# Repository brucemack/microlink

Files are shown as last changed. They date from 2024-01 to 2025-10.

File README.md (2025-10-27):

# Overview

Is it possible to build a full EchoLink&reg; node using a $6 microcontroller?  I'm not completely sure, but
let's find out. The goal of this project is to create the smallest, 
cheapest way to put a radio onto the EchoLink network. If you are new 
to the world of EchoLink please 
[see the official website](https://www.echolink.org/) for complete information. EchoLink is a 
peer-to-peer VoIP (voice over IP) network used to link amateur radio stations across
the Internet.

There are much easier ways to get onto EchoLink. The MicroLink project will only
be interesting to someone who wants to get deep into the nuts-and-bolts of EchoLink/VoIP technology. In fact, you 
should start to question the sanity of anyone who spends this much time building their own EchoLink station. I am a homebrew enthusiast and I try to avoid off-the-shelf software/components where 
possible. This has been a huge learning opportunity.

The system currently runs on a Pi Pico W (RP204, ARM Cortex M0) board. I'm pretty sure it 
could also run on an ESP-32, or possibly an Arduino of sufficient caliber. More experimentation
is needed here.

The software is fully open source. Now that EchoLink is "open," others can experiment with this 
important amateur radio technology. I am currently working on adding support for [AllStarLink](https://www.allstarlink.org/). More 
to follow ...

Here's my production setup at the moment. This station provides EchoLink access to the Wellesley Amateur 
Radio Society repeater (W1TKZ-L) using a Yaesu FT-1900:

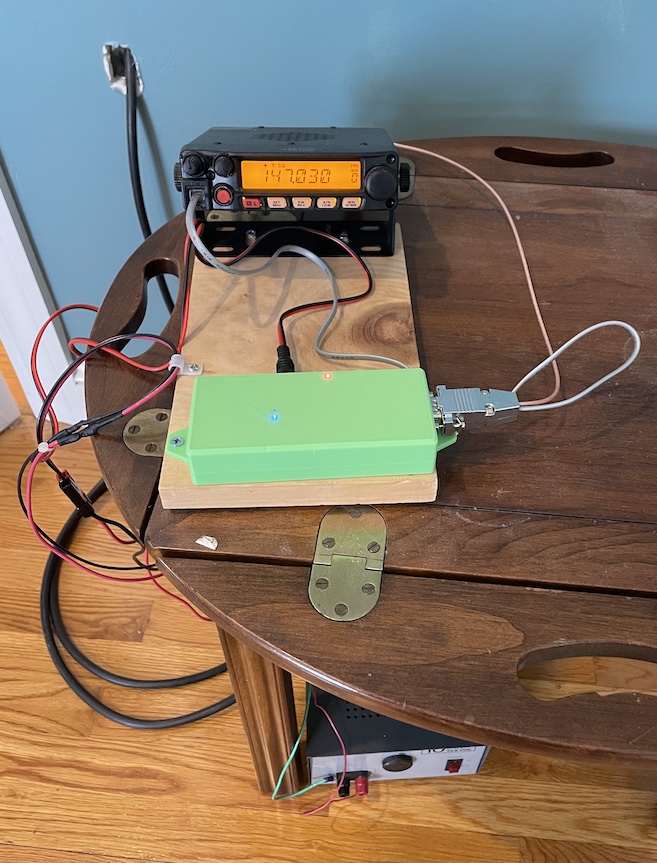
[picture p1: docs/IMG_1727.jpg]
MicroLink Station Picture


The green case contains the MicroLink system. The DB9 connector on the side of the 
case connects to microphone and audio plugs on the FT-1900. A 12V supply powers the radio and the MicroLink interface.
Note that there are no other computers required.  The only
things not shown in this picture are the antenna (on the roof), and the home WIFI network that the Pico W is connected to.  The red LED is the 12V 
power indicator and the blue LED is the 
internet connection status.

Here's a demo video I made of the first bench test:

MicroLink Transmit and Receive Demo (https://www.youtube.com/watch?v=wqWCYG_9o4k)

The microphone/analog section still needs some work. 

Here's what it sounds like over the air:

MicroLink OTA Demo (https://www.youtube.com/watch?v=BMkJOykSL_8)

The official 
PC-based EchoLink client written by Jonathan Taylor (K1RFD) is excellent and is the quickest/easiest way to get on 
EchoLink. [Download it here](https://www.echolink.org/download.htm). There are also versions that run on mobile phones. MicroLink is not a supported part of the EchoLink family 
of products.

I've learned many things about EchoLink during this project. One thing is for sure: Jonathan (K1RFD) 
who created the EchoLink system is an outstanding engineer and we should all be greatly 
appreciative of the work
that he and the rest of the EchoLink team do on behalf of the amateur radio community. Thanks to 
Jonathan for his suggestions/advice along the way.

Huge thanks go to Steve Kondo (K1STK) for providing the mechanical design work
for this project.

Thanks also to Julius Jones (W2IHY), creator of the world-famous EQPlus and other sophisticated audio gear, for his
advice on the audio circuit.

I have a few extra boards which I would be willing to sell
for a reasonable price if someone wanted to try to build 
a station of their own.

I am [good in QRZ at KC1FSZ](https://www.qrz.com/db/kc1fsz) if you have any questions or suggestions.  Or e-mail at bruce at mackinnon dot com.

# Architecture Overview/Parts

My goal was to build a complete station from scratch, with no strings attached to PCs/servers.  

I have made a PCB for 
ease of use with radios (link mode) and/or direct integration with repeaters. Further refinements
of the PCB are in process. The [latest Gerbers are here](hw/ML4/plot/ML4.zip) and 
the [latest BOM is here](hw/ML4/ML4-bom.csv). You can build one yourself.

This project required an in-depth examination of how the EchoLink protocol works. [The notes
I created during this analysis are located here](https://github.com/brucemack/microlink/blob/main/docs/el_supplement.md). The reverse-engineering of the EchoLink protocol was the 
most time-consuming part of the project.

## Current Parts List (HW)

* The main processor is a Pi Pico W (RP2040) development board. This includes WIFI 
connectivity.  $6.00 on DigiKey. 
* A 4G cellular data option is available using a SIM7600 module. *(Not fully working yet.)*
* Audio output generation uses the MicroChip MCP4725 I2C digital-to-analog converter.  $1.27 on DigiKey.
* Audio input sampling uses the integrated ADC in the RP2040.
* Isolation transformers and optocouplers are used to eliminate the need for a common ground 
between the radio and the MicroLink system. The 
radio and the MicroLink circuitry are completely isolated from each other. This helps to reduce digital noise. 
* The radio link is an ~~AZDEN PCS-6000H~~ Yaesu FT-1900 mobile rig.
* When not using the radio:
  - Audio amplification uses the LM4862M 825mW amplifier.  $2.23 on DigiKey.
  - The local T/R key is from Federal Telephone and Telegraph Company (Buffalo, NY), made in 1920.  Priceless.
  - The microphone is an electret condenser with a LVM321 pre-amp and low-pass anti-aliasing 
filter.  The microphone part needs work. The next revision will use a TLV9161 op amp for the 
microphone pre-amp to reduce noise.

Here's a picture of the the current version of the PCB.  

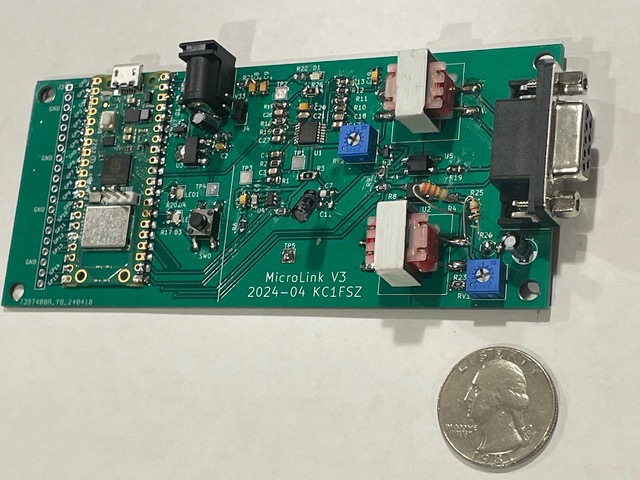
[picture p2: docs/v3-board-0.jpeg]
MicroLink Board V0


This is a picture of the cellular module.  This has passed some initial tests, but is not ready for production yet.

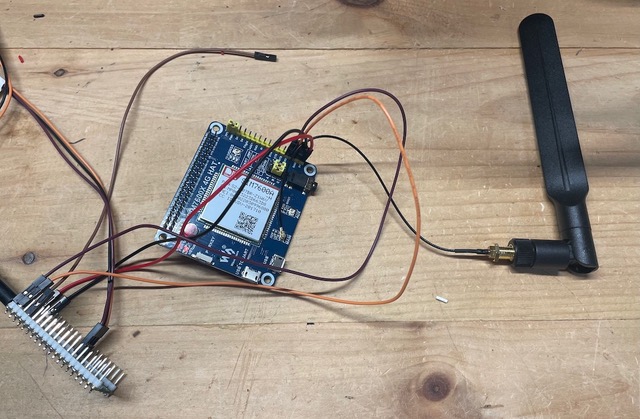
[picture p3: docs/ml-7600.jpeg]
MicroLink Cellular Connection


## Current Parts List (SW)

* The main station firmware is completely homebrew (C++, see GitHub repo).
* The LwIP embedded TCP/IP stack is used for IP connectivity on the Pi Pico W.
* Importantly, audio compression/decompression uses a GSM 06-10 Full Rate CODEC which is homebrew 
in C++. Getting that to work required studying
the European Telecommunications Standards Institute specification for GSM and a lot of testing,
but this was extremely interesting.
* I'm not using the Arduino development environment for this project. The toolchain is 
CMake/GCC/GDB using the Pico W 
SDK. I like this environment a lot. The firmware is flashed via SWD using [openocd](https://openocd.org/).

MicroLink identifies itself using a version string of **0.02MLZ**.

## Analog Schematics

**Microphone Pre-Amp**

Performance audio circuits are not my forte.  The quality is improving with each 
iteration.  This is what I built originally, but a new version using parts with better noise 
specs is in the works. 

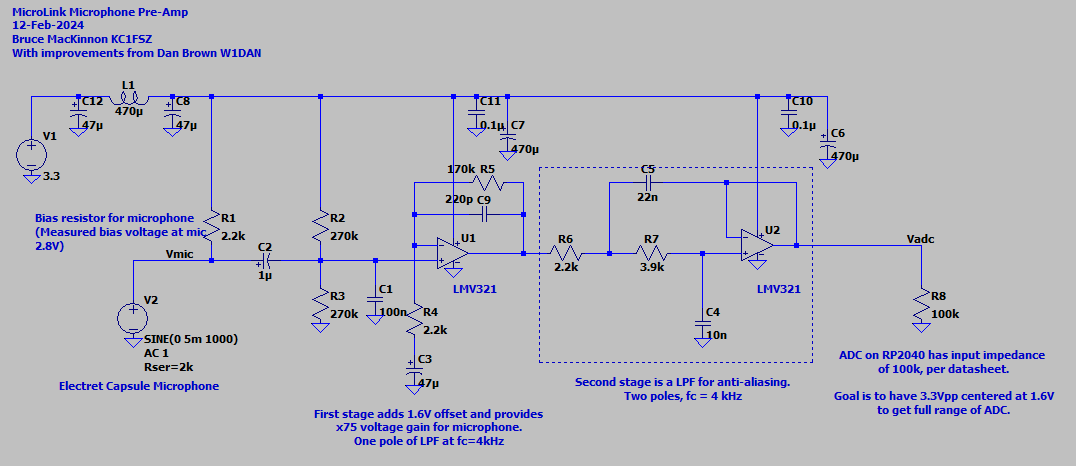
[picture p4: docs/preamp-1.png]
Audio Preamp Schematic


The microphone part will not be used when the radio is integrated. I will probably leave
the speaker/amplifier in for monitoring purposes.

**Audio Input**

This is the circuit used when connecting directly to a radio's AF output (i.e. no microphone). This repeats some of the circuit shown above (but minus the high gain). This also shows
the circuit used for carrier detect (COS). The idea is to boost up the rig's audio 
output (U6) and then compare it to an adjustable threshold (U8).  There is no debounce
in the analog part of the COS circuit - that is all done in software.

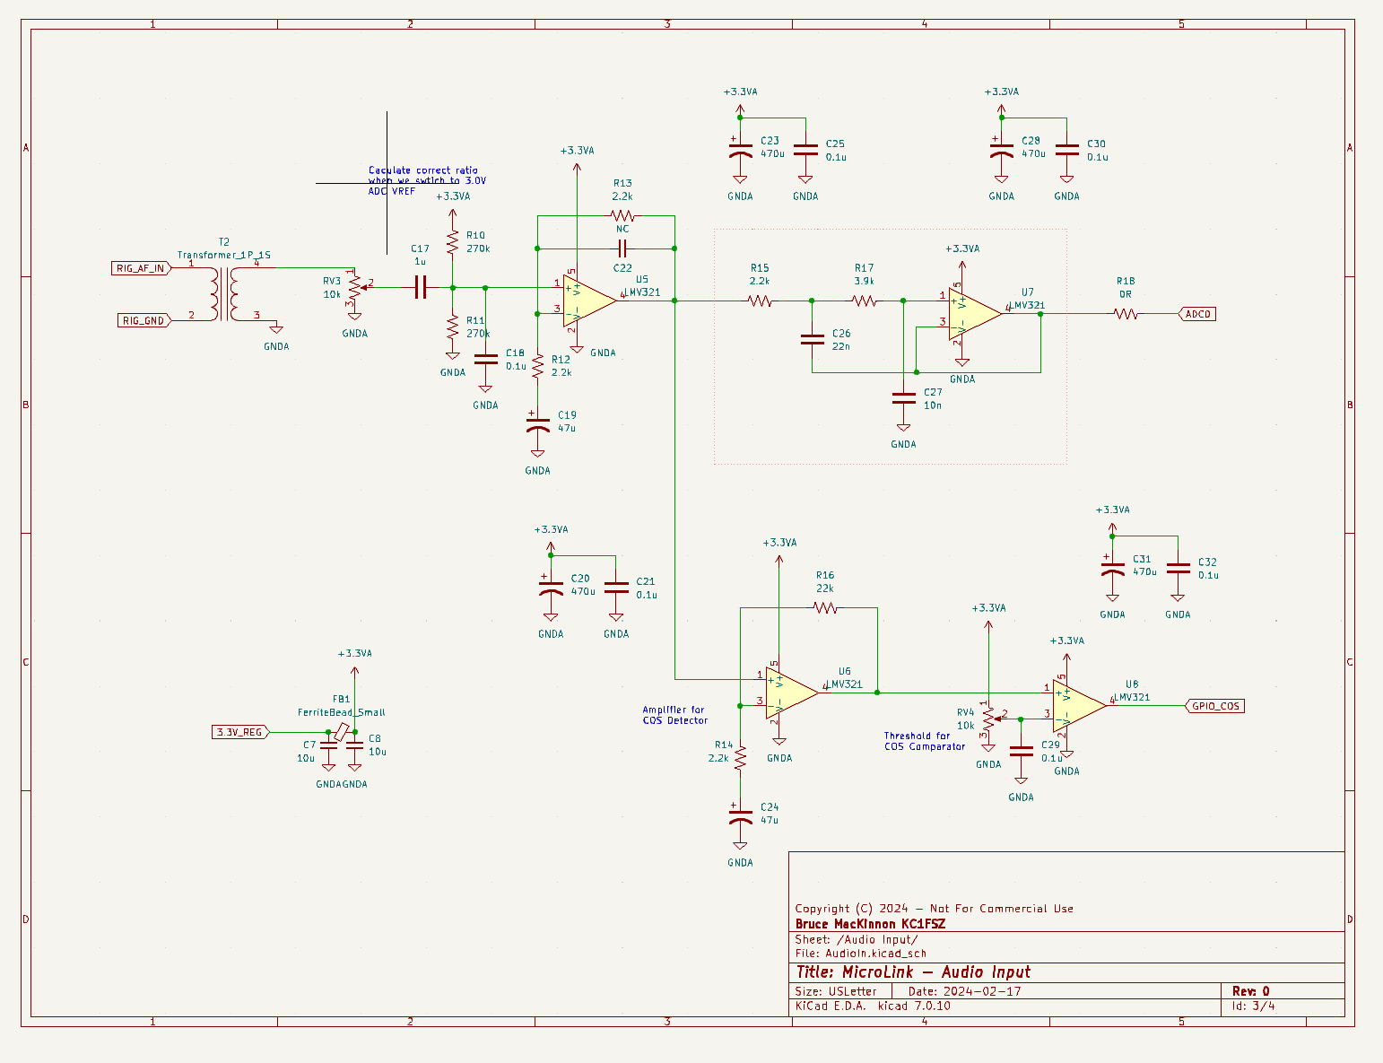
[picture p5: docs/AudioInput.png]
MicroLink Audio Input


**Audio Output**

This is a work in process. The performance on the low end of the audio spectrum is not good yet.

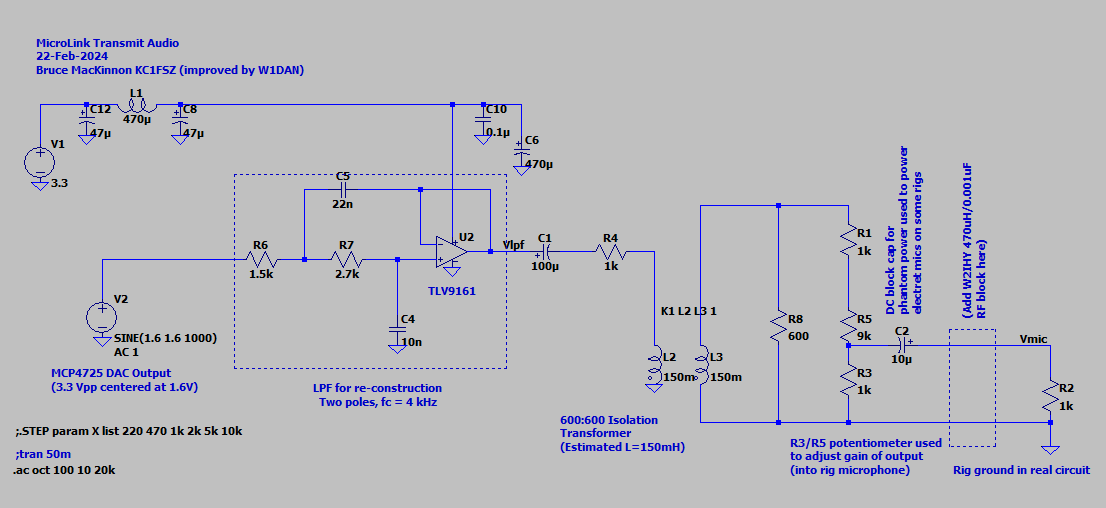
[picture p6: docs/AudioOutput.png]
MicroLink Audio Output


## Cellular Data Interface

I have a working version of the MicroLink system using 4G cellular internet 
connectivity using an SIM7600A cellular module.  The $70 USD breakout 
board for this module [comes from Waveshare and is linked here](https://www.waveshare.com/sim7600a-h-4g-hat.htm).  
The Waveshare module was originally designed to plug into a full Raspberry Pi (NOT A PICO!), hence the 
use of the term "hat," but it is possible to use the module directly via a serial 
interface and there is no technical requirement to connect it to a Raspberry Pi.

I am communicating with the module using their AT command set across a 115,200 baud serial link.  This 
requires a pretty elaborate
state machine to allow bi-directional UDP traffic across a protocol that was originally designed
so support auto-dialing modems.  The Hayes people would be shocked if they saw what people were
doing with AT commands.  I've had good luck getting the SIM7600 to maintain the UDP data rate needed to
support EchoLink.

I am using a pre-paid SIM card from [Mint Mobile](https://www.mintmobile.com/).  It turns out that 
not all cellular providers support the "raw" SIM7600 module.  In fact, it took a few conversations
with their help desk to get them to activate my SIM card.  The Mint Mobile activation website wants you to select
what kind of phone you have (i.e. iPhone, Android, etc.) and apparently "homebrew EchoLink station"
isn't a valid choice in their system yet.  Someday ... But after some back-and-forth, they activated my 
SIM and within 30 seconds the "link" LED started flashing and I was on the Internet!

The only bad thing about Mint Mobile is that they don't appear to allow inbound UDP traffic 
into this module. Or at least I've not figured that out yet.  ARRGG! This required the use of a 
TCP proxy to handle the traffic in/out of the cellular module.  I've not documented this part
yet because I am still hoping to eliminate this component.

### Notes on MVNOs

Mint Mobile is an example of what is called a "Mobile Virtual Network Operator," or MVNO for short.
The real mobile cellular infrastructure is built/run by Verizon, T-Mobile (including the remnants of 
Sprint), AT&T, and US Cellular. 
All of the other low-cost "providers" are essentially renting bandwidth from the big firms. In the
case of Mint Mobile, they are using the T-Mobile network.

One interesting facet of the MVMO service is that the traffic is de-prioritized vs. the "real" 
carrier's traffic.  So during congested times you might find that T-Mobile service is 
better than Mint Mobile's.  You get what you pay for.

The mechanics of the prioritization is managed through the assignment of QCI levels.  According to one 
article I saw, T-Mobile uses QCI 6, 7, 8, and 9 for their normal consumer plans.   *The lower numbers 
have higher priority.* T-Mobile uses 6 (the best) for their "real" customers (i.e. pre-paid subscribers) and 7 for 
Mint Mobile.  Interestingly, T-Mobile branded hot-spots run on level 9 (the worst).

## Notes on SNTP

MicroLink will update its internal time using an NTP server.  The main value of this is to 
ensure that the timestamps on the internal log messages are correct.

The SNTP message protocol is quite simple.  The request is 68 bytes, mostly zeros.  The non-zero
bytes are as follows:

* Byte 0: (binary) 00 100 011.  This denotes an SNTPv4 client request.
* Byte 1: zero
* Byte 2: 6
* Byte 3: 0xec
* Bytes 12-15: (ascii) UKNO
* Bytes 40-43: The client's current time in seconds since the Epoch, big endian format.

The response that comes back has been observed to be around 52 bytes, although this may
vary in some situations.  The important information in the response is:

* Byte 0: (binary) 00 100 100.  This denotes an SNTPv4 server response.
* Bytes 40-43: The server's current time in seconds since the Epoch, big endian format.

## Enclosure

Steve K1STK designed and fabricated a great enclosure on his 3D printer.  Here's what the PCB
looks like with the case:

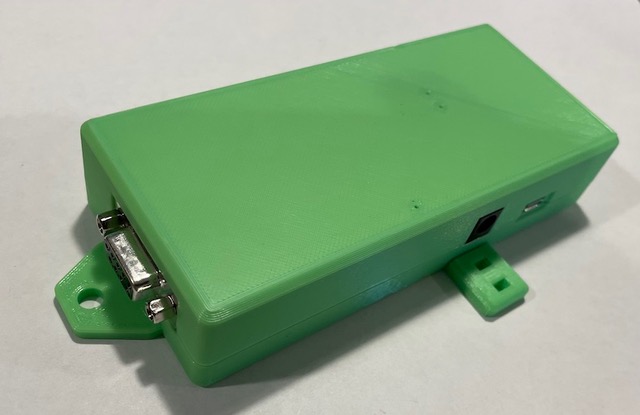
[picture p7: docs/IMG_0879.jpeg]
Enclosure


## Speeds and Feeds

* The standard audio sample rate for GSM-FR/EchoLink is 8 kHz at 12-bits of resolution.
* The audio CODEC creates/consumes one 640 byte packet every 80ms.  One of these packets is moved 12.5 times per second.
* It takes the RP2040 about 3ms to decode a 33 byte GSM frame into PCM.
* It takes the RP2040 about 7ms to encode a 160 sample PCM frame into GSM.
* The UDP data rate needed to sustain audio quality is 
approximately 14,000 baud.
* The RP2040 runs at 125 MHz. Only one of the two processors is used at this time.
* The DAC runs on an I2C bus running at 400 kHz.
* The voice prompts (all letters, numbers, and a few words) take up about 40K of 
flash. The audio is stored in GSM full-rate format for efficiency.
* Current flash size (used) is ~650,000 bytes.
* The RP2040 communicates with the SIM7600 4G cellular module at 115,200 baud.  This is 
about 10x the theoretically-required bandwidth to maintain a single channel.

# User Guide

## Serial Command Interface

(More detail to follow)

    reboot
    status 
    log
    tone
    dropall
    add [callsign]
    drop [callsign]

Configuration commands - using during initial setup:

    set addressingserver [EchoLink addressing server hostname: ex: naeast.echolink.org]
    set callsign [your call]
    set password [your password]
    set fullname "[your full name]"
    set location "[your location]"
    set wifissid "[yourssid]"
    set wifipassword [your password]
    set hardcos [0 or 1.  Enables or disables hardware carrier detect. Defaults to 0.]
    set coson [COS debounce ms during off->on transition. Defaults to 10.]
    set cosoff [COS debounce ms during on->off transition.  Defaults to 400.]
    set costhreshold [noise power floor used to decide when COS is detected]
    set adcoffset [value that is added to the raw ADC value.  Used to center the DC bais at 2048.]

## DB9 Connector Pinout

The MicroLink device provides a DB9 (female) connector with the following pinout:

Top row, left to right (looking into device connector)
* Pin 5: Audio out (rig microphone in)
* Pin 4: PTT out (rig PTT in).  This pin will be pulled to rig ground to key the rig.
* Pin 3: COS in (rig COS out). Pull to rig ground to indicate RX carrier. This is an optional connection and is only used when hardware carrier detect is available.
* Pin 2: NC
* Pin 1: Audio in (+) (rig speaker out)

Bottom row, left to right (looking into device connector)
* Pin 9: Rig Ground
* Pin 8: Rig Ground
* Pin 7: Rig Ground
* Pin 6: Audio in (-) (rig speaker out)

NOTES:
* Audio in (+) and audio in (-) are connected to the primary side of an audio isolation transformer.

# Technical/Development Notes

## GSM CODEC

I implemented my own fixed-point audio compression/decompression CODEC for the GSM 0610 Full Rate 
protocol [by following the specification here](https://www.etsi.org/deliver/etsi_en/300900_300999/300961/08.01.01_60/en_300961v080101p.pdf).  The coding scheme is the so-called **Regular Pulse Excitation - Long Term 
prediction - Linear Predictive Coder**, generally referred to as "RPE-LTP."  This standard was developed
as part of the modernization of the European mobile phone system in the late 1990s and is a good
balance between efficiency, quality, and compactness. 

The European Telecommunications Standards
Institute (ETSI) publishes a comprehensive set of test vectors containing known audio streams (PCM) and the 
corresponding GSM encoding. I have used that test data to validate that my CODEC is 100% complaint.

The smallest/cheapest microcontrollers lack hardware support for floating-point, so I built my CODEC using
fixed point (Q15) math. 

## Regarding Audio Smoothness

One of the most difficult challenges I had with this project was getting audio
that was "smooth" in both directions. This stuff is probably obvious to people
who are well versed in the state-of-the-art of VoIP.  Here
are a few points that will help anyone getting into this.

1. Accurate/consistent clocking of the audio chain is essential.  GSM uses
an 8 kHz clock, which means we need an audio sample once every
125 microseconds. I know this seems hard to believe, but inconsistencies
in this clock can be "heard."  This is where hardware timers with efficient
interrupt service architectures are important. The highest priority activity
of the microcontroller should be the creation/consumption of an audio sample
every 125 uS **exactly** - everything else in the system has some leeway.
2. An EchoLink receiver gets an audio packet _approximately_ every 80 ms.  Each 
packet contains
4 frames that each represent exactly 20 ms of audio. Finally, each frame contains 160
samples which each represent exactly 125 uS of audio.  From point #1 above, we already 
know that the timing of the 160 samples within each frame is critical.  However, 
we also need ensure that the 20 ms frames are played continuously 
**without the slightest gap between them.** This gets into an interesting problem
because the frames are streaming across the busy internet (not to mention 
low-cost WIFI hardware) and may be subject to 
small timing inconsistencies. There is simply no way to ensure that an EchoLink packet
will arrive every 80 ms. Sometimes the gap might be 81 ms, sometimes 79 ms, etc. 
This variability is known as "jitter" and it is a common issue in VoIP systems.
The fix is simple: we need to delay/buffer the audio generation in the receiver 
slightly to give ourselves a margin of error to accumulate packets. The
MicroLink system keeps a buffer of 16 audio packets and holds back the start 
of audio generation (after squelch break) until the buffer is half full.  This 
means that the receive path is delayed by around 8 x 80 ms *above and beyond* any delay
in the Internet itself. Experimental work is ongoing to make this adaptive
so that the delay is minimized.  Of course if the buffer empties out (i.e. several
slow packets in a row), all bets are off.
3. A MicroLink node can have up to four "remote" (i.e. internet based) stations
connected at the same time. Think of this as a mini-conference. In the extreme 
case (four users connected), the 
inbound audio packets from the station who is speaking need to be routed 
back out to the other three listening stations AND be sent to the CODEC/DAC for 
local radio transmission. Since the CODEC is relatively time-consuming, it is 
important to *reflect the audio packets back out onto the internet to the 
listening stations before dealing with the GSM decode needed for the local radio
link.* This will ensure maximum parallelism and smooth audio for all 
stations involved.

## Regarding the Pi Pico ADC

Two important things that make a difference for audio noise performance. Note
that these comments are relevant when using the Pi Pico board as-is. The 
rules will be different if using the RP2040 chip directly.

Per Pico datasheet:

> For much improved ADC performance, an external 3.0V shunt reference, such as LM4040, 
can be connected from the ADC_VREF pin to ground. Note that if doing this the ADC range 
is limited to 0-3.0V signals (rather than 0-3.3V), and the shunt reference will draw 
continuous current through the 200Ω filter resistor (3.3V-3.0V)/200 = ~1.5mA.

Per Pico datasheet:

> AGND is the ground reference for GPIO26-29, there is a separate analog ground plane 
running under these signals and terminating at this pin. If the ADC is not used or 
ADC performance is not critical, this pin can be connected to digital ground.

## Regarding Transmitter Duty Cycle

When using MicroLink as a bridge to a repeater system via a radio link, be careful about the 
duty cycle limitations of the bridge radio you are using.  The W1TKZ-L system uses an AZDEN mobile
rig that certainly wasn't designed for 100% key down.  

During "normal" repeater use this isn't a problem because the link radio is only keyed 
when a remote EchoLink user is speaking - that's no different from using the link
radio directly.  However, if more a complicated configuration is used (examples: linking 
two repeater systems together, joining a repeater to a conference server, etc.) things can become
problematic if the link radio is required to be keyed constantly to transmit the activity 
happening on the "other" repeater or in the conference.

If you have a transmitter than can be 
keyed for long periods of time then this won't be an issue. But if not, the MicroLink system supports a 
configurable duty cycle limit (defaults to 50%).  Once
the link radio has been keyed for more than 50% of the time in any 5 minute interval
the radio is un-keyed and allowed to rest. 

## Notes Regarding Interface with MCP4725

The RP2040 has no DAC and the MCP4725 is cheap and plentiful. This could certainly be 
done with a fancier audio CODEC, but we'll think about that later.

As mentioned previously, it is important to deliver audio very smoothly, and with 
as little CPU overhead as possible.  To that end, we are leveraging the TX FIFO 
on the I2C channel to quickly write to the I2C bus without any blocking.  

This is a bit tricky because there are two completely independent data formats
that need to work together:
* The RP2040 I2C format (really the DW_apb_i2c format) that is manifest in the 
format of the IC_DATA_CMD register.  Aside from the "normal" byte of data in this 
register, we have extra bits that control the START/STOP/RESTART cycles of the 
I2C bus.  Each write to the I2C_DATA_CMD register contributes both 
data bits and control bits.
* THe MCP4725 I2C format.  This is a 12-bit DAC, but it's not as simple as
justing writing 12 bits to it.  There are other control bits in the message
being sent to the MCP4725 on the I2C bus and those need to be configured
properly.

The DAC I2C writes are done inside of the same interrupt service routine that performs 
the ADC read. This interrupt is set to run at exactly 8kHZ by setting the ADC 
FIFO depth to 1. The ADC and DAC are both running constantly, regardless of whether
the system is transmitting or receiving.

### Bus Protocol

There are some different ways of using the I2C bus but we're using the 
simple way since speed is not a big issue.  What we really care about 
is consistency. Each audio sample will be transmitted
on the I2C bus using a normal START-address-data-STOP sequence. There are fancier 
things you can do on the I2C bus involving restarts but we don't need that
for our audio bandwidth requirements.  

The MCP4725 also provides some choices to improve efficiency.  The "fast mode" 
described in section 6.1.1 of [the datasheet](https://ww1.microchip.com/downloads/en/devicedoc/22039d.pdf) 
allows you to perform continuous data writes without addressing cycles. We don't 
need that for the 8kHz application (at least I don't think we do).

In the "slow" mode, the MCP4725 needs the regular I2C address byte followed
by three data bytes.  Actually, the first of the three data bytes is more 
like a command byte from the perspective of the MCP4725. So the complete
sequence will need to look like this:

* -> I2C START
* -> Address Byte (MCP4725 "first byte")
* <- I2C ACK
* -> Data Byte 0 (MCP4725 "second byte")
* <- I2C ACK
* -> Data Byte 1 (MCP4725 "third byte")
* <- I2C ACK
* -> Data Byte 2 (MCP4725 "fourth byte")
* <- I2C ACK
* -> I2C STOP

The START and STOP steps are commanded by bits in the RP2040 I2C_DATA_CMD word
so they don't require distinct writes to the TX FIFO. Likewise, the address
byte is generated automatically on start.  In order to achieve 
the sequence above we'll need to make three distinct data writes into the I2C
TX FIFO for each audio sample.

Combining the RP2040 datasheet figure 72 and the MCP4725 figure 6-2, we
can determine that the three writes will look like this:

    0 0 0 | 0   1   0   x   x   0   0   x 
    0 0 0 | d11 d10 d09 d08 d07 d06 d05 d04
    0 1 0 | d03 d02 d01 d00 x   x   x   x

These writes are happening into the LSB end of the I2C_DATA_CMD
register (i.e. data bits [10-0]).  Bits [31-11] are not used and
will be set to zero.  The x's in the illustration above show 
where the MCP4725 has don't-cares.  These will be set to zero.

## Notes on DTMF Detection

The rules for DTMF are standardize by the International Telecommunications Union (ITU). The relevant 
standards documents are located here:
* [ITU Q.23](https://www.itu.int/rec/dologin_pub.asp?id=T-REC-Q.23-198811-I!!PDF-E&lang=e&type=items)
* [ITU Q.24](https://www.itu.int/rec/dologin_pub.asp?lang=e&id=T-REC-Q.24-198811-I!!PDF-E&type=items)

The most important details from the standards document:

* There are a total of 16 possible symbols.  Each symbol is made up of two tones: one from the "low group"
and one from the "high group."
* The "low group" frequencies are: 697, 770, 852, 941 Hz.  These are on the rows of the keypad.
* The "high group" frequencies are: 1209, 1336, 1477, 1633 Hz.  These are on the columns of the keypad.
* Even though the phone/radio keypad only has 3 columns, there is a an "extra" column in the spec
for A/B/C/D.
* Transmission must be within 1.8% of frequency standard to be recognized.  This means that the received 
frequency can be +/- 1.8% from expectation, or 3.6% wide.  
* If we apply the 3.6% rule to the highest frequency, we get a resolution bandwidth of 58.788 Hz (1633 * 0.036).
* Distortion products (e.g. harmonics) must be -20dB below the fundamental.
* There are rules around the relative powers of the two tones that make up the symbol. In the US, 
the high group frequency power level may be up to 4 dB more or 8 dB less than the low group frequency 
power level for the symbol to be considered valid.  In the TELCO lingo, this difference is known as
"twist" and it is expressed in dB.  Positive twist means that the higher frequency is louder.
* Timing requirements are as follows.
  - A symbol must be transmitted for at least 40ms.  Symbols shorter than 23ms must be rejected.
  - The gap between symbols must be at least 40ms.

### Implementation Notes

* 23ms is 184 samples at a sampling rate of 8 kHz.  We will round this to 20ms (160 samples) since it 
is conveniently the same size as a GSM frame.
* 40ms is 320 samples at a sampling rate of 8 kHz
* A block of 136 samples is required to achieve 58.788 Hz resolution at a sampling rate of 8 kHz.  If
we use more than 136 samples then the resolution will become finer than 58 Hz and we'll need to compute
the power in more than one bucket - so we don't want to do that.
* So for each 160 sample frame we will use the latest 136 samples and ignore the other 24.  Close
enough.
* We will look for symbols that last more than two 160 sample frames.
* We will look for noise periods that last more than two 160 sample frames to consider the symbol valid
(i.e. the pause).
* Algorithm notes:
  - For each 160 samples.
  - Evaluate power at all 8 frequencies.
  - Compare the power of all 16 pairs by summing powers at each intersection.
  - Look to see if any pairs stand out by at least +20dB.  If so, that is the candidate pair.
  - Check the twist on the candidate pair to make sure it falls within the +4dB -> -8dB standard.
  - Compute the harmonic power for both frequencies in the pair and make sure it falls below the -20dB standard.
  - If all tests pass, then do the 40ms duration checks.
* The +4dB level is equivalent to x ~1.58 linear.  Testing a/b > ~1.58 is the same as testing 4a/b > ~6.
* The +8dB level is equivalent to x ~2.5 linear.  Testing a/b > ~2.5 is the same as testing 4a/b > ~10.

## Building the Link Station

This is the official binary that runs in production. 

(These notes are not comprehensive yet.)

    git clone https://github.com/brucemack/microlink.git
    cd microlink
    git submodule update --init 
    mkdir build
    cd build
    export PICO_BUILD=1
    cmake -DPICO_BOARD=pico_w ..
    make link-main-2
    # At this point you'll have a link-main-2.uf2 that can 
    # be dragged onto a Pico W module. This is done by 
    # holding down the BOOTSEL button while powering on 
    # and then dragging/dropping the UF2 file onto the mass
    # storage device.
    #
    # Or the link-main-2.elf can be flashed onto the board
    # via the SWD port using a Raspberry Pi programming feature:
    openocd -f interface/raspberrypi-swd.cfg -f target/rp2040.cfg -c "program link-main-2.elf verify reset exit"
    #
    # Or, more directly, using the RPi Debug/Programming Probe:
    ~/git/openocd/src/openocd -s ~/git/openocd/tcl -f interface/cmsis-dap.cfg -f target/rp2040.cfg -c "adapter speed 5000" -c "rp2040.dap.core1 cortex_m reset_config sysresetreq" -c "program link-main-2.elf verify reset exit"

## Building Tests on Windows (CYGWIN)

(These notes are not comprehensive yet.)

    git clone https://github.com/brucemack/microlink.git
    cd microlink
    git submodule update --remote
    mkdir build
    cd build
    cmake ..
    make <target>

## ESP32 AT Firmware Notes

(No longer used)

    esptool.py --chip auto --port /dev/ttyUSB0 --baud 115200 --before default_reset --after hard_reset write_flash -z --flash_mode dio --flash_freq 40m --flash_size 4MB 0x0 /home/bruce/Downloads/ESP32-WROOM-32-V3.2.0.0/factory/factory_WROOM-32.bin

## Test Commands

    # Used to receive UDP packets
    netcat -u -l 5198
    # Used to send UDP packets.  The printf command supports non-printable.
    printf 'Hello\rWorld' | nc -u -w1 192.168.8.210 5198

    # Login test
    printf "lKC1FSZ\254\254xxx\rONLINE0.02MLZ(08:11)\rWellesley, MA USA\r" | nc -w 10 naeast.echolink.org 5200

    # SIM7600 open TCP socket in transparent mode:
    ATE0;+CIPMODE=1;+NETOPEN;+CIPOPEN=0,"TCP","54.89.121.215",8100

# Rig Integration Notes

## SA818 Transceiver Module

The SA818 is an inexpensive 1W transceiver module that is available for about
$10 USD. There are VHF and UHF versions. I have tested 
the MicroLink system using this module and it works fine. [Here is a short demo video](https://www.youtube.com/watch?v=QV-Jfr8qjco&feature=youtu.be).

I've created [notes for this module on my blog](https://mackinnon.info/2025/10/07/sa818-module.html).

* [SA818 Module Datasheet](https://d3s5r33r268y59.cloudfront.net/datasheets/2570/2014-06-03-08-38-29/SA818%20Datasheet.pdf)
* [SA8181 Module Programming Guide](https://www.qsl.net/ta2ei/devreler/sa818/SA818%20programming%20manual.pdf)
* [A good reference to another project](https://hamvoip.org/hamradio/818_transceiver_module/)

The connection is straight-forward. Here's a picture of the module with interface
wires attached:

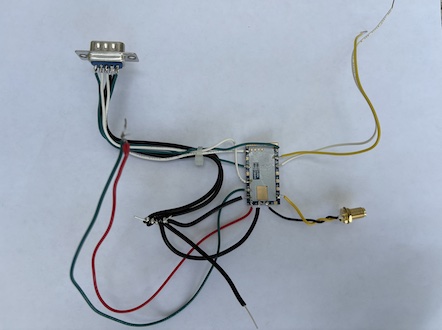
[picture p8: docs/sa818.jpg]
SA818


* On the top left there's a DB9 connector that interfaces audio in/out PTT/COS 
to MicroLink. 
* The yellow/white wires on the top right are the serial TX/RX needed to 
send commands to the SA818. 
* The SMA connector on the bottom right connects to an antenna.
* The wires on the bottom left are the +5V connectors needed to power the module.

I'm currently working on a more direct integration between MicroLink and this
radio module.

## Yaesu FT-1900

This rig was installed in October of 2024 to address an ongoing problem with occasional local QRN. The RF squelch on the original (AZDEN) rig was opening sporadically, particularly during the evening hours. The advantage of the more modern Yaesu rig is that it supports CTCSS tone squelch.

[Here is the manual for the rig](https://www.yaesu.com/downloadFile.cfm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).

### Connectors

The rig has a normal 3.5mm audio output jack on the back. This is used to drive the audio input on the MicroLink box.

The FT-1900 ships with a Yaesu MH-48 microphone.  The rig as a 6-pin RJ12 modular microphone connector on the front. **NOTE:** Although this looks similar to the RJ45 connector used on many (ICOM) rigs, it is actually the smaller connector size commonly used for telephones.  Unlike the telephone RJ11 connector that uses 4 pins, the RJ12 connector uses 6 pins.

The pinout is as follows, looking into the front of the rig and counting from left to right:

* Pin 6 - PTT
* Pin 5 - Microphone Input
* Pin 4 - Ground for microphone and PTT
* Pin 3 - +8V
* Pin 2 - Mic SW1
* Pin 1 - Mic SW2

Pins 6, 5, and 4 are used for the MicroLink interface.  Pins 3, 2, and 1 are not used.

### Carrier Detect

There is no carrier detect output on the rig.  MicroLink is run in soft-COS mode with this radio and we've not had any propblems.

### Other Configuration

We have saved the repeater frequency/split/tone/power level in one of the rig's memory slots so that the correct configuration is used automatically following a power cycle. It appears that the rig remembers the last memory slot that was selected after power off/on.

## Baofeng BF-F8HP HT

### Connectors

* 3.5mm Jack
  - Tip - NC
  - Ring - Rig mic in, MicroLink audio out
  - Sleeve - PTT when pulled to ground
* 2.5mm Jack
  - Tip - Rig speaker+ out, MicroLink audio in
  - Ring - Rig ground
  - Sleeve - Rig ground

### Carrier Detect

This has been discussed at length in other venues.  The method of detecting the 
receive carrier depends on the radio you are using.  Unless you are willing 
to crack it open, there is no explicit carrier detect "signal" on the Baofeng HT.  My 
integration with this rig just listens for noise on the audio output line
and triggers accordingly.  That seems to work just fine.  See the schematic for 
details.

# KiCad Project Notes

The latest (ML4) design was created using KiCad 9.

There are a few symbols/footprints in the hardware design that are not 
included in the standard KiCad libraries. These parts are included 
in my own library located in GitHib. Please clone my [GitHub project called kicad-library](https://github.com/brucemack/kicad-library) to get access to these 
additional parts.

There are a few steps that need to be taken to allow KiCad to find the
custom parts:

* From the schematic editor, use Preferences ... Manage Symbol Libraries. Add the 
location of the symbol-library-1 from the kicad-library repo.
* From the schematic editor, use Preferences ... Configure Paths. Add a new
name "USER_3DMODEL_DIR" and set the path to the location of the 3d directory 
from the kicad-library repo.
* From the PCB editor, use Preferences ... Manage Footprint Libraries. Add the 
location of the bruce-footprints from the kicad-library repo.

# Manufacturing/Assembly 

At the request of Abdullah S21AF I've updated the design files to make 
assembly using parts from [LCSC Electronics](https://www.lcsc.com/) easier. This involved
a few tweaks to the PCB to allow the use of more available parts. I've updated
the schematics to include the LCSC part numbers. Please 
see the ML4 version of the hardware design files.

There is now an official BOM file that includes LCSC part 
numbers: [see the CSV file here](hw/ML4/ML4-bom.csv).
Most of the parts listed in the BOM are available on LCSC. Here are some notes on some 
parts that didn't appear on LCSC when I checked:

* J1, the DB9 radio connector. This is an important part since there are mechanical
and enclosure dependencies. The official design uses a **A-DF 09 A/KG-T2S** from Assmann
Components. These are in stock at DigiKey using part number AE10921-ND.
* SW0, the SMT push-button switch. This part is less important since the firmware
doesn't make use of it at the moment. At some point in the future it may be used
for configuration or diagnostics.  The official design uses a **TS04-66-55-BK-160-SMT**
from Same Sky. These are in stock at DigiKey using part number 2223-TS04-66-55-BK-160-SMT-ND
.
* U7, the voltage reference. This is used to improve the performance of the ADC inside
of the Pico.  According to the [Pico Datasheet](https://datasheets.raspberrypi.com/pico/pico-datasheet.pdf) in section 4.3: "... for much improved ADC performance, an external 3.0V shunt reference, such as LM4040, can be connected from the
ADC_VREF pin to ground." So this influences audio quality, but I've not measured it
so I don't know if it's significant.

The Gerber files for the ML4 version of the PCB are [located here](hw/ML4/plot/ML4.zip).
**NOTE:** As of September 2025 I have not yet manufactured/tested this version
of the PCB. 

## Microphone Interface in ML4

It's been tricky to interface to the audio input of some radios. Sometimes this 
needs to be "line level," but most of the time the audio is being fed into 
the microphone input. Different radios expect very different audio levels,
but microphone levels are very small compared to what is coming out of 
the MicroLink circuit.

To improve flexibility, a resistive pi-attenuator is provided **using through-hole
resistors**. THT parts make it easier to adjust the attenuation in the field.
There is also a pot that can be used for fine adjustment. Here's the schematic:

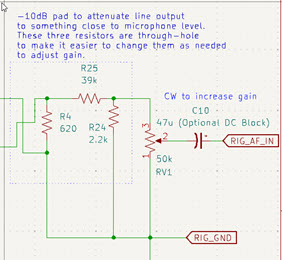
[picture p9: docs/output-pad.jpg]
Output Pad


From my experience a -10dB pad gets the audio level into the right range 
for a microphone level and the pot can be used to dial in the proper level.

The optional DC blocking capacitor (C10) can be installed if your radio provides
a DC bias voltage
on the microphone cable as is often the case when powering an electret/condenser
microphone. If you don't use the DC block then a short should be installed instead.

# AllStarLink Notes (Work In Process)

So far everything on this page has been related to 
EchoLink. I have made good progress on AllStarLink
support.  At the moment the ASL firmware is separate
from the EL firmware but I will merge them once
things are working well.  More to follow later.

* A possible audio interface: https://www.repeater-builder.com/products/usb-rim-lite.html
* Docs on Linux audio testing: https://iotbytes.wordpress.com/connect-configure-and-test-usb-microphone-and-speaker-with-raspberry-pi/

# References

* Official EchoLink Site: https://www.echolink.org/
* Pi PICO Stuff
  - [Pi Pico Board Datasheet](https://datasheets.raspberrypi.com/pico/pico-datasheet.pdf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..)
  - [RP2040 Datasheet](https://datasheets.raspberrypi.com/rp2040/rp2040-datasheet.pdf)
  - [Hardware Design with RP2040](https://datasheets.raspberrypi.com/rp2040/hardware-design-with-rp2040.pdf)
  - [Analysis of Pico ADC](https://pico-adc.markomo.me/)
  - Timers: https://vanhunteradams.com/Pico/TimerIRQ/SPI_DDS.html
  - Flash Write: https://github.com/raspberrypi/pico-examples/blob/master/flash/program/flash_program.c
* Pi PICO W Stuff
  - [Pi Pico W Datasheet](https://datasheets.raspberrypi.com/picow/pico-w-datasheet.pdf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.)
  - [Connecting to the Internet with the Pico W](https://datasheets.raspberrypi.com/picow/connecting-to-the-internet-with-pico-w.pdf)
  - [Pi Pico CYW43 Driver Docs](https://cec-code-lab.aps.edu/robotics/resources/pico-c-api/group__cyw43__driver.html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)
  - [Light Weight IP - LwIP API Documentation](https://www.nongnu.org/lwip/2_1_x/index.html)
* ESP-32 
  - [AT Command Reference](https://docs.espressif.com/projects/esp-at/en/latest/esp32/AT_Command_Set/index.html)
* SIM7600 Cellular Module
  - SIM7600 module AT Command Reference: https://www.waveshare.net/w/upload/6/68/SIM7500_SIM7600_Series_AT_Command_Manual_V2.00.pdf
  - SIM7600 module application notes: https://www.waveshare.com/w/upload/4/4b/A7600_Series_TCPIP_Applicati0n_Note_V1.00.pdf
  - [SIM7600 Hardware Design Guide](https://edworks.co.kr/wp-content/uploads/2022/04/SIM7600_Series_Hardware_Design_V1.08.pdf)
  - [The "hat" I am using](https://www.waveshare.com/sim7600a-h-4g-hat.htm)
* Windows Audio Related: 
  - http://www.techmind.org/wave/
  - http://midi.teragonaudio.com/tech/lowaud.htm
  - http://soundfile.sapp.org/doc/WaveFormat/
* SNTP 
  - [RFC 2030](https://www.rfc-editor.org/rfc/rfc2030.txt#:~:text=SNTP%20uses%20the%20standard%20NTP,or%20high%2Dorder%2C%20position.)
* Components
  - [Transformer that W2IHY is using](https://www.digikey.com/en/products/detail/triad-magnetics/TY-304P/242649)
  - [MCP4725 DAC](https://ww1.microchip.com/downloads/en/devicedoc/22039d.pdf)
  - [Audio Amp](https://www.ti.com/lit/ds/symlink/lm4862.pdf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)
  - [TLV9161 opamp suggested by Dan](https://www.ti.com/lit/ds/symlink/tlv9161.pdf?ts=1707743140015&ref_url=https%253A%252F%252Fwww.google.de%252F)
  - [NTE3086 Optoisolator, 8-DIP](https://www.nteinc.com/specs/3000to3099/pdf/nte3086.pdf)  
  - [EL357M Optoisolator, plentiful on JLCPCB](https://jlcpcb.com/partdetail/EverlightElec-EL357N_C_TA_G/C29981#:~:text=Datasheet-,Download,-Source)
  - [NCP1117 LDO Voltage Regulator used in circuit](https://www.onsemi.com/pdf/datasheet/ncp1117-d.pdf)
* Rig Integration
  - [Microphone Connector Reference](https://www.secradio.org.za/zs6src/secfiles/pdf/mic_soc_info.pdf)
  - [Baofeng Cable Reference](https://ics-ctrl.com/cable-pinout-baofeng-ht/)
* Analog/Audio
  - [Good article from Analog Devices about noise in mixed-signal systems](https://www.analog.com/media/en/analog-dialogue/volume-46/number-2/articles/staying_well_grounded.pdf)
  - [Good article about ferrite beads, and power supply noise more generally](https://northcoastsynthesis.com/news/the-truth-about-ferrite-beads-will-shock-you/)
  - [Detailed article about audio/rig integration](https://www.zs2ez.co.za/Soundcard/Soundcard.htm)
  - [Linear Predictive Coding of Speach](https://course.ece.cmu.edu/~ece792/handouts/RS_Chap_LPC.pdf)
* DSP Related
  - [A useful article on implementing the Goertzel Algorithm in fixed point](https://remcycles.net/blog/goertzel.html)
  - [Very good article on Fixed Point Math by Randy Yates](http://www.digitalsignallabs.com/downloads/fp.pdf)
  - [Another Randy Yates paper on fixed point FIR](http://www.digitalsignallabs.com/downloads/fir.pdf)
  - [DSP Text Book](https://brianmcfee.net/dstbook-site/content/intro.html)
* DTMF Related
  - [Official ITU Q.23 Standard](https://www.itu.int/rec/dologin_pub.asp?id=T-REC-Q.23-198811-I!!PDF-E&lang=e&type=items)
  - [Official ITU Q.24 Standard](https://www.itu.int/rec/dologin_pub.asp?lang=e&id=T-REC-Q.24-198811-I!!PDF-E&type=items)
  - [A TI application note on DTMF detection](https://www.ti.com/lit/an/spra096a/spra096a.pdf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)  
* Other
  - [Analog Devices Filter Wizard](https://tools.analog.com/en/filterwizard/)
  - https://www.purevpn.com/what-is-vpn/protocols/openvpn
  - https://en.wikipedia.org/wiki/OpenVPN
  - https://www.analog.com/media/en/technical-documentation/application-notes/an-1368.pdf
  - [Information about Ferite Beads from Altium](https://resources.altium.com/sites/default/files/2022-05/Guide%20to%20Using%20Ferrite%20Beads%20in%20a%20PCB.pdf). 
  - MD5 Implementation: https://www.cs.cmu.edu/~jcl/linux/seal/md5.c
  - Audio Transformer: https://electronics.stackexchange.com/questions/648953/what-does-the-impedance-value-of-audio-transformers-specifically-mean-in-terms
  - Very interesting audio processing stuff: https://www.repeater-builder.com/tech-info/audio-processing.html
  - [Ceramic vs Tantalum Capacitors in LDOs](https://www.ti.com/lit/an/slva214a/slva214a.pdf)
  - [DB9 Connector](https://www.digikey.com/en/products/detail/assmann-wsw-components/A-DF-09-A-KG-T2S/1241800)
  - [5.5mm power Connector](https://www.digikey.com/en/products/detail/cui-devices/PJ-102AH/408448)

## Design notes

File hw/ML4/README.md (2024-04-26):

This file contains the details for the version 3 (ML3) of the MicroLink hardware.
This is the first version that has a real enclosure so we are paying more attention
to mechanical detail.

# Enclosure Considerations
## Connectors That Penetrate the Enclosure
* DC power connector - 5.5mm jack, male center pin positive.
* Signal/audio connector - DB9, female.
## Indicators That Penetrate the Enclosure
* Three indicator LEDs - D1 Red, D3 blue, D4 green
## Thermal 
* The 3.3V LDO gets warm so there should be airflow in that vicinity

# Change Log (V3)

## R1 (17-Apr-2024)
* Moved Pi Pico W daughter card up by 1.00mm.
* Moved clear area under Pi Pico W daughter card up by 0.75mm.
* Moved J2 (5.5mm power jack) up by 2.5mm.
* Moved J1 (DB9) right by 2.5mm.

## During Build (25-Apr-2024)
* Changed R5 and R5 to 2.2K
* Changed R17, R20, R22 to 100 (LED)

DRC Notes:
* There are 12 warnings: "Silkscreen clipped by board edge."

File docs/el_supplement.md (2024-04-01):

# EchoLink Protocol Information 

[By Bruce MacKinnon, KC1FSZ](https://www.qrz.com/db/kc1fsz)

As far as I can tell the EchoLink&reg; protocol isn't officially documented. Maybe I'm missing something. This page attempts 
to fill in the details. My 
notes are based on examinations of EL packet captures and a review of the various open source EchoLink implementations in GitHub. I 
am not affiliated with the EchoLink team and I have no inside information.  Please take these notes for what they are 
worth - just one random ham's observations.  Do your own research.

_NOTE from 20-Feb-2024: I later received some very helpful comments/input from the EchoLink creator Jonathan Taylor (K1RFD), 
and he helped to fill in some places where I lacked visibility.  Please don't assume that 
this document has been fully reviewed and/or endorsed by Jonathan, but I will credit him in some of the 
new sections below._

_NOTE: Thanks also to Scott Miller (N1VG) who filled in a few details.  Scott's firm (Argent Data Systems, Inc.)
sells an interesting piece of EchoLink hardware called EchoBridge.  Check it out._

Notes like these may make it possible for others to start tinkering around in EchoLink space. If you do so, **please proceed
with caution.** We all love EchoLink but none of us pay when we use it, so I can only assume that there are many volunteer hours 
going on behind the scenes. The last thing anyone needs is an accidental denial-of-service incident on the EL network. I
would strongly encourage anyone attempting to implement their own EchoLink hardware/software to reach out to the 
EchoLink team first to discuss your idea.

The information on this page was used to homebrew a working EchoLink&reg; station called MicroLink.  [The code/information 
is here](https://github.com/brucemack/microlink).

If you have any questions/corrections/concerns on this 
document please contact me directly (good in QRZ). Don't bother the real 
EchoLink team since they have plenty to do running a massive 
telephony network and they don't need to be spending time correcting my errors.

Here are links to some GitHub projects that I've studied:

* Echolib: https://github.com/sm0svx/svxlink/tree/master/src/echolib
* TheBridge: https://github.com/wd5m/thebridge-1.09
* Asterisk Interface: https://github.com/hwstar/astsrc-1.4.23-pre/blob/master/asterisk/channels/chan_echolink.c

The EL protocols draw heavily on VoIP technology, specifically the RTP and RTCP standards. Documentation of these two standards helps a lot, but should not be taken too literally as the EL standards do things a bit differently in a few places. Some related standards docs 
that I would recommend looking at:

* RFC 3550 (RTP): https://datatracker.ietf.org/doc/html/rfc3550
* RTCP Background: https://en.wikipedia.org/wiki/RTP_Control_Protocol
* RFC 8852 (RTCP SDES): https://datatracker.ietf.org/doc/rfc8852/
* GSM 06.10 Full-Rate: https://www.etsi.org/deliver/etsi_EN/300900_300999/300961/08.00.01_40/en_300961v080001o.pdf

## High-Level Protocol Flow Notes

As has been documented in several places, there are two distinct protocol flows that make up the EL system:
* A client/server interaction with one of the EchoLink Addressing Servers (TCP port 5200).
* A peer-to-peer "QSO" interaction between EchoLink nodes:
  - UDP port 5198 is used to carry audio traffic (and a bit of out-of-band texting) using the RTP protocol.
  - UDP port 5199 is used to carry session control information using something very similar to the RTCP protocol.

The topic of EchoLink Proxies will be put aside for now - more on this later.

Before getting into the details I'll provide my understanding of the high-level message flow that is used
during an EL QSO.  EchoLink is a peer-to-peer technology so it's probably not correct to think about "clients" 
and "servers" for most in this flow.  Instead I will use the terms "Station A" and "Station B," assuming that 
Station A is the originator of the call. From tracing a QSO using the official EchoLink client I can see the 
following flow pattern:

1. Station A logs into the network by interacting with the EchoLink Addressing Server over TCP port 5200.  This 
step may not need to happen on every QSO since the logged-on status persists for some time.
2. Station A requests the directory information from the Addressing Server to determine the 
status of the target node and its current IP address.
3. Station A sends an RTCP SDES packet with the identification information to Station B on the RTCP port, **but using 
the socket that is bound to the RTP port on the local side!**.  I suspect we need to originate data using both local-side 
UDP ports in order for routers/firewalls to forward return traffic from Station B back to Station A on both ports.  This is related to dynamic firewall capability known as [Stateful Packet Inspection](https://en.wikipedia.org/wiki/Stateful_firewall) and/or [UDP Hole Punching](https://en.wikipedia.org/wiki/UDP_hole_punching).
4. Station A sends the same message again to the RTCP port of Station B using the socket that is bound to the RTCP port.
5. Station A sends an oNDATA packet to the RTP port of Station B.
6. Station A appears to wait at this point.  If nothing happens after 5 seconds then a retry happens by returning to step #3.
7. Station B uses the call-sign provided in the RTCP SDES message sent in step 4 to contact
the EchoLink Addressing Server and validate that the Station A user is authorized to use the network. (I'm told that Station B also 
maintains a cache of recently-validated stations to reduce the number of validation calls.  Presumably there is a reasonable
time-to-live on this caching mechanism so that invalid callsigns will not be allowed to stay on the network for long.)
8. Station B sends an RTCP SDES packet on the RTCP channel.
9. Station B sends an oNDATA packet on the RTP channel.
10. Station A sends the same RTCP SDES packet from step #3/#4.  (I suspect this is actually the first of a repeating cycle that will continue throughout the life of the connection.  This would be highly relevant for stateful routers/NATs/firewalls in order 
to keep two-way UDP traffic flowing.)
11. Station A sends an oNDATA packet on the RTP channel from step #5.  This text can be changed during the QSO.  (I suspect this is actually the first of a repeating cycle that will continue throughout the life of the connection.)
12. At this point RTP audio packets are moved in both directions.
13. Periodically (every ~10 seconds) both stations send RTCP SDES and RTP oNDATA packets to each other, presumably for keep-alive. The
text in the oNDATA packets can be changed during the course of QSO as needed.  The official EchoLink client displays
the latest oNDATA message on the bottom of the screen.
14. At the end of the QSO, Station A sends an RTCP BYE packet.

## EchoLink Addressing Server Protocol

> [!IMPORTANT] 
> The EchoLink Addressing Server is a shared resource maintained by 
> a team of volunteers. Use it carefully.

Things start off with an exchange with the EchoLink Addressing Server. The Addressing Server topology is described in detail in the 
official EL documentation so we won't repeat this information unnecessarily. The important detail is that 
there are ~4 active Servers that synchronize with each other. An EL node can interact with any one of the servers.  Known servers are naeast.echolink.org, nasouth.echolink.org, servers.echolink.org, backup.echolink.org.

Nodes initiate the interaction by opening a TCP connection to the EL Server on TCP port 5200.  Data will flow in both 
directions on this connection. The protocol used on this TCP connection appears to be ad-hoc and is entirely 
unrelated to VoIP. The protocol is request/response and appears to be "disconnect delimited" - meaning that 
the server sends a response to the client and then disconnects. This is similar to HTTP/1.0.

The server interaction accomplishes a few things:

* Allows a node to authenticate itself and to tell the rest of the network about its status. Your callsign must 
be pre-validated for this to work. You use your password to authenticate securely, or leverage the challenge-response login protocol for improved security.
* Provides the ability to download the entire directory of EchoLink nodes.
* Provides the ability to authenticate the status of a single callsign for the purposes of approving
inbound connection requests.

Nodes can advertise any one of three statuses on the network:
* ONLINE
* BUSY
* OFF

Connecting to the EchoLink Server, authenticating, and advertising 
an ONLINE or BUSY status puts the node in "logged in" state for 
approximately 7 minutes. This is significant since other nodes on the network will check this status before accepting a QSO from a 
requesting station. Essentially, the EchoLink server is providing a free authentication service for the rest 
of the peer-to-peer network. There must be a lot of volunteer hours behind the scenes for this to work 
reliably.

### Notes About Password Security

There appear to be at least three login message formats supported by the EL Addressing Server:
* Old/insecure, wherein the password is transmitted to the server in plain text.
* Newer/more secure, uses a challenge-response protocol.
* New/secure, where the server provides an RSA public key and the client encrypts its authentication request.  

### Login Message Format (Original, less secure)

The messages used to authenticate and establish the ONLINE or BUSY status are the same.  Packet format is as follows:

* One byte: 0x63 (lower-case l)
* N bytes: The callsign
* Two bytes: 0xAC 0xAC
* N bytes: The password
* One byte: 0x0D 
* N bytes: The word "ONLINE" or "BUSY" depending on the desired status
* N bytes: A string identifying the client/version
* One byte: Open parenthesis
* 5 bytes: The local time in HH:MM format, following a 24-hour clock.
* One byte: Close parenthesis
* One byte: 0x0D 
* N bytes: The location string
* One byte: 0x0D 

Later it was discovered that one more field is also needed for conference servers:
* N bytes: E-mail address
* One byte: 0x0D 

Here's an example of an ONLINE packet:



* Note that there are no headers, length fields, etc.
* Tokens are delimited by 0xac 0xac or 0x0d.

The server response is generally something like "OK 2.6" with no header/delimiters/etc. In fact,
I think you'll get an OK response even if the password was bad, which is good for security
reasons.

#### Notes on Status

> Per Scott (N1VG): BUSY status indicates that the node has reached connection limit and can't
accept more.  OFF-V is used to indicate that you're logging off.

### Challenge-Response Login Flow

_(NOTE: Thanks to Jonathan K1RFD for the information here. I have added some more detail around message formats
and have captured some example messages.)_

This login flow avoids the need to send your password in the clear.  The request is in the "Extended Format" that uses name-value pairs rather than positional parameters.  Optional parameters can 
be omitted completely. The tag and the value for each parameter are separated by a colon and a 
space (0x3a 0x20).  Parameters are separated using a \n (0x0a) character.  A double \n must be sent to end the 
message.  Please see the network capture to understand the exact format.

There are four steps required in the login sequence.

#### Step 1: Client Sends Initial -LOGIN

The client starts off by making a TCP connection on port 5200 just like all the other Addressing Server commands.  Once the connection opens,
a message with the following forward is sent by the client:

* -LOGIN
* callsign: _(callsign)_ (Upper case, between 3 and 10 characters in length, valid ITU format)
* status: _(status)_ (ONLINE or BUSY, see above for information on statuses)
* client-addr: _(address)_ (This is optional and is used if running through a Relay; IP address in dotted-decimal format)
* rtp-port: 5198
* rtcp-port: 5199
* client-version: _(version string)_
* location: _(location string)_ (Only ASCII-7 characters, max length 30)
* local-time: _(time)_ (HH:MM, exactly 5 characters)
* code-page: _(code-page)_ (Optional)
* os-version: _(os-version)_ (Optional)
* sw-tag: _(sw-tag)_ (An arbitrary, persistent string that identifies the client, max 22 characters, like a GUID)

Here's an example of a valid request:

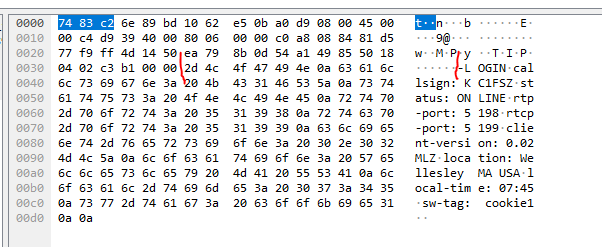
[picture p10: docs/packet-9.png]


There are some additional TCP header bytes that can be disregarded.  The actual message starts at the red mark.

#### Step 2: Server Sends LOGIN-RESULT

The server sends back a challenge in this format:

* LOGIN-RESULT
* result: challenge (There are also error results if the original request was bad)
* challenge: _(challenge string)_ (This is the crucial piece of information since it is needed to form the next request from the client)

As usual, the server disconnects after sending the response.

Here's an example of a valid response:

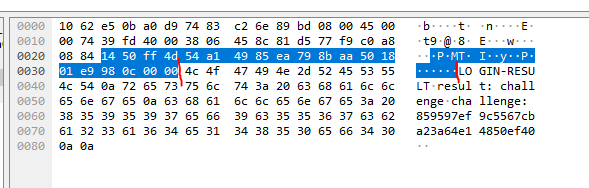
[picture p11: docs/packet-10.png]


There are some additional TCP header bytes that can be disregarded.  The actual message starts at the red mark.

#### Step 3: Client Sends Second -LOGIN

The client re-connects and sends back a second -LOGIN request that is exactly the same as the first 
(see above), but includes an additional parameter that contains a special hash.  Presumably this needs to happen 
reasonably quickly since the challenge string should have some time-dependent information in it to prevent replay attack.

The hashed password is computed by concatenating the upper-cased password with the _(challenge string)_ that was returned in step 2, computing the MD5 hash of this combined string, and then converting the result of the hash to a hex string.

So the response has this additional parameter:

* hashed-password: _(hashed-password)_ (Which is a 32-character representation of the 128 bit MD5 hash value)

Here's an example of a valid request:

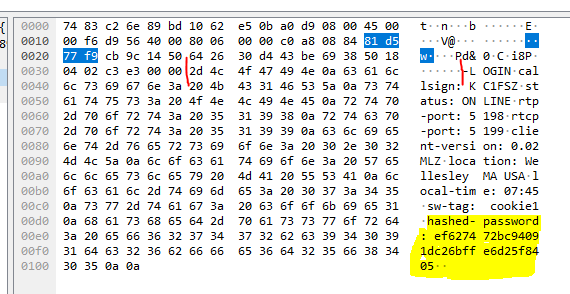
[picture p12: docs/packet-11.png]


There are some additional TCP header bytes that can be disregarded.  The actual message starts at the red mark.

The added parameter with the hashed challenge/password combination can be seen at the end of the message.

#### Step 4: Server Sends Second LOGIN-RESULT

Finally, the server responds with success or failure as one parameter:

* LOGIN-RESULT
* result: success (Or other failure reasons are bad-password, barred, not-validated, bad-data)

As usual, the server disconnects after sending the response.

Here's an example of a response after a successful login:

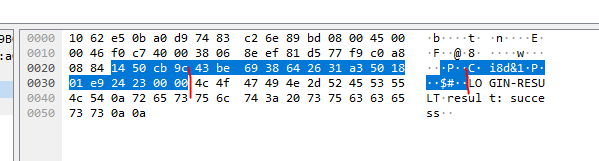
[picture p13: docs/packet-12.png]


There are some additional TCP header bytes that can be disregarded.  The actual message starts at the red mark.

### OFF Status Message Format

The message used to set the OFF status has a slightly different format, presumably because no authentication
is required to disconnect from the network. (NOT RIGHT, NEED RESEARCH HERE.)

(Format notes to follow)

### Full Directory Request Message Format

The full directory request is very simple: connect and send a single "s" to the server.  

### Full Directory Response Message Format

A large response will be returned from the server. The result is tokenized using 0x0a characters (\n).

* The first token consists of three @ symbols.
* The second token contains the total number of entries in the directory response.
* Thereafter, a repeating series of four tokens for each directory entry, discussed below.

Here is an example of the start of the response:



* The @@@ token is underlined in red.
* The entry count is underlined in green (6250 here).

Each entry is made up of these four tokens, in order:

* Callsign
* Location/Connection status as follows:
  - Location 
  - Open square bracket (0x5b)
  - Status (ON or BUSY)
  - One space (0x20)
  - The time the last status was reported in UTC HH:MM format
  - Close square bracket (0x5d)
* The EchoLink-assigned node number
* The IP address of the node in dotted format (xxx.xxx.xxx.xxx)

There is no special delimiter between entries.  The next entry starts
immediately after the final 0x0a of the previous entry.



* The red marker shows the start of an entry.
* The green marker shows the end of an entry (after the final 0x0a delimiter).
* In this example the callsign is KD0PGV-L.
* The station is ONLINE since 14:08.
* In this example the IP address is 72.206.115.254.

There is nothing unique about the end of the entire response.  

### Single Callsign Authentication (Verify) Request Message Format

This request provides an efficient way for a node to check the status of an individual 
callsign **without requesting the entire directory.**  This would be used for repeater/link/conference
nodes in order to validate a QSO request from a new peer.  Stations should use this to 
reduce the load on the EchoLink Server.

The format of the request is as follows:

* One byte: 0x76 (v)
* N bytes: The callsign
* One byte: 0x0d (\n) delimiter
* N bytes: The IP address of the inbound request being validated
* One byte: 0x0d (\n) delimiter

There are no other headers or delimiters.  The client sends this message and waits.

Here's an example of a request:



* There are some TCP header bytes at the start of this illustration that are not relevant.
* The red mark indicates the beginning of the request.

### Single Call Authentication (Verify) Response Message Format

The server response is very simple.  Either:

* A one byte 0x31 (1) indicating that the callsign is authorized.
* A one byte 0x30 (0) indicating that the callsign is not authorized.

There are no other headers or delimiters.  The server disconnects immediately after sending this response.

Since the IP address is included in the request, it is likely that the server checks this too as an 
added security check.

### Extended Verify Request Message Format

_(NOTE: Thanks to Jonathan Taylor K1RFD for providing me with the information on this additional 
feature.)_

This request provides an efficient way for a node to obtain the IP address and status of an individual 
callsign **without requesting the entire directory.**  This would be used by a client that wants to make a request
for information about a specific station without pulling down the entire EchoLink directory. This can also be used to refresh
cached directory information. This feature is extremely useful for constrained stations that may not have the 
memory and/or bandwidth to manage a multi-megabyte copy of the entire EchoLink directory. Stations should 
use this to reduce the load on the EchoLink Server.

The format of the request is as follows:

* One byte: 0x56 (This is a capital V).
* N bytes: The callsign
* One byte: 0x0d (\n) delimiter

There are no other headers or delimiters.  The client sends this message and waits for a response.

### Extended Verify Response Message Format

If the station callsign provided is valid and online the server response is as follows:

* Callsign
* One byte: 0x0d (\n) delimiter
* Location/Connection status as follows:
  - Location 
  - Open square bracket (0x5b)
  - Status (ON or BUSY)
  - One space (0x20)
  - The time the last status was reported in UTC HH:MM format
  - Close square bracket (0x5d)
* One byte: 0x0d (\n) delimiter
* The EchoLink-assigned node number
* One byte: 0x0d (\n) delimiter
* The IP address of the node in dotted decimal format (xxx.xxx.xxx.xxx)
* One byte: 0x0d (\n) delimiter

If the station callsign is not valid or is not online the server responds with one byte 0x30 (0).

There are no other headers or delimiters.  The server disconnects immediately after sending this response.

Here's an example:

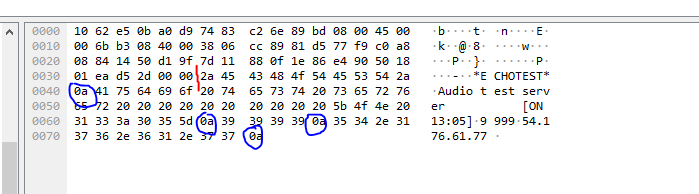
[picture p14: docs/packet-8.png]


* In this example there are some TCP header bytes that are not relevant.  The red mark indicate the 
beginning of the message content.
* There are exactly four 0x0a delimiters marked in blue.

## EchoLink QSO Protocol

In this section we talk about the more traditional VoIP part of EchoLink. There are a few different packet formats that 
are used to conduct a peer-to-peer QSO.  Broadly speaking you need to understand four packets:

* The RTCP traffic (port 5199)
  - SDES Packets
  - BYE Packets
* The RTP traffic (port 5198)
  - oNDATA Packet
  - Audio Packets

Each are described in their own section below.

### Common RTCP Packet Format that Applies to SDES and BYE

[This wiki](https://en.wikipedia.org/wiki/RTP_Control_Protocol) has some relevant background. Each RTCP packet contains an 8-byte header:

* Byte 0 [7:6] - Version, which is always 3.
* Byte 0 [5] - Padding, which is always set to 0.
* Byte 0 [4:0] - Reception report count, which is always set to 0.
* Byte 1 - Packet type.  Always set to 0xC9 (201 = "Receiver Report" per official documentation).  
* Bytes 2-3 - Packet length as a 16-bit integer, most significant byte first.  This is always set to 1.  I suspect that this 1 is 
telling us that there is one "chunk" embedded in the top-level RTCP message (either an SDES or BYE).
* Bytes 4-7  - An SSRC id, represented as a 32-bit integer with the most significant byte first.  From looking at packet captures 
and reviewing TheBridge code, it doesn't appear that this number has significance,
except that it is unique/consistent.  
  - For packets generated by the standard EchoLink client the value is set to zero all the time. 
  - For packets generated by the iPhone client the value is set to zero all the time. 
  - TheBridge code generates a non-zero SSRC, but I'm not sure it has any 
significance, other than needing to be consistent.  In TheBridge code we see a comment
 ([conference.c line ~1330](https://github.com/wd5m/thebridge-1.09/blob/master/src/conference.c#L1329C7-L1329C63)) that 
 says _"We'll never login, set a phoney NodeID so SF will run."_

The RTCP packets are always padded **at the end** in order to achieve a packet length that is evenly divisible by 4.  The 
very last byte of the (padded) packet contains the number of bytes that were added to achieve the padding goal 
(and that byte is considered to be part of the pad).  One strange thing is that a four-byte pad is added if 
the message was already divisible by 4, presumably to avoid corrupting the original message by writing the "0" at 
the last position.  The valid packet endings look like one of these:

* 0x01
* 0x00 0x02
* 0x00 0x00 0x03
* 0x00 0x00 0x00 0x04

Immediately following the RTCP header we get another level of message format which depends on the purpose
of the packet. There are two cases, described in the next two sections.

### RTCP SDES Packet Format

The normal RTCP header is followed by an SDES-specific header with 8 bytes:

* Two bytes: 0xE1 0xCA which seem to indicate that the packet contains SDES information (the top-level PT field notwithstanding).
* Two bytes: packet length information represented as a 16-bit integer with the most significant byte first.  This length covers
the entire packet and is represented as the number of 4-byte chunks **minus 12 bytes of header**.  So, for example, if the total 
length of the packet is 112 bytes we'd see (112 - 12) / 4 = 25 or 0x00 0x19 hex.
* Four bytes: The SSRC represented as a 32-bit integer with the most significant byte sent first.  This is alway zero for the 
official EchoLink client but non-zero for the ECHOTEST station (see below).

The content of this packet is a repeating pattern of variable-length items.  Each item contains an "SDES item type" 
that indicates its semantic meaning.

Each repeating pattern contains:

* One byte: SDES item type.
* One byte: item length information. It's possible for this length to be zero, in which case there is no item content.
* N bytes: Variable-length content, without any special termination.

The termination of this repeating pattern requires some specific handling.  From 
the [RFC 1889](https://www.freesoft.org/CIE/RFC/1889/23.htm) documentation: _"The list of items in each chunk is terminated 
by one or more null octets, the first of which is interpreted as an item type of zero to denote the end of the list, and 
the remainder as needed to pad until the next 32-bit boundary. A chunk with zero items (four null octets) is valid but useless."_

The SDES item types are documented in the RFC (per [TheBridge source code in rtp.h](https://github.com/wd5m/thebridge-1.09/blob/master/inc/rtp.h#L88). 
However, it doesn't look like EchoLink is following this standard strictly.  It doesn't matter - just follow the EchoLink 
pattern and things will work fine.

Here are some notes about how each of these items is sent by the official EchoLink client.  From what I can tell, EL 
is using the SDES item type its own way and the official SDES definitions shown in the RFC document are not relevant.

The items appear in this order:

* A type 1 item is sent with the value "CALLSIGN"
* A type 2 item is sent that contains the FCC callsign (padded with some spaces) and the user's real name.  So in my case I see:

        KC1FSZ         Bruce MacKinnon

* A type 3 item is sent with the value "CALLSIGN" again.
* A type 4 item is sent with the ASCII (HEX) representation of the SSRC identifier being used by the EchoLink client for this session.  This would always be exactly 8 characters since the SSCR is a 32-bit integer.
* A type 5 item with the value "PING" has been observed in RTCP traffic when the official EchoLink client is being used in SysOp mode (i.e. repeater/link).  More on this below.
* A type 6 item with a text description of the client version.  EchoLink is currently sending "E2 3 121".
* A type 8 item with an unknown meaning. The values sent by the official EchoLink client are consistent over time.  I see these bytes 
being sent (in hex), which spells "<01>P5198." This is likely a reference to the UDP port number that is used for RTP traffic.

        01 50 35 31 39 38

* A type 8 item provides an indication of whether DTMF is supported by the node. The values sent by the official EchoLink client are consistent 
over time. I see these bytes being sent (in hex), which corresponds to ASCII "D0":

        01 44 30

> Per Scott (N1VG): The EchoLink Windows client has a DTMF keypad for sending tones over the link.  This feature is 
enabled if the remote end has PRIV D1 set.  PRIV D0 disables the keypad. Note that nothing prevents the user from passing
DTMF tones of their own creation. PRIV 'dpx1' seems to indicate full duplex, supported only by theBridge.

Finally, padding may be added to fill up to the next 4-byte boundary (per SDES termination requirement), and then the entire packet is padded again following the RTCP requirement.

This visual provides a helpful reference:

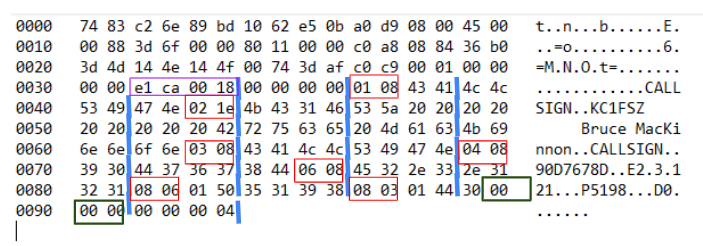
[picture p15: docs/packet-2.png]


Some notes:

* There are some UDP header bytes at the start of this illustration that are not relevant.
* The purple box contains the RTCP-SDES header.  You can think of this as a "sub-header" inside of the overall RTCP packet.
* The red boxes show the SDES item type and length.
* The blue bars represent 32-bit boundaries.  This is helpful because it shows how the *last* item is being padded up to the next 
boundary (none of the other items do this).  The extra padding is shown in the green boxes.  The 32-bit boundaries don't 
seem to matter otherwise.
* The entire packet is padded with 4 bytes, with an 04 written in the very last position of the packet, per RTCP standard.

Here are some notes about how the ECHOTEST station is using the fields in the RTCP packet.

The ECHOTEST station is using a non-zero SSRC in the RTCP header that looks like this:

        0x00 0x00 0x27 0x0F

The next (SDES) header is consistent with the description above:

        0xE1 0xCA 0x00 0x16 0x00 0x00 0x27 0x0F

Then begins the repeating pattern:

* One byte: SDES item type
* One byte: length the item
* N bytes: Variable-length item content, without any special termination.

The ECHOTEST station is sending the following items at connection initiation:

* A type 1 item is sent with the value "CALLSIGN"
* A type 2 item is sent that contains some descriptive text as follows:

        *ECHOTEST*  (Conference  [7]) CONF

* A type 3 item is sent with the value "CALLSIGN"
* A type 4 item with the time in HH:MM format.
* A type 6 item with the version of the software like this:

        thebridge V1.06

The usual mechanics of padding out the last item and then padding the entire packet 
is also observed.

#### PING Packets using RCRP SDES Format

(To be filled in)

These are returned by the remote side, so this might be part of the protcol, presumably to measure round-trip time.

### RTCP BYE Packet Format

The official EchoLink client sends this RTCP packet when the user presses the disconnect 
button to drop the connection.  

A standard RTCP header is sent which matches the RTCP-RR format. It's a bit strange because the official RTCP document 
suggests that the "packet type" (PT) field be set to 0xCB to indicate a BYE packet, but EchoLink doesn't seem to 
work like that.  No worries - just follow the EchoLink standard.  The EchoLink BYE packet has the usual 0xC9 value and the BYE is encoded in the body of the 
RTCP packet (immediately after the RTCP header).

Following the RTCP header, these 8 bytes are sent:

* Two bytes: 0xe1 0xcb (to indicate the bye)
* Two bytes: 0x00 0x04 which are likely length-related.  This likely follows the (total length - 12) / 4 convention.
* Four bytes: the SSRC

So my test looks like this:

        0xE1 0xCB 0x00 0x04 0x00 0x00 0x00 0x00

This is followed by some text of unknown meaning.  The standards documents suggest that this contains some arbitrary text 
with the "reason for leaving."  The text is preceded by a one-byte length. The EchoLink client sends: "jan2002" in 
this reason text.

And then the usual mechanics of padding out the entire RTCP packet to a 32-bit boundary is observed.

Here is an example capture:

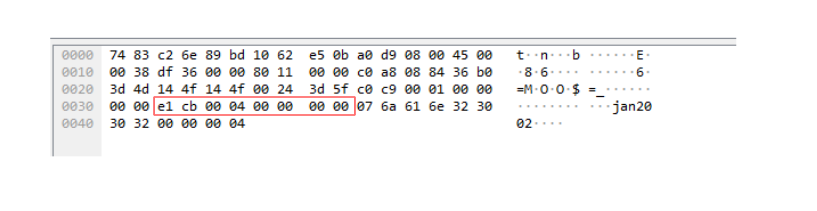
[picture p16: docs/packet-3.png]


* There are some UDP header bytes at the start of this capture that are not relevant.
* The red box shows the 4-byte BYE identifier (+length) followed by what is presumed to be a 4-byte SSRC identifier.
* The "07" is the length of the text.
* You can see that 4 bytes were added to the end of the packet.

### RTP oNDATA Packet Format

This looks like an out-of-band text messaging feature.  These packets are sent across the same UDP socket as the 
RTP audio packets. These are sent by the client every ~10 seconds which suggests a keep-alive mechanism.

These packets do not conform to any RTP standard format and contain no header information.  They appear to be plain text with 
tokens delimited with 0x0d (\r).  The text is also null terminated.  The official EchoLink client also includes SSRC information at the end of the packet, but the ECHOTEST station does not.

Per Jonathan K1RFD: if the first byte of this text is '\r', OR the first four characters are "CONF", it's a 
"station information" text packet, meant to be displayed to the client, and potentially updated during the 
QSO.  Any other prefix denotes a "text chat" message, to be displayed in a different area.

Here's an example message with the first byte is a \r (0x0d):

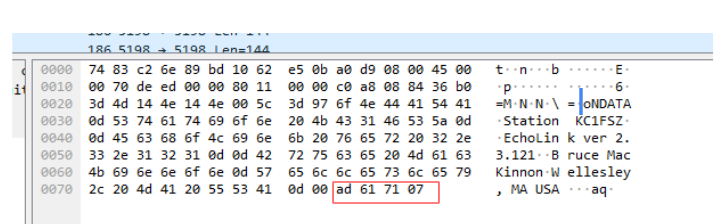
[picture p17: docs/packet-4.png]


* The blue bar indicates the start of the packet.  The bytes before are the UDP/IP header which can be ignored for this analysis.
* The official EchoLink client sends 4 additional bytes **following the null termination of the free text.**  These four bytes 
contain the SSRC, encoded in a 32-bit integer with the most significant byte sent first.

Here's what it looks like when a station sends a chat message. In this case, the station typed "test" into the chat window.  Notice that the first byte is 
not a \r in this case:



### RTP Audio Packet Format 

Each RTP packet is 144 bytes in length.

Each RTP packet contains a 12-byte RTP header. The use of this header is very close to the "official" RTP specification. We number the bits from LSB [0] to MSB [7], which is different from some other standard documents.

* Byte 0 [7:6] - Version, which is always 3.
* Byte 0 [5] - Padding, which is always set to 0.
* Byte 0 [4] - Extension, which is always set to 0.
* Byte 0 [3:0] - CSRC Count, which is always set to 0 since this feature isn't used.
* Byte 1 [7] - Marker, which is always 0.
* Byte 1 [6:0] - Payload type, which is always 3 (GSM).  This is consistent 
with [RFC 3551](https://datatracker.ietf.org/doc/html/rfc3551#section-6).
* Bytes 2-3 - Sequence number represented by a 16-bit integer with the most-significant byte sent first.
* Bytes 4-7 - Timestamp, which is always set to 0.
* Bytes 8-11 - SSRC identifier, represented by a 32-bit integer with the most-significant byte sent first.  This is intended 
to uniquely identify the origin of the stream.  There is more discussion of this below.

Following the 12-byte RTP header, exactly 4 GSM frames are encoded. Each
frame is 33 bytes in length.  These frames are packed in chronological order 
with the earliest of the 4 packets in bytes 12-44, the next in bytes 45-77, etc.

The encoding of the GSM frame itself is tricky.  Please consult 
[RFC 3551](https://datatracker.ietf.org/doc/html/rfc3551#section-4.5.8.1) for
details, and pay particular attention to section 4.5.8.1.  This encoding
puts a 4-bit fixed signature 0b1101 in the MSB nibble of the first byte to pad
out the GSM packet to 33 bytes (there are only 260 bits of real information, 
which is only 32.5 bytes).  

The four-bit 0b1101 signature makes it easy to sanity check the RTP packets since you can see them spaced at 33-byte intervals throughout a capture trace:

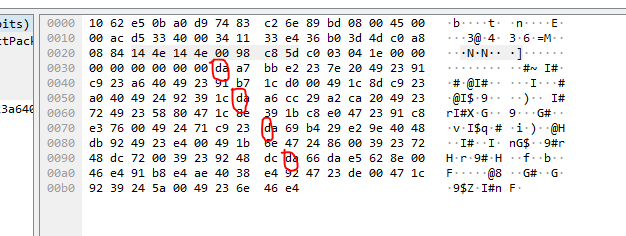
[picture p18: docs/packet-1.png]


From this example it looks like there is a consistent 0xda at the start of each GSM frame, but that's a coincidence - the "a" 
part can change depending on the audio being encoded.

### Notes on the Pacing of Audio Generation

The RTP packets are generated every 80ms, or every 160x4 audio samples collected at 8 kHz.  It's important
to keep in mind that RTP packets that travel through a network will speed up or slow down slightly based 
on normal congestion.  Good quality audio needs to be sampled/generated consistently at 8 kHz, **regardless of the 
network arrival time** of the RTP packets.  This requires some clever buffering to avoid the phenomenon
known as "audio jitter," particularly on the receive side.  Smooth generation of audio requires the 
receiver audio to be slightly delayed in order to avoid having the audio stream get ahead of the 
inbound packets.

These comments from Jonathan Taylor 
(K1RFD) are helpful and may provide some insight into how
the official EchoLink behaves.  I have tested this approach in the MicroLink station and it works very 
well:

> A buffer is a good idea, because packets won't be coming in at a steady rate (jitter).  Also, not all sound cards 
run at exactly 8kHz, so you may need to accommodate a faster or slower sender.

> I suggest the buffer be about a second long. Wait until it's half full before you start sending packets to the sound card. 
If possible, let the sound card itself dictate the rate at which you feed it. (On Windows, the API "returns" old buffers 
back to the application, which is how this can be accurately paced.) Otherwise, use a high-precision clock source.

> Keep an eye on the size of the buffer.  If it gets down to zero, stop playback until it's half-full again; in fact, 
this is a good way to detect when a transmission has ended, since there's no "end" packet. If it gets too high, consider 
dropping a packet.

> Sometimes packets are dropped along the way. You can detect this because the packets are sequentially numbered, from 
the same sender. If you receive packet 20 right after 18, consider inserting a silent packet between them.  You 
can also attempt to re-order packets which are received out of sequence, but I have rarely ever seen that 
actually happen, so it might not be worth implementing.

### Notes on the RTP SSRC Identifier

(To follow)

> _Per Jonathan K1RFD: In the EchoLink software, it's a random number which remains constant during the QSO. 
Its reason-for-being is to detect and discard packets which come back to the sender, indicating a 
conferencing loop._

## GSM CODEC Notes

EchoLink uses GSM 06.10 "full-rate" audio coding. The complete description can be found in the [European Telecommunications Standards Institute specification document](https://www.etsi.org/deliver/etsi_EN/300900_300999/300961/08.00.01_40/en_300961v080001o.pdf).

Some speeds and feeds:
* The GSM FR spec defines a 8kHz audio sampling rate with 13 bits of PCM resolution.
* Audio PCM samples are grouped in 160 sample segments. So that implies one segment every 20ms.
* Each 160 sample segment is encoded into a 32.5 byte frame of parameters which is usually padded to 33 bytes.  So we get a 33 byte frame out of the encoder every 20ms.
* 33 bytes every 20ms is the same as 13,200 bits per second - that is the fundamental "baud rate" of GSM FR.
* EchoLink packs 4 33 byte frames into each RTP packet. So that means that EchoLink needs to deliver an RTP packet every 80ms (4x20ms), or 12.5 frames per second.  

Note that the official EchoLink client is smart enough to stop generating RTP frames 
during periods of silence.  So the receiver needs to keep careful track of the 
decode frequency and not drive the audio decoding rate by the arrival of packets.  

## EchoLink PING/OPEN/OVER Protocol

(_Research in process, not complete._)

(This section only applies to -L/-R/conference nodes that need to receive unsolicited connections
from behind a firewall. I have used explicit port forwarding on my implementation and 
things work fine without using this protocol.)

One of the challenges of running a peer-to-peer network is the limitation on the 
ability to pass packets
through firewalls. This is particularly relevant given the fact that the majority of EchoLink
stations are likely sitting behind commodity cable/telco routers that block all  
inbound traffic, for obvious reasons. As described above, EchoLink nodes need to pass
bi-direction UDP traffic on ports 5198/5199. These ports are certainly not "open" by default.

A different challenge relates to the NAT architecture that exists in commodity/retail
internet service. People typically have many devices on their "home" networks, but only a single 
internet-facing IP address. Even if an inbound packet was allowed past a firewall, how would 
that packet find its way to the right machine on the LAN?

The EchoLink system has implemented a clever mechanism that greatly alleviates both of these issues.
There may still be situations where this doesn't work, but those are less common.

Understanding this mechanism requires an understanding of dynamic firewall capabilities known 
as [Stateful Packet Inspection](https://en.wikipedia.org/wiki/Stateful_firewall) and/or [UDP Hole Punching](https://en.wikipedia.org/wiki/UDP_hole_punching). A full 
explanation is beyond the scope of this
document, but the key thing to understand is: on most "normal" internet routers **sending a UDP
packet to a remote address will automatically grant temporary permission for the return trip.** 
This temporary permission is sometimes called a "UDP hole" because it enables a traffic pattern
that would not normally be possible. The hole being 
described here includes (a) a firewall opening to allow return traffic **on the same port** and (b) the
routing entries needed to get the return traffic back to the right place on your LAN.

The UDP hole is transient and will only persist as long as the network path is actively being 
used. Once a path becomes inactive the UDP hole is closed.

EchoLink leverages this feature to reduce the need for users to manually create firewall rules
and/or port forwarding policies. 

The general flow is as follows. In this description, the "Calling Node" is originating a 
connection to the "Remote Node" which is a link or repeater (i.e. -L or -R). 

1. Remote nodes poll the EchoLink Server (ex: naeast.echolink.org) every 30 seconds using a 
special RTCP SDES "PING" packet on the RTCP port.  The EchoLink Server has port 5199 
open for all incoming traffic. Because the Remote node is pinging on a regular basis, 
a UDP hole is being held open that allows packets to flow from the EchoLink Server to the Remote 
node.
2. The EchoLink Server responds to each PING on the same port using the same RTCP SDES 
message, using the UDP hole created in step #1.
3. When the Calling node wants to connect to the Remote node, it first sends a message to the 
EchoLink Addressing Server that contains the IP address of the Remote node it wants to contact. Note that 
a direct connection from the Calling node to the Remote node would normally be blocked at
this point, *which is exactly the problem we are trying to solve*. Only the EchoLink Addressing Server 
is reachable from the Calling node. (NOTE: I am not yet sure whether an explicit message
is used in this step, or whether step #4 is triggered as a side-effect of the normal callsign 
lookup that is used by the Calling node to resolve the IP address of the Remote node.)
4. The EchoLink Addressing Server then sends a different RTCP message called an "OPEN packet" to the Remote 
node via the UDP hole. This packet contains the IP address of the Calling node.
5. The Remote node sends a special RTCP message called an "OVER packet" to the Calling node.
**This packet will be blocked by the Calling node's firewall, as expected.** However, the 
side-effect of sending this packet is the creation of UDP hole from the Calling node to the 
Remote node on the RTCP port.
6. Similarly, the Remote node sends a special RTP message called a "McAd packet" to the
Calling node.  **This packet will be blocked by the Calling node's firewall, as expected.** However, the 
side-effect of sending this packet is the creation of UDP hole from the Calling node to the 
Remote node on the RTP port.
6. The Calling node sends the normal RTCP SDES/RTP oNDATA messages to the Remote node to 
establish a QSO.  This has the side-effect of opening a UDP hole from the Remote node 
to the Calling node.
7. Now UDP traffic can flow freely between both nodes, even though no special configurations
were made to their NAT tables or firewall rules.
8. Constant keep-alive traffic flows in both directions in order to keep the 
transient UDP holes open.

The next few sections show what the various packets look like

### RTCP PING Packet Format

As described in step #1 above, nodes send these PING packets to the Addressing Server
on a regular basis to keep a two-way channel open on the RTCP port. The Addressing Server echoes back an identical PING packet.

This packet follows
the regular SDES structure with the following SDES items used:

* A type 1 item is sent with the station's callsign.
* A type 2 item is sent with no contents.
* A type 3 item is sent with no contents.
* A type 4 item is sent with no contents.
* A type 5 item is sent with the word "PING".
* A type 6 item is sent with no contents.
* A type 8 item with an unknown meaning. The values sent by the official EchoLink client are consistent over time.  I see these bytes 
being sent (in hex), which spells "<01>P5198." 
* A type 8 item provides an indication of whether DTMF is supported by the node. The values sent by the official EchoLink client are consistent 
over time. I see these bytes being sent (in hex), which corresponds to ASCII "D0".
* Two type 0 items are sent wth no contents signalling the end of the message.

Here's what it looks like:

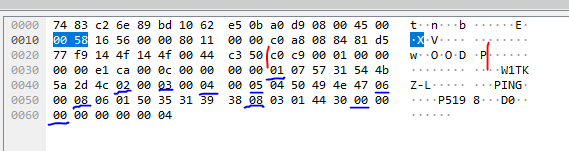
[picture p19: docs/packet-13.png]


* Ethernet/IP/UDP headers can be ignored in this illustration. The relevant packet content starts at the red line.
* The individual SDES items are marked in blue.

### RTCP OPEN Packet Format

This packet provides the most important function. As described in 
step #4 above, the Addressing Server will send an OPEN packet 
to the Remote node that provides the IP address of a Calling node
that wants to establish two-way communication. Without this 
heads-up from the Addressing Server, the Calling node would 
never know about the Remote node.

This packet follows
the regular SDES structure with the following SDES items used:

* A type 1 item is sent with the calling station's callsign.
* A type 2 item is sent with no contents.
* A type 3 item is sent with the calling station's IP
address in dotted-decimal format. 
* A type 4 item is sent with no contents.
* A type 5 item is sent with the word "OPEN".
* A type 6 item is sent with no contents.
* A type 8 item with an unknown meaning. The values sent by the official EchoLink client are consistent over time.  I see these bytes 
being sent (in hex), which spells "<01>P5198." 
* A type 8 item provides an indication of whether DTMF is supported by the node. The values sent by the official EchoLink client are consistent 
over time. I see these bytes being sent (in hex), which corresponds to ASCII "D0".
* Two type 0 items are sent wth no contents signalling the end of the message.

Here's what it looks like:

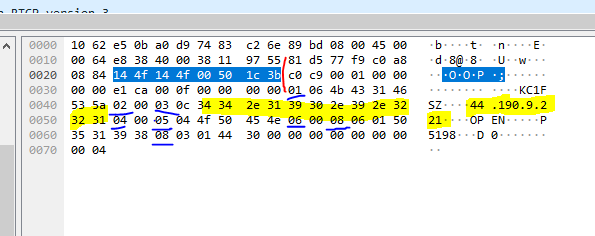
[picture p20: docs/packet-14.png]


* Ethernet/IP/UDP headers can be ignored in this illustration. The relevant packet content starts at the red line.
* The individual SDES items are marked in blue.

### RTCP OVER Packet Format

A standard RTCP header is sent which matches the RTCP-RR format.  Following the RTCP header, these bytes are sent:

* Two bytes: 0xe1 0xcc 
* Two bytes: 0x00 0x02 which are length-related.  This follows the (total length - 12) / 4 convention.
* Four bytes: the SSRC
* Four bytes: the word "OVER"



### RTP McAd Packet Format

At the same time that we send the OVER packet on the RTCP port 
we send a McAd message on the RTP port.  This has the effect
of opening RTP flow with the Calling node.



### Notes From Jonathan K1RFD on PING/OPEN/OVER

The EchoLink apps use some additional UDP messages to behave in a more "firewall-friendly" way. This is specifically 
to handle the case of at least one peer being behind a NAT router which has not been configured for port forwarding.  
(This technique works only for NAT which is not also doing PAT.)  It works similarly to one function of [TURN servers](https://en.wikipedia.org/wiki/Traversal_Using_Relays_around_NAT).

Whenever the app is connected to an addressing server, it also begins periodically sending RTCP packets to that 
same server, called PING, with an SDES item like this:

LOC: "PING"
CNAME: (my) callsign

The addressing server responds with the same PING packet back to the app, which ignores it.  The purpose of this 
communication is to keep a "flow" open in the NAT router, allowing the addressing server to send a future, unsolicited 
OPEN packet, when it detects that someone is trying to connect to this node.

The OPEN packet is initiated by a remote client (peer A) when it is trying to establish a connection to peer B.  
Peer A sends an RTCP packet to one of the addressing servers (any one) with an SDES item like this:

LOC: "OPEN"
CNAME: Peer A's callsign
Email: Dotted IP address of Peer B

The worldwide cluster of addressing servers replicates this packet amongst themselves, and whichever one Peer B is 
connected to sends a copy of it directly to Peer B over the established "flow", substituting Peer A's address in 
the "Email" item slot.  (Note that neither Peer A nor Peer B is likely to know their own public IP address, but the 
addressing servers know this.)

Peer B responds by sending a pair of packets directly to Peer A, since it now knows Peer A's address and its desire to 
start a QSO.  It sends both an RTCP packet and an RTP text packet to ensure that a new flow is opened over both 
ports.  The format of these packets is unimportant, since they are only for establishing a router flow, and Peer B 
will ignore them, but the EchoLink app uses these to avoid interfering with other functions:

RTCP: Payload type 201 (empty RR)
      Payload type 204 (application-defined packet "OVER")    

RTP: Four bytes of data: 0x6D, 0x63, 0x41, 0x64

Peer A sends the usual RTCP ID packet and RTP text packet directly to Peer B, which can now receive them 
since flows had been opened, and the QSO begins.

## EchoLink Proxy Protocol Notes

(To follow)

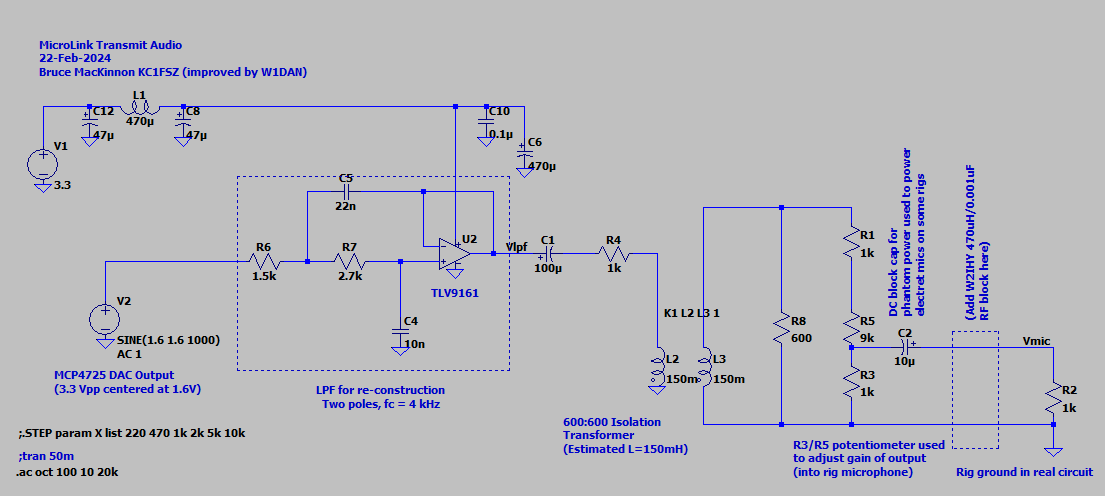
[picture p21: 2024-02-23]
docs/tx-audio-1.png

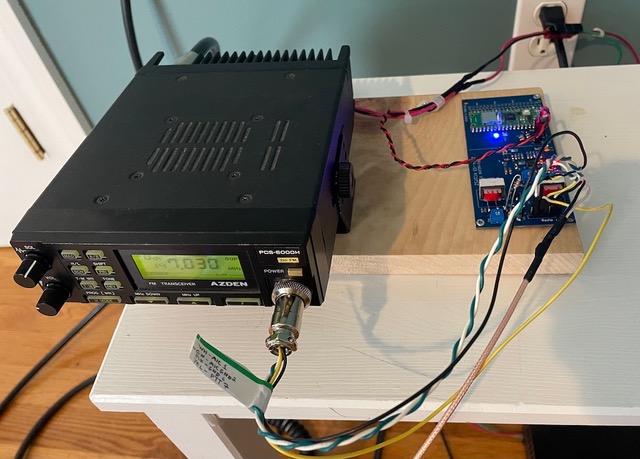
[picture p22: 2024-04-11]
docs/v1-station-0.jpeg

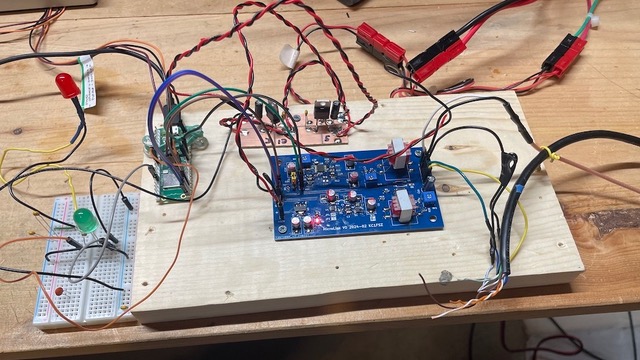
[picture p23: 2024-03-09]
docs/v0-board-1.jpeg

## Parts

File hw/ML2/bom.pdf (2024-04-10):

bom

Page 1

MicroLink V2 Bill of Materials

Reference | Value | Qty | Footprint | Notes | Price | Cost
C17 | 1u | 1 Capacitor_SMD:C_0805_2012Metric_Pad1.18x1.45mm_HandSolder | $0.05 | $0.05
C1 | 10u Tant | 1 Capacitor_SMD:Polarized_0805 | For regulator | $0.50 | $0.50
C2 | 10u Tant (ESR Range) | 1 Capacitor_SMD:Polarized_0805 | For regulator; 33mO to 2.2O! | $0.74 | $0.74
C5,C7,C8,C9,C11,C19,C20 | 47u Tant | 7 Capacitor_SMD:Polarized_0805 | $0.50 | $3.50
C3,C26 | 22n | 2 Capacitor_SMD:C_0805_2012Metric_Pad1.18x1.45mm_HandSolder | $0.05 | $0.10
C4,C27 | 10n | 2 Capacitor_SMD:C_0805_2012Metric_Pad1.18x1.45mm_HandSolder | $0.05 | $0.10
C6,C18,C21 | 0.1u | 3 Capacitor_SMD:C_0805_2012Metric_Pad1.18x1.45mm_HandSolder | $0.05 | $0.15
C10 | 47u | 1 Capacitor_SMD:Polarized_0805 | Optional DC block | $0.05 | $0.05
D1,D3,D4 | LED (B1701USD-20D000114U1930) | 3 LED_SMD:LED_0805_2012Metric_Pad1.15x1.40mm_HandSolder | https://www.digikey.com/en/products/detail/harvatek-corporation/ | $0.11 | $0.33
D2 | BAT54S | 1 Package_TO_SOT_SMD:SOT-23 | $0.27 | $0.27
J1 | Conn_01x07 | 1 Connector_PinHeader_2.54mm:PinHeader_1x07_P2.54mm_Vertical | $0.05 | $0.05
J2 | 5-12V Supply | 1 Connector_PinHeader_2.54mm:PinHeader_1x02_P2.54mm_Vertical | $0.05 | $0.05
J3 | Conn_01x20 | 1 Connector_PinHeader_2.54mm:PinHeader_1x20_P2.54mm_Vertical | $0.05 | $0.05
J4 | 3.3V Output | 1 Connector_PinHeader_2.54mm:PinHeader_1x02_P2.54mm_Vertical | For logger or other accessory | $0.05 | $0.05
Q1 | DMG2305UX-13 MOSFET | 1 Package_TO_SOT_SMD:SOT-23-3 | $0.27 | $0.27
R1,R15 | 1.5k | 2 Resistor_SMD:R_0805_2012Metric_Pad1.20x1.40mm_HandSolder | $0.05 | $0.10
R2,R16 | 2.7k | 2 Resistor_SMD:R_0805_2012Metric_Pad1.20x1.40mm_HandSolder | $0.05 | $0.10
R3,R18,R19,R23 | 0R | 4 Resistor_SMD:R_0805_2012Metric_Pad1.20x1.40mm_HandSolder | $0.05 | $0.20
R26 | 0R | 1 Resistor_SMD:R_1206 | Being used as a cross-over | $0.05 | $0.05
R4 | 570R | 1 Resistor_SMD:R_0805_2012Metric_Pad1.20x1.40mm_HandSolder | $0.05 | $0.05
R5,R6 | 10k | 2 Resistor_SMD:R_0805_2012Metric_Pad1.20x1.40mm_HandSolder | $0.05 | $0.10
RV1,RV2 | 10k | 2 Pot Bournes 3362P | $0.05 | $0.10
R8 | 200R | 1 Resistor_SMD:R_0805_2012Metric_Pad1.20x1.40mm_HandSolder | $0.05 | $0.05
R9 | 1k | 1 Resistor_SMD:R_0805_2012Metric_Pad1.20x1.40mm_HandSolder | $0.05 | $0.05
R24 | 1k | 1 Resistor_THT | Needs to be easy to change/remove | $0.05 | $0.05
R10,R11 | 330k 1% | 1 Resistor_SMD:R_0805_2012Metric_Pad1.20x1.40mm_HandSolder | Voltage divider, need 1% | $0.15 | $0.15
R11 | 270k 1% | 1 Resistor_SMD:R_0805_2012Metric_Pad1.20x1.40mm_HandSolder | Voltage divider, need 1% | $0.15 | $0.15
R12,R13 | 2.2k | 2 Resistor_SMD:R_0805_2012Metric_Pad1.20x1.40mm_HandSolder | $0.05 | $0.10
R17,R20,R22 | 220R | 3 Resistor_SMD:R_0805_2012Metric_Pad1.20x1.40mm_HandSolder | $0.05 | $0.15
R21 | 47R | 1 Resistor_SMD:R_0805_2012Metric_Pad1.20x1.40mm_HandSolder | $0.05 | $0.05
R25 | 33k | 1 Resistor_THT:R_Axial_DIN0309_L9.0mm_D3.2mm_P2.54mm_Vertical | $0.05 | $0.05
S1 | Pico W | 1 bruce-footprints:RPi_PicoW_SMD_TH | $6.00 | $6.00
T1,T2 | Transformer_1P_1S | 2 bruce-footprints:CheapAudioTransformer | $0.50 | $1.00
U1 | LMV324 (Actually TLV9164) | 1 Package_SO:TSSOP-14_4.4x5mm_P0.65mm | $2.74 | $2.74
U2,U5 | LTV-356T Optocoupler | 2 Package_SO:SO-4_4.4x3.6mm_P2.54mm | $0.49 | $0.98
U3 | NCP1117-3.3_SOT223 Regulator | 1 Package_TO_SOT_SMD:SOT-223-3_TabPin2 | $0.72 | $0.72
U4 | MCP4725xxx-xCH DAC | 1 Package_TO_SOT_SMD:SOT-23-6 | $1.27 | $1.27
U7 | LM4040DBZ-3 Voltage Reference | 1 Package_TO_SOT_SMD:SOT-23 | $0.72 | $0.72
SW0 | SPST-NO | 1 Switch: TS04-66-55-BK-160-SMT | https://www.digikey.com/en/products/detail/cui-devices/TS0 | $0.18 | $0.18
PC Board | 1 JLCPCB | $5.00 | $5.00
Power Conn | Anderson | 1 | $1.00 | $1.00
Audio Out Conn | 3.5mm | 1 | $0.50 | $0.50
CESS Aviation Conn | 8 Pin | 1 | $1.00 | $1.00
TOTAL | $28.87

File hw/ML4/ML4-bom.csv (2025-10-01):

Reference | Value | LCSC | Datasheet | BOM Comments | Footprint | Qty | DNP | DK
C1,C2 | 22u | C45783 | ~ |  | Capacitor_SMD:C_0805_2012Metric_Pad1.18x1.45mm_HandSolder | 2
C3,C26 | 22n | C1729 | ~ |  | Capacitor_SMD:C_0805_2012Metric_Pad1.18x1.45mm_HandSolder | 2
C4,C27 | 10n | C1710 | ~ |  | Capacitor_SMD:C_0805_2012Metric_Pad1.18x1.45mm_HandSolder | 2
C5,C7,C8,C9,C11,C17,C19,C20 | 47u | C16780 | ~ |  | Capacitor_SMD:C_0805_2012Metric_Pad1.18x1.45mm_HandSolder | 8
C6,C18,C21 | 0.1u | C28233 | ~ |  | Capacitor_SMD:C_0805_2012Metric_Pad1.18x1.45mm_HandSolder | 3
C10 | 47u (Optional DC Block) | C22320 | ~ |  | Capacitor_THT:CP_Radial_D5.0mm_P2.50mm | 1
D2 | BAT54S | C12765 | https://www.diodes.com/assets/Datasheets/ds11005.pdf |  | Package_TO_SOT_SMD:SOT-23 | 1
J1 | DE9_Receptacle | C17515865 | ~ |  | bruce-footprints:CONN_A-DF 09 A&slash_KG-T2S_ASM | 1 |  | AE10921-ND
J2 | PJ-102AH | C3096093 |  |  | bruce-footprints:Power_5.5mm_CUI_PJ-102AH | 1 |  | CP-102AH-ND
J3 | Conn_01x20 | C22465880 | ~ | Standard 2.54mm pin header | Connector_PinHeader_2.54mm:PinHeader_1x20_P2.54mm_Vertical | 1
J4 | Conn_01x02 | C492401 | ~ | Standard 2.54mm pin header | Connector_PinHeader_2.54mm:PinHeader_1x02_P2.54mm_Vertical | 1
Q1 | DMG2305UX-13 | C144153 | https://www.diodes.com/assets/Datasheets/DMG2305UX.pdf |  | Package_TO_SOT_SMD:SOT-23_Handsoldering | 1
R1,R15 | 1.5k | C4310 | ~ |  | Resistor_SMD:R_0805_2012Metric_Pad1.20x1.40mm_HandSolder | 2
R2,R16 | 2.7k | C17530 | ~ |  | Resistor_SMD:R_0805_2012Metric_Pad1.20x1.40mm_HandSolder | 2
R3,R18 | 0R | C17477 | ~ |  | Resistor_SMD:R_0805_2012Metric_Pad1.20x1.40mm_HandSolder,Resistor_SMD:R_1206_3216Metric_Pad1.30x1.75mm_HandSolder | 2
R4 | 620 | C58633 | ~ |  | Resistor_THT:R_Axial_DIN0309_L9.0mm_D3.2mm_P2.54mm_Vertical | 1
R5,R6,R12,R13 | 2.2k | C17520 | ~ |  | Resistor_SMD:R_0805_2012Metric_Pad1.20x1.40mm_HandSolder | 4
R7 | 10 | C17415 | ~ |  | Resistor_SMD:R_0805_2012Metric_Pad1.20x1.40mm_HandSolder | 1
R8,R19 | 220 | C17557 | ~ |  | Resistor_SMD:R_0805_2012Metric_Pad1.20x1.40mm_HandSolder | 2
R9 | 1k | C17513 | ~ |  | Resistor_SMD:R_0805_2012Metric_Pad1.20x1.40mm_HandSolder | 1
R10 | 330k 1% | C17629 | ~ |  | Resistor_SMD:R_0805_2012Metric_Pad1.20x1.40mm_HandSolder | 1
R11 | 270k 1% | C17589 | ~ |  | Resistor_SMD:R_0805_2012Metric_Pad1.20x1.40mm_HandSolder | 1
R17,R20,R22 | 100 | C17408 | ~ |  | Resistor_SMD:R_0805_2012Metric_Pad1.20x1.40mm_HandSolder | 3
R21 | 4.7 | C17675 | ~ |  | Resistor_SMD:R_0805_2012Metric_Pad1.20x1.40mm_HandSolder | 1
R24 | 2,.2k | C58595 | ~ |  | Resistor_THT:R_Axial_DIN0309_L9.0mm_D3.2mm_P2.54mm_Vertical | 1
R25 | 39k | C58645 | ~ |  | Resistor_THT:R_Axial_DIN0309_L9.0mm_D3.2mm_P2.54mm_Vertical | 1
R26 | 0R 1206 | C17888 | ~ |  | Resistor_SMD:R_1206_3216Metric_Pad1.30x1.75mm_HandSolder | 1
RV1,RV2 | 50k | C81264 | ~ |  | bruce-footprints:POT_3362P | 2
S1 | ~ | C7203003 |  |  | bruce-footprints:RPi_PicoW_SMD_TH | 1
SW0 | TS04-66-55-BK-160-SMT | C4364775 |  |  | bruce-footprints:SW_TS04-66-55-BK-160-SMT | 1
TR1,TR2 | SM-LP-5001 | C7503474 | https://www.bourns.com/docs/Product-Datasheets/SMLP5001.pdf |  | bruce-footprints:TRAN6_SM-LP-5001_BRN | 2
U1 | TLV9164PWR | C4368361 | http://www.ti.com/lit/ds/symlink/lmv324.pdf |  | Package_SO:TSSOP-14_4.4x5mm_P0.65mm | 1
U2,U5 | LTV-356T | C125117 | http://optoelectronics.liteon.com/upload/download/DS70-2001-010/S_110_LTV-356T%2020140520.pdf |  | Package_SO:SO-4_4.4x3.6mm_P2.54mm | 2
U3 | LM1117MP-3.3 | C9662 | http://www.ti.com/lit/ds/symlink/lm1117.pdf |  | Package_TO_SOT_SMD:SOT-223-3_TabPin2 | 1
U4 | MCP4725A0T-E/CH | C144198 | http://ww1.microchip.com/downloads/en/DeviceDoc/22039d.pdf |  | Package_TO_SOT_SMD:SOT-23-6 | 1
U7 | LM4040D30IDBZR | C2157213 | http://www.ti.com/lit/ds/symlink/lm4040-n.pdf |  | Package_TO_SOT_SMD:SOT-23 | 1
D1 | Red | C84256 | ~ |  | LED_SMD:LED_0805_2012Metric_Pad1.15x1.40mm_HandSolder | 1
D3 | Blue | C84259 | ~ |  | LED_SMD:LED_0805_2012Metric_Pad1.15x1.40mm_HandSolder | 1
D4 | Green | C2297 | ~ |  | LED_SMD:LED_0805_2012Metric_Pad1.15x1.40mm_HandSolder | 1

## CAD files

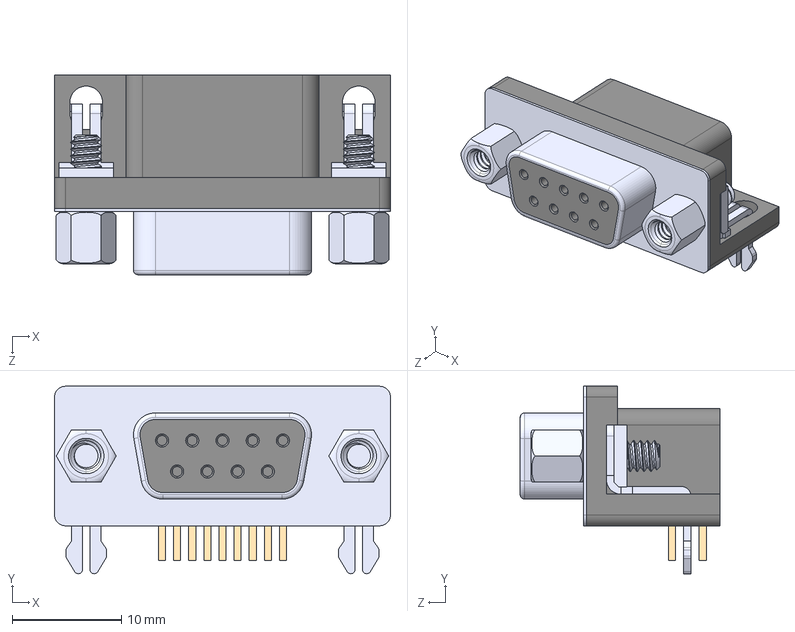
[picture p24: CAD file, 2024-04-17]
hw/3dmodels/A-DF_09_A_KG-T2S.step
30.8 x 17.2 x 18.3 mm

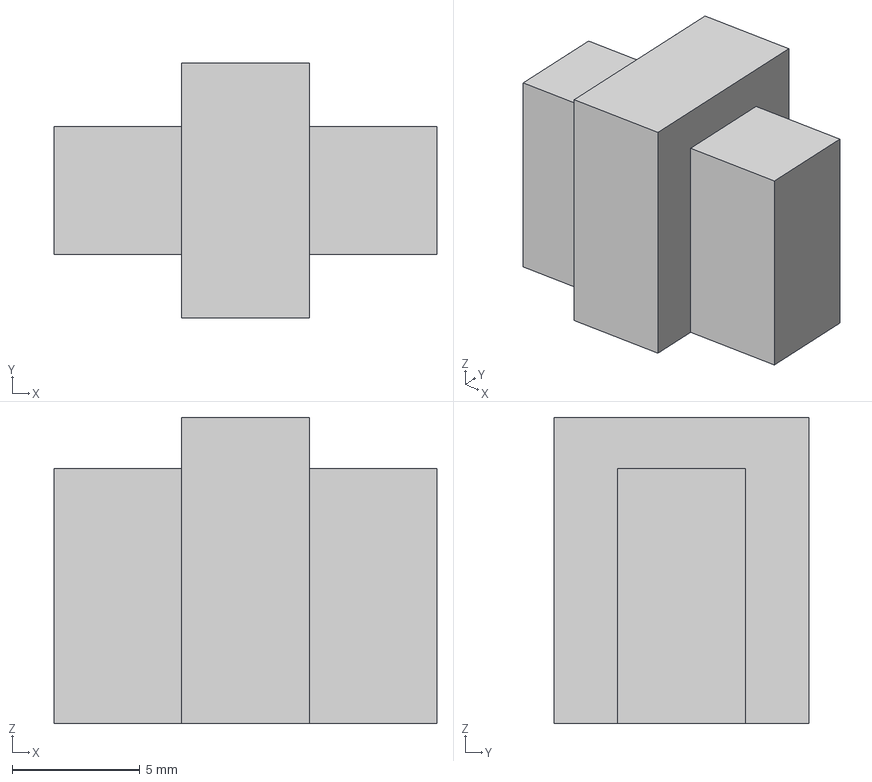
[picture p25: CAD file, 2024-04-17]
hw/3dmodels/Transformer v1.step
15.0 x 10.0 x 12.0 mm

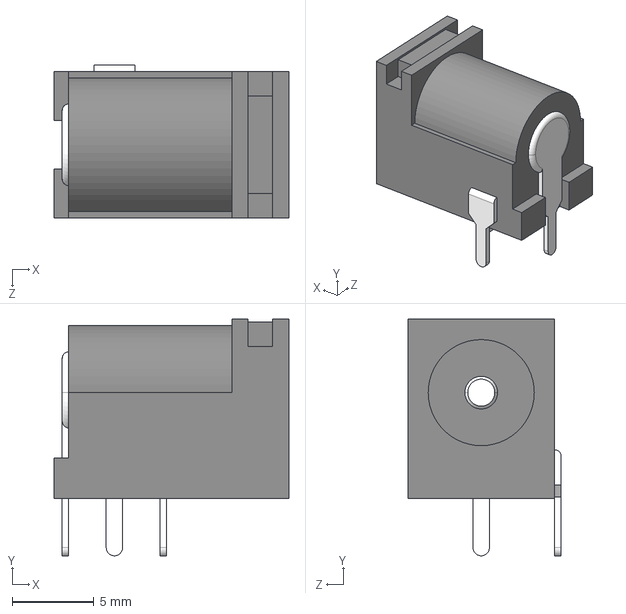
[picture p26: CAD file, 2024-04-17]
hw/3dmodels/PJ-102AH.step
14.4 x 14.5 x 9.40 mm

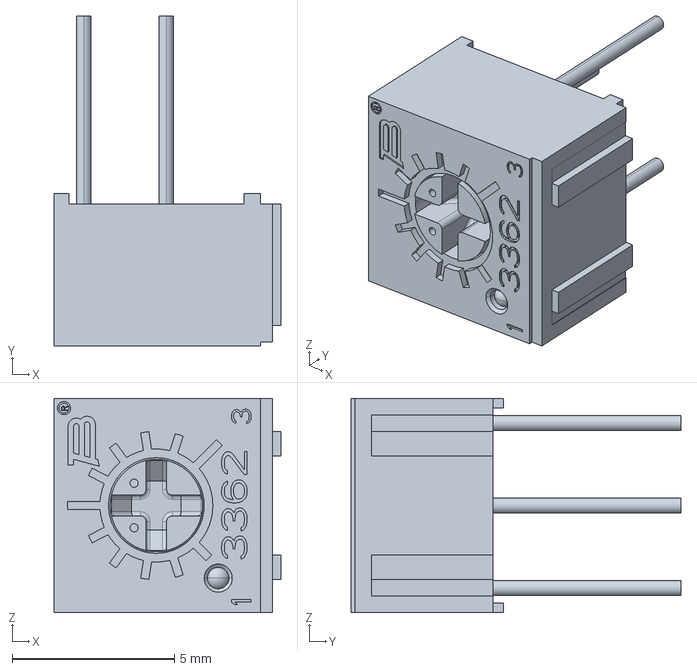
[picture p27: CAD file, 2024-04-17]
hw/3dmodels/3362P001XXX0A.stp
6.98 x 10.2 x 6.60 mm

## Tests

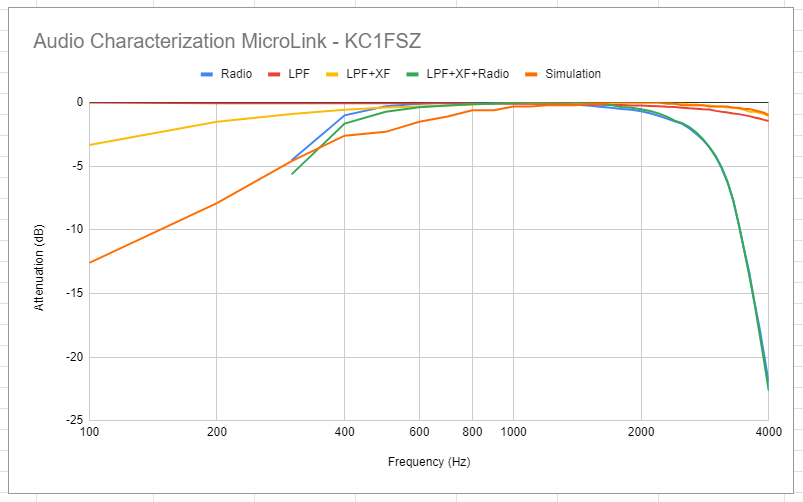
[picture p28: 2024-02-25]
docs/audio-characterization.png

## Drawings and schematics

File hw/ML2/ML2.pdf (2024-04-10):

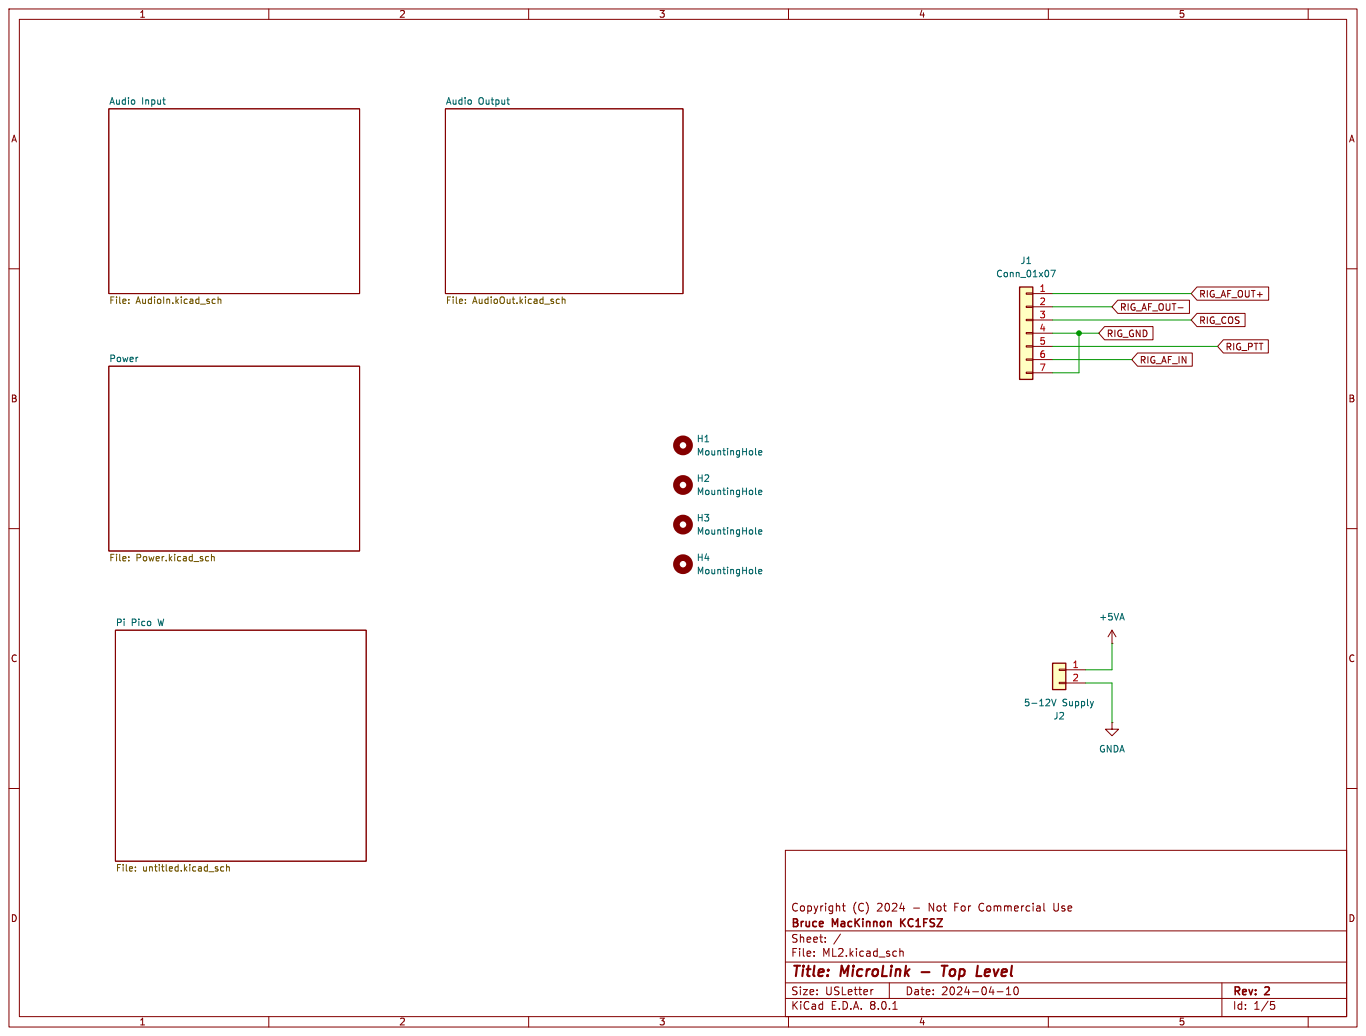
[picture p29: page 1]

Audio Output File: AudioOut.kicad_sch Audio Input File: AudioIn.kicad_sch Power File: Power.kicad_sch Pi Pico W

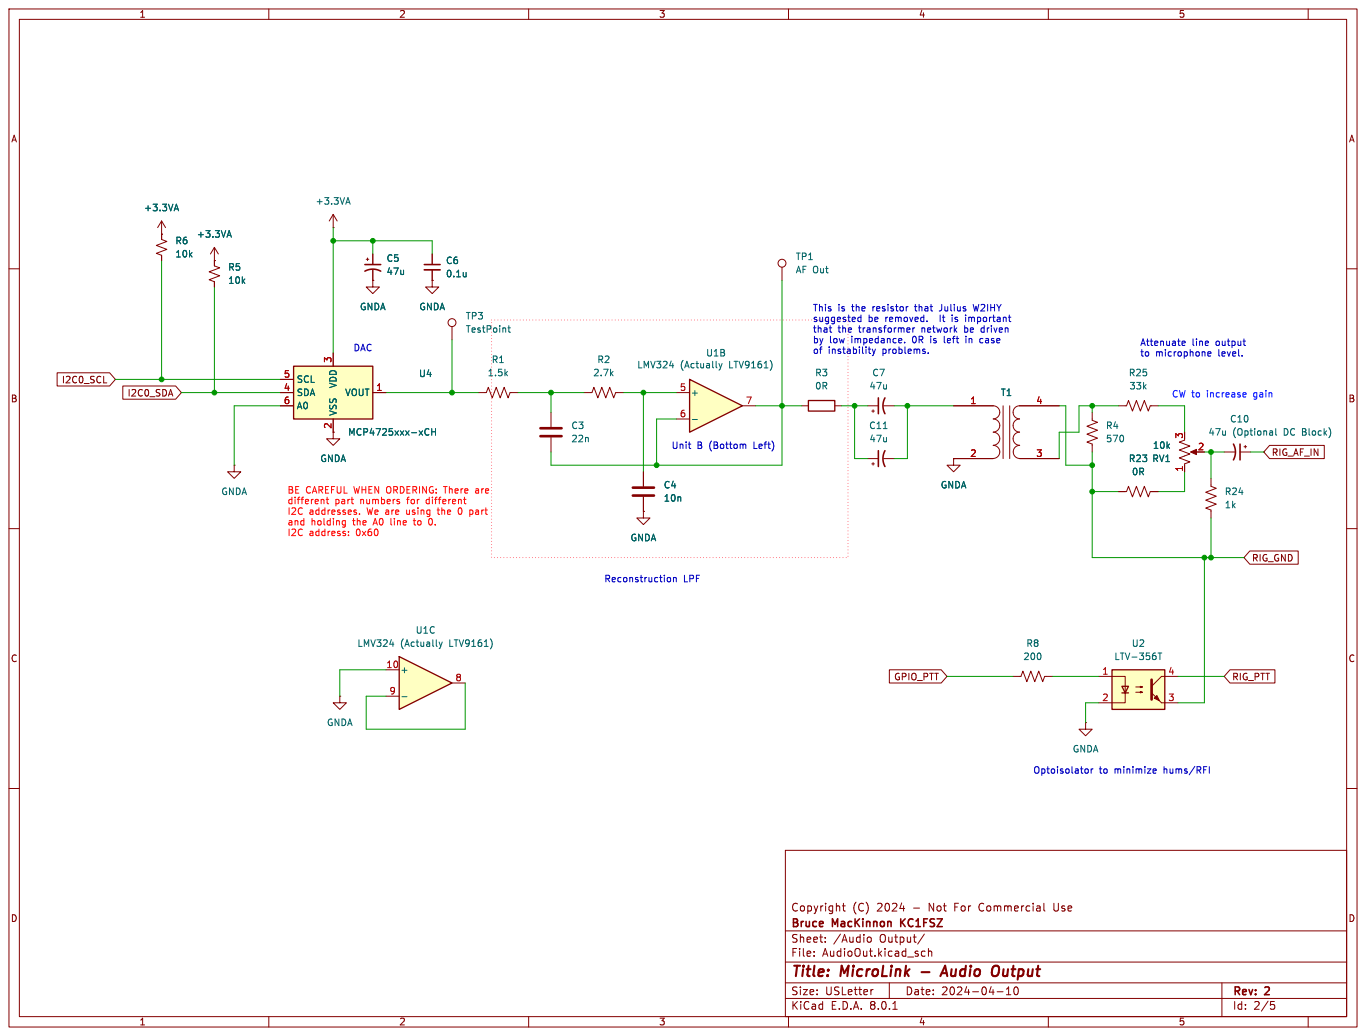
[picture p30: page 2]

3 SDA 4 SCL 5 A0 6 U4 MCP4725xxx-xCH GNDA GNDA R24

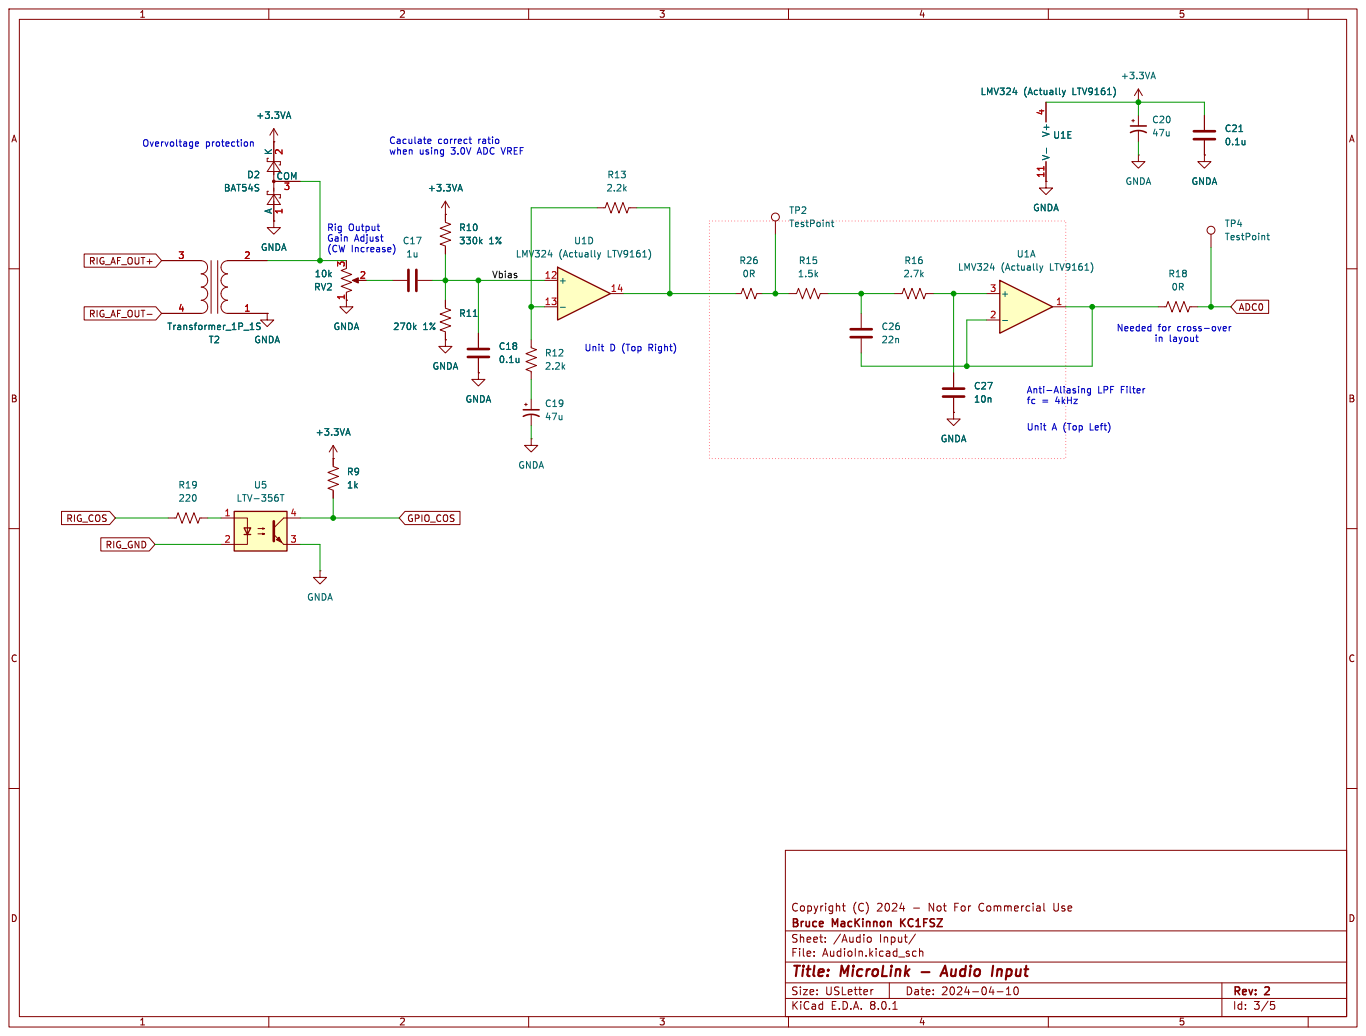
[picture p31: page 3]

Vbias Rig Output Gain Adjust

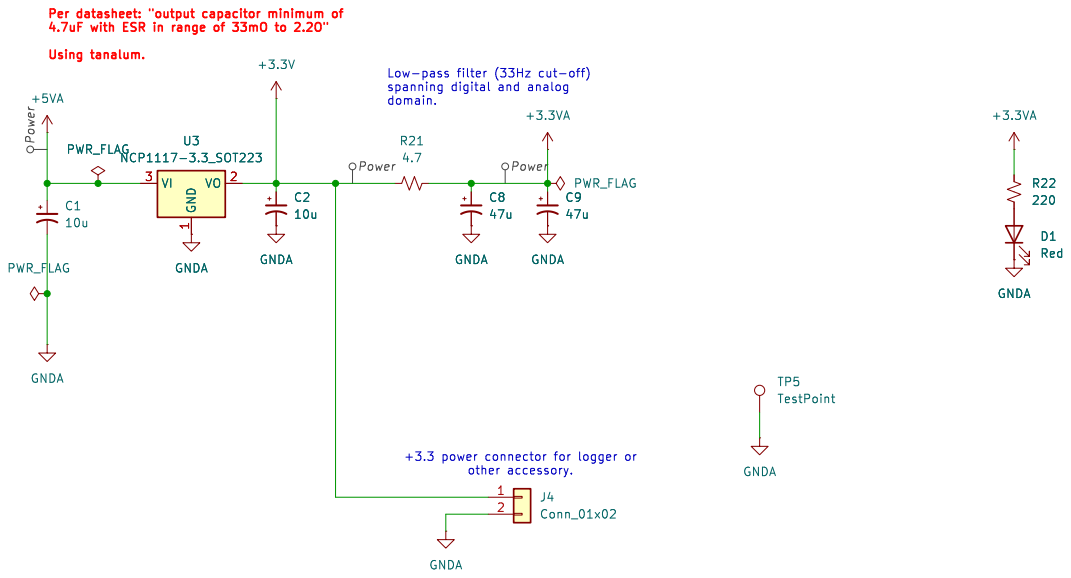
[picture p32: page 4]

1 VO 2 VI 3 U3 NCP1117-3.3_SOT223 GNDA D1 Red GNDA Power Power Power Per datasheet: "output capacitor minimum of 4.7uF with ESR in range of 33mO to 2.2O" Using tanalum. +3.3 power connector for logger or other accessory. Low-pass filter (33Hz cut-off)
domain. PWR_FLAG

Id: 4/5 Title: MicroLink - Power Related

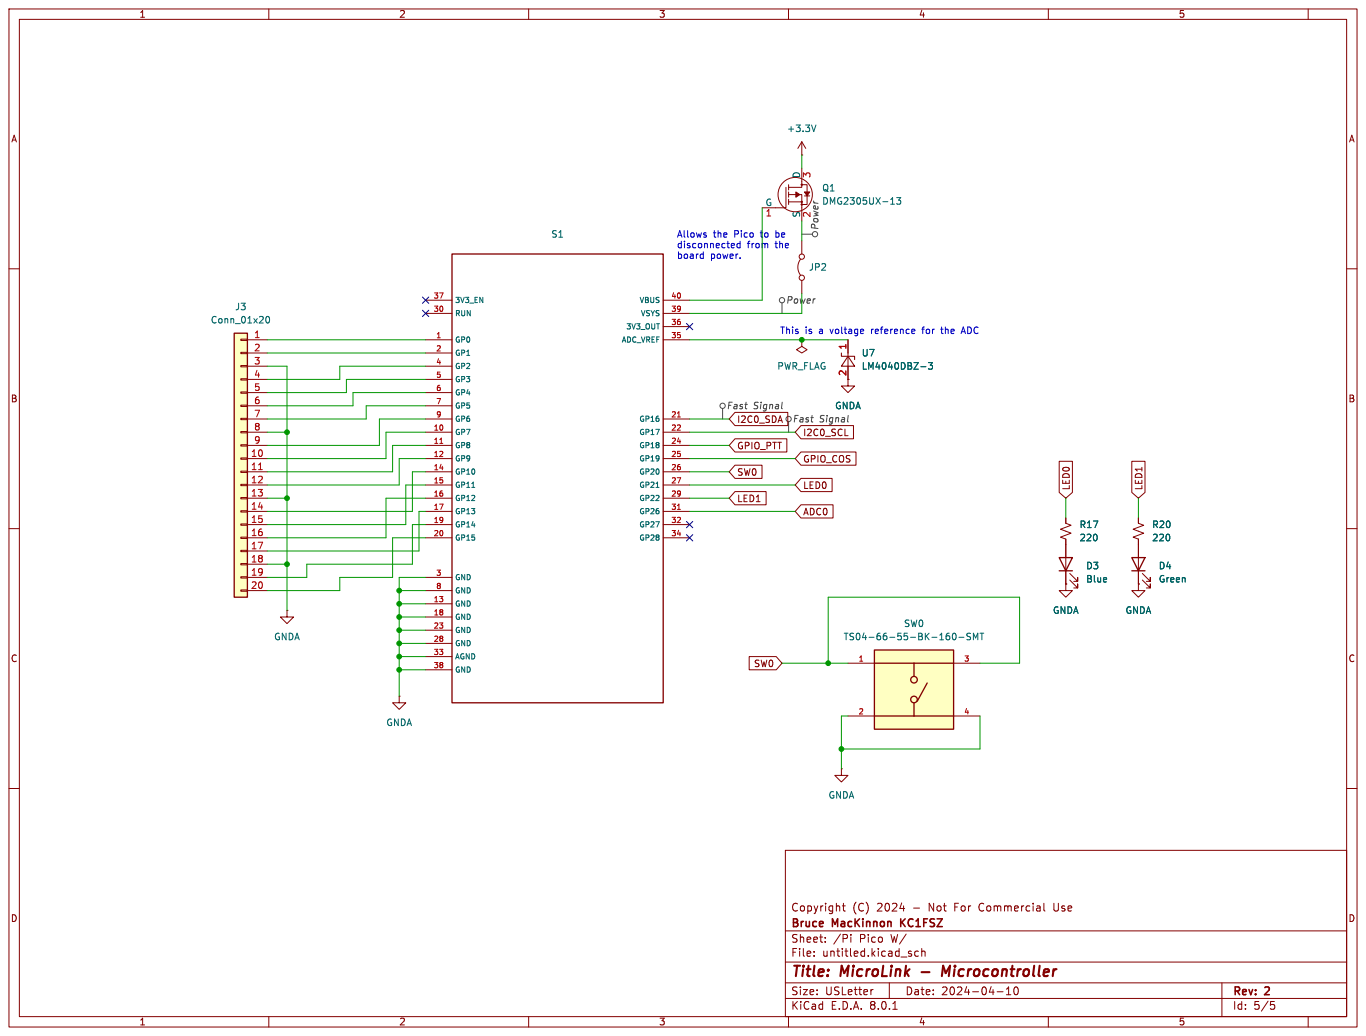
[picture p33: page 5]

Fast Signal Fast Signal Power Power ADC0

Allows the Pico to be

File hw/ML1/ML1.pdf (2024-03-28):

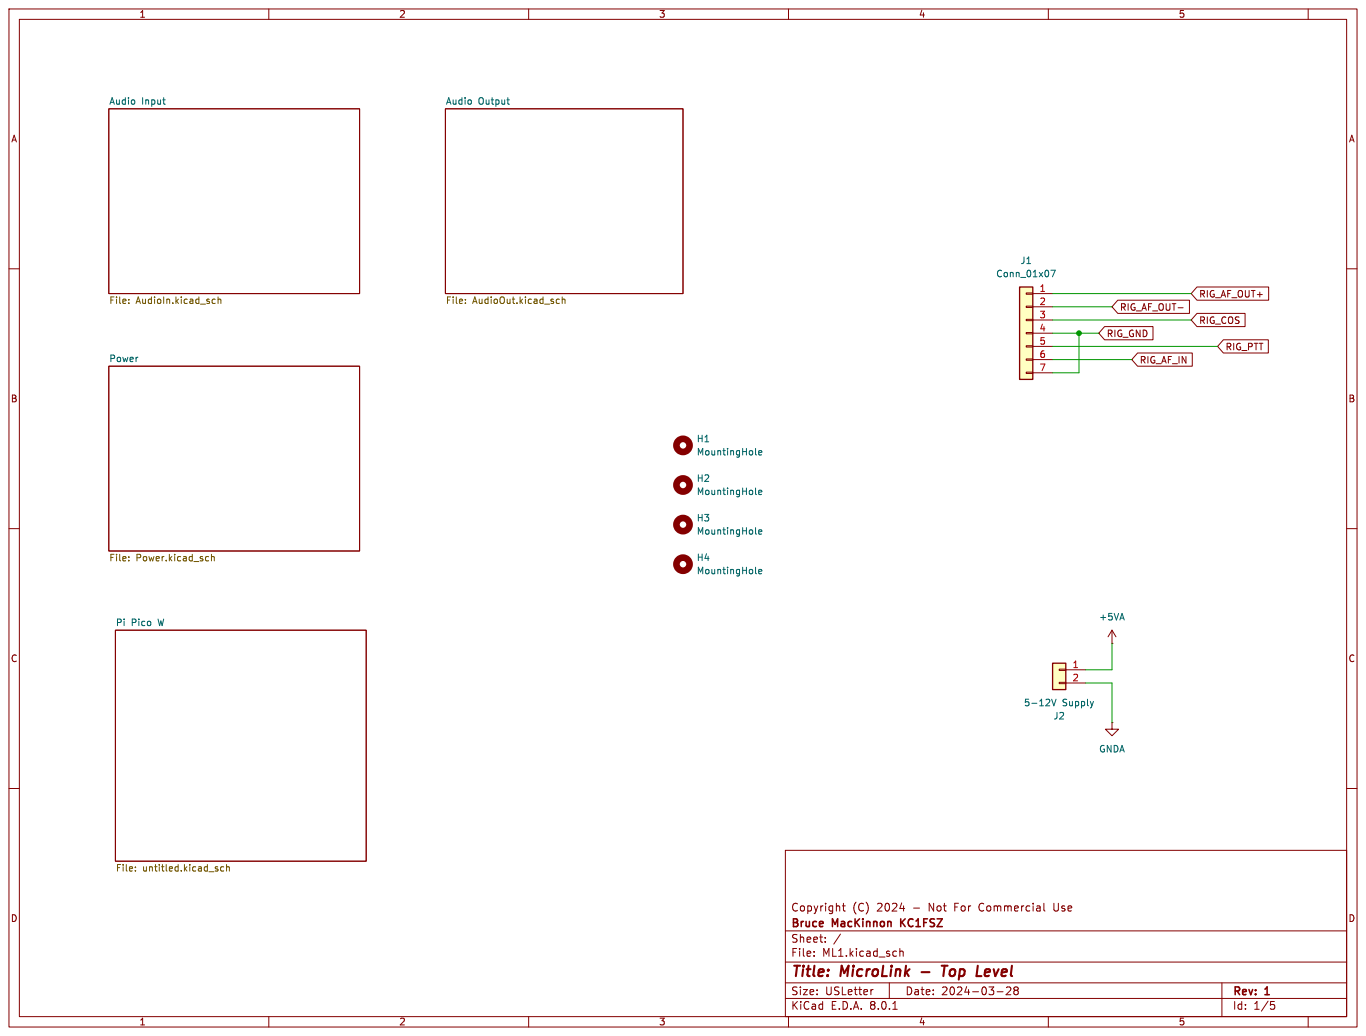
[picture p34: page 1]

Audio Output File: AudioOut.kicad_sch Audio Input File: AudioIn.kicad_sch Power File: Power.kicad_sch Pi Pico W

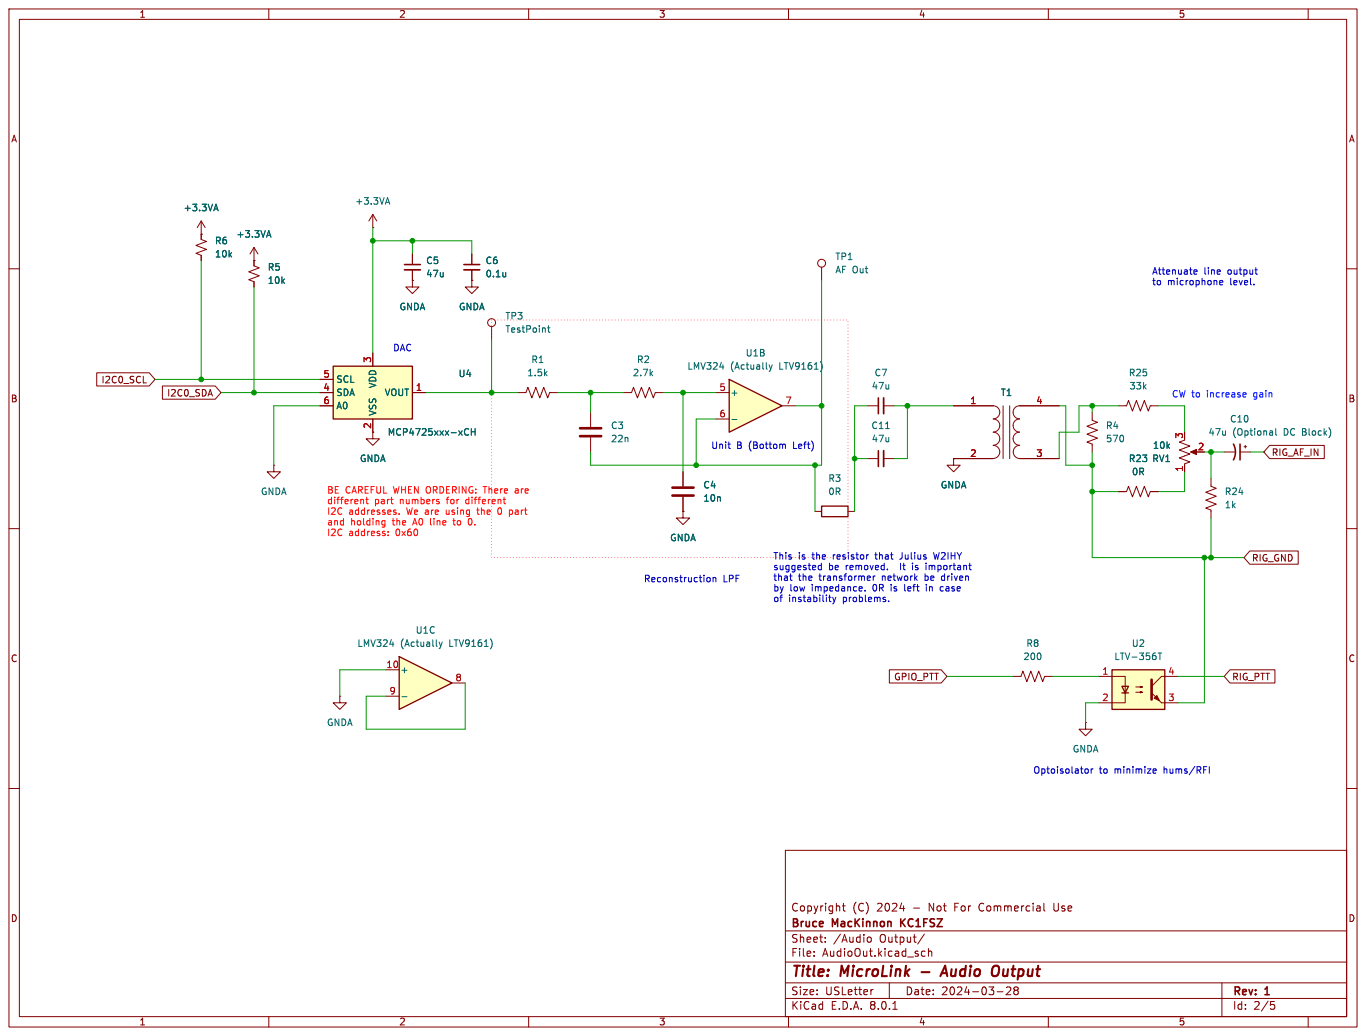
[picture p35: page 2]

3 SDA 4 SCL 5 A0 6 U4 MCP4725xxx-xCH GNDA R24

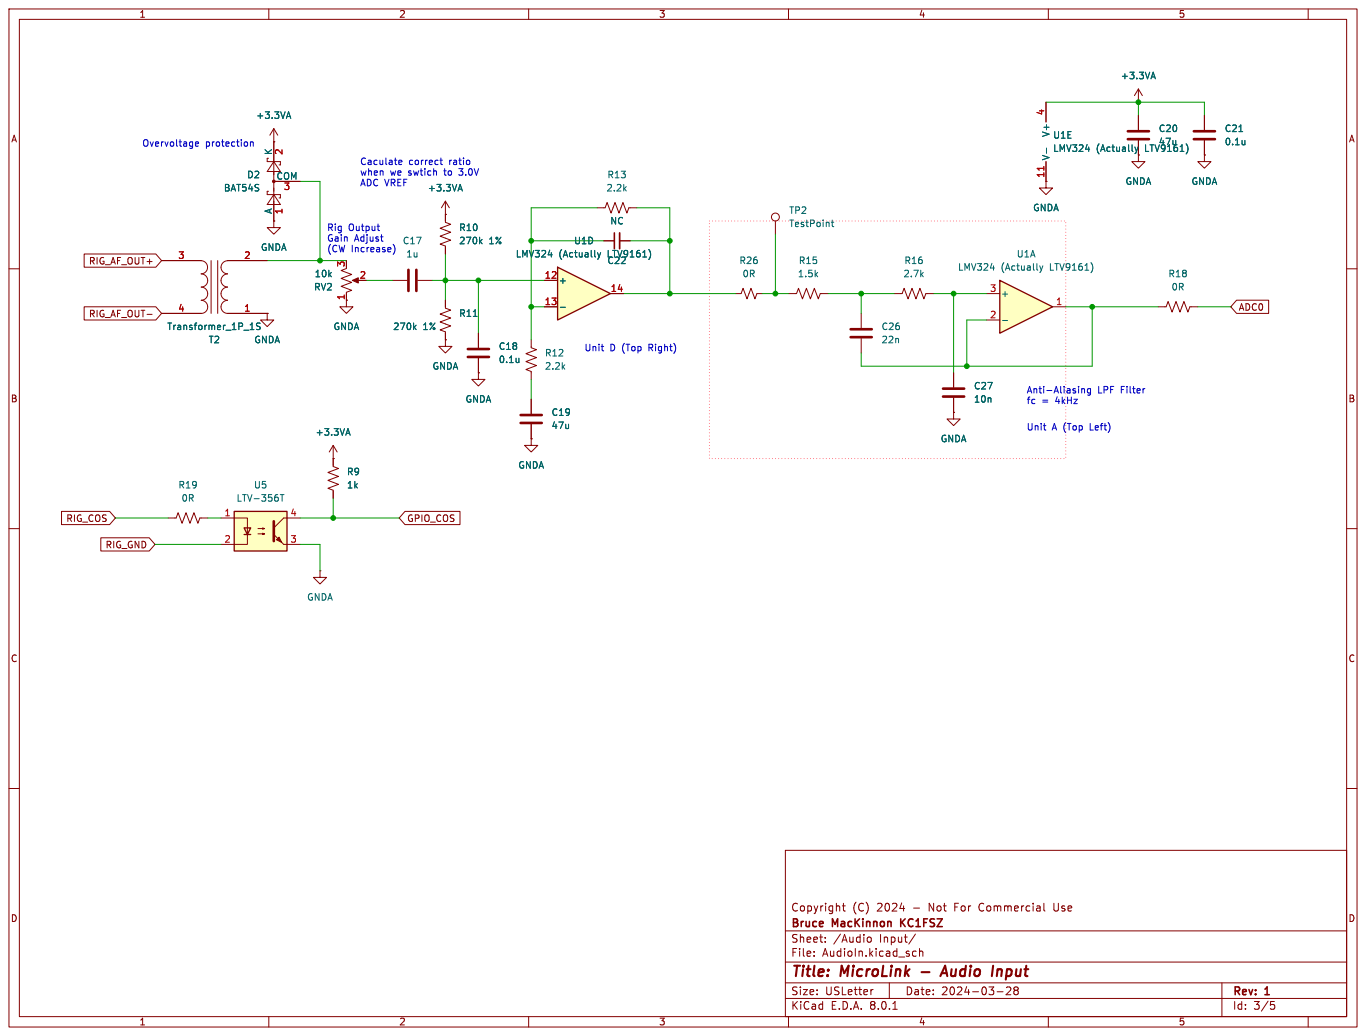
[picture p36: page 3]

(CW Increase) Caculate correct ratio when we swtich to 3.0V

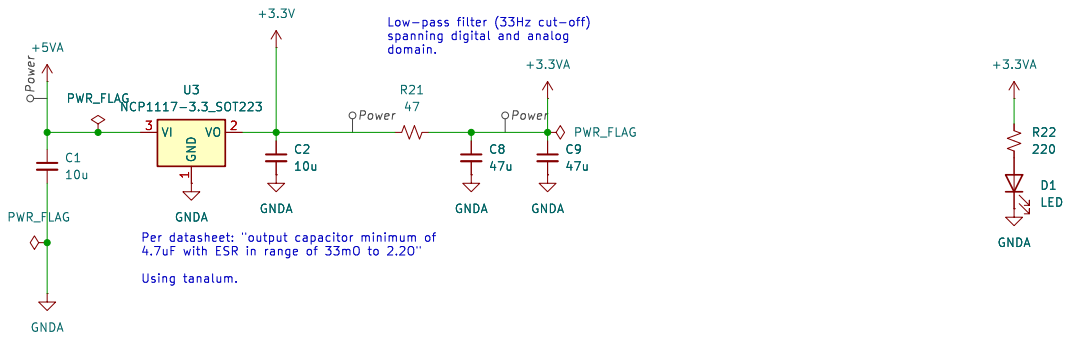
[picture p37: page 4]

Id: 4/5 Title: MicroLink - Power Related

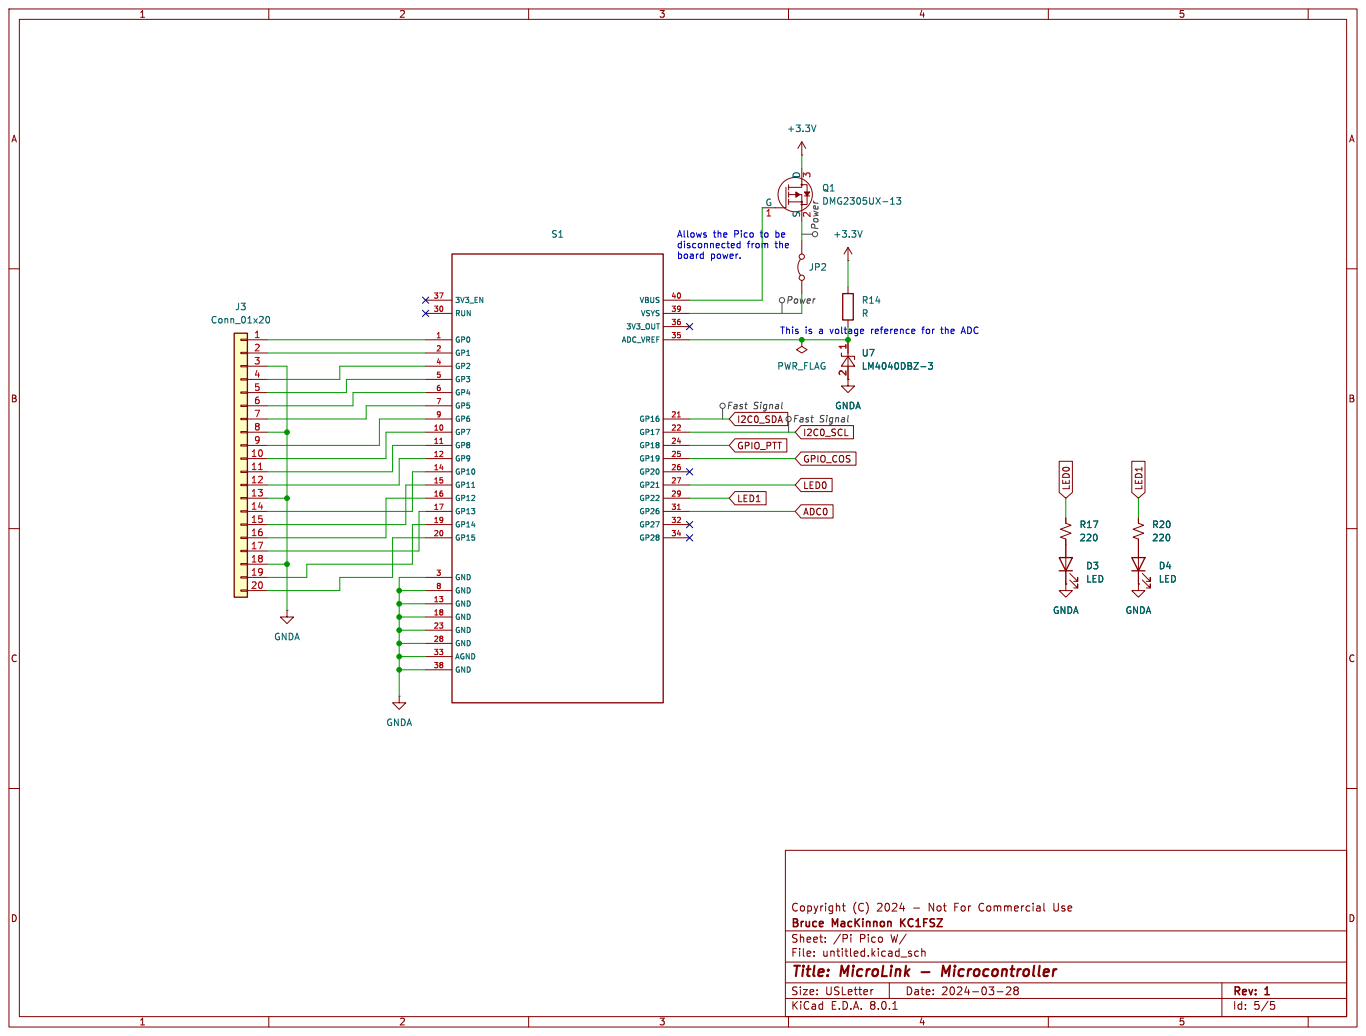
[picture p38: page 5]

LM4040DBZ-3 Power Fast Signal Power Fast Signal LED1

LED0 ADC0 Allows the Pico to be

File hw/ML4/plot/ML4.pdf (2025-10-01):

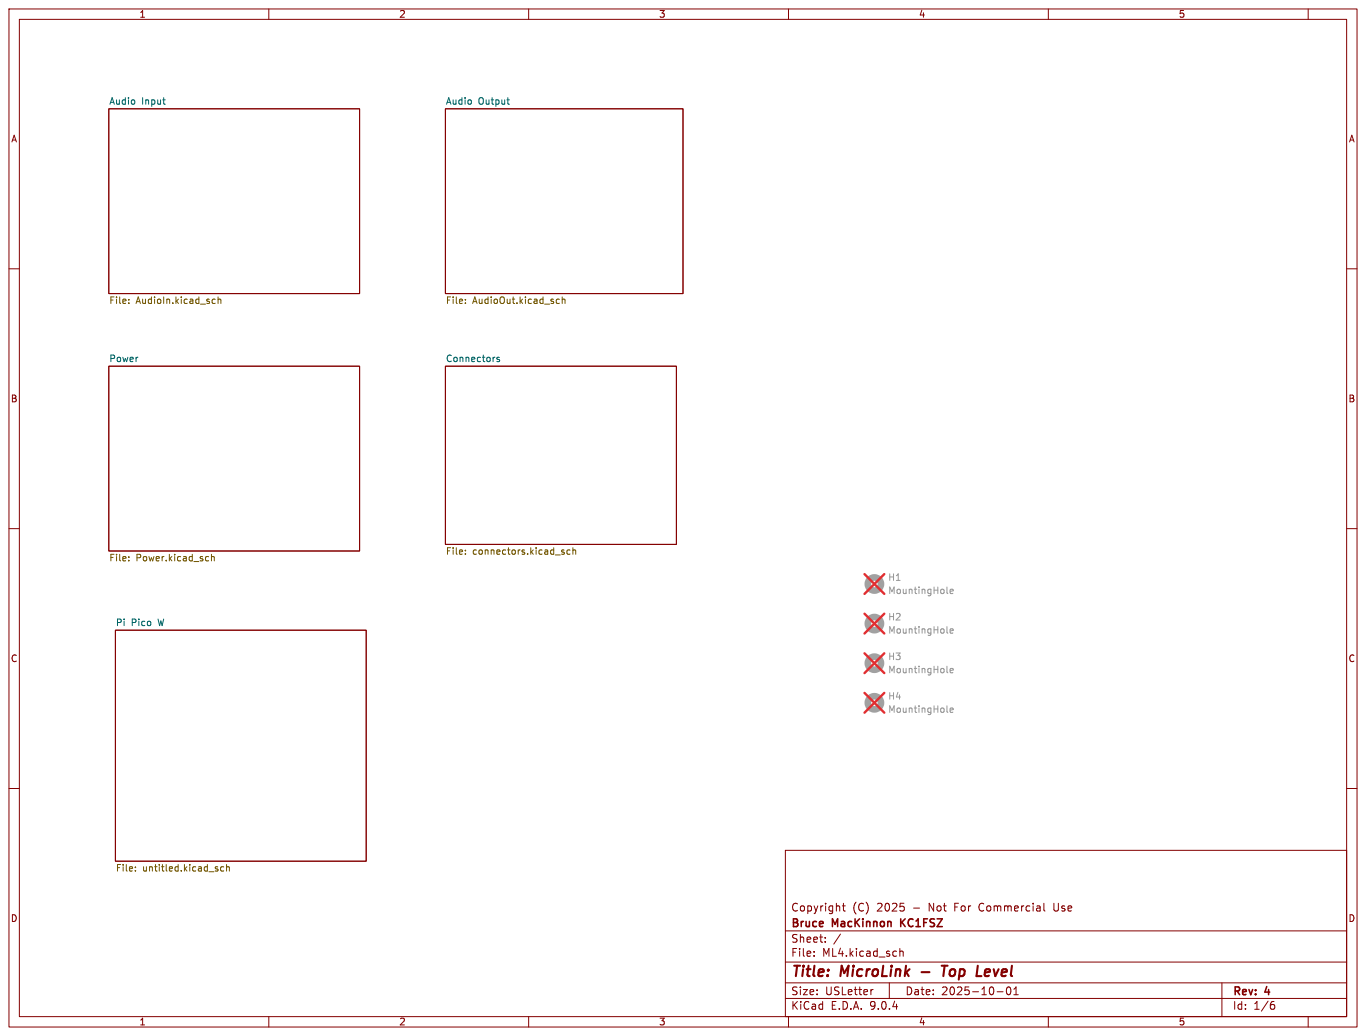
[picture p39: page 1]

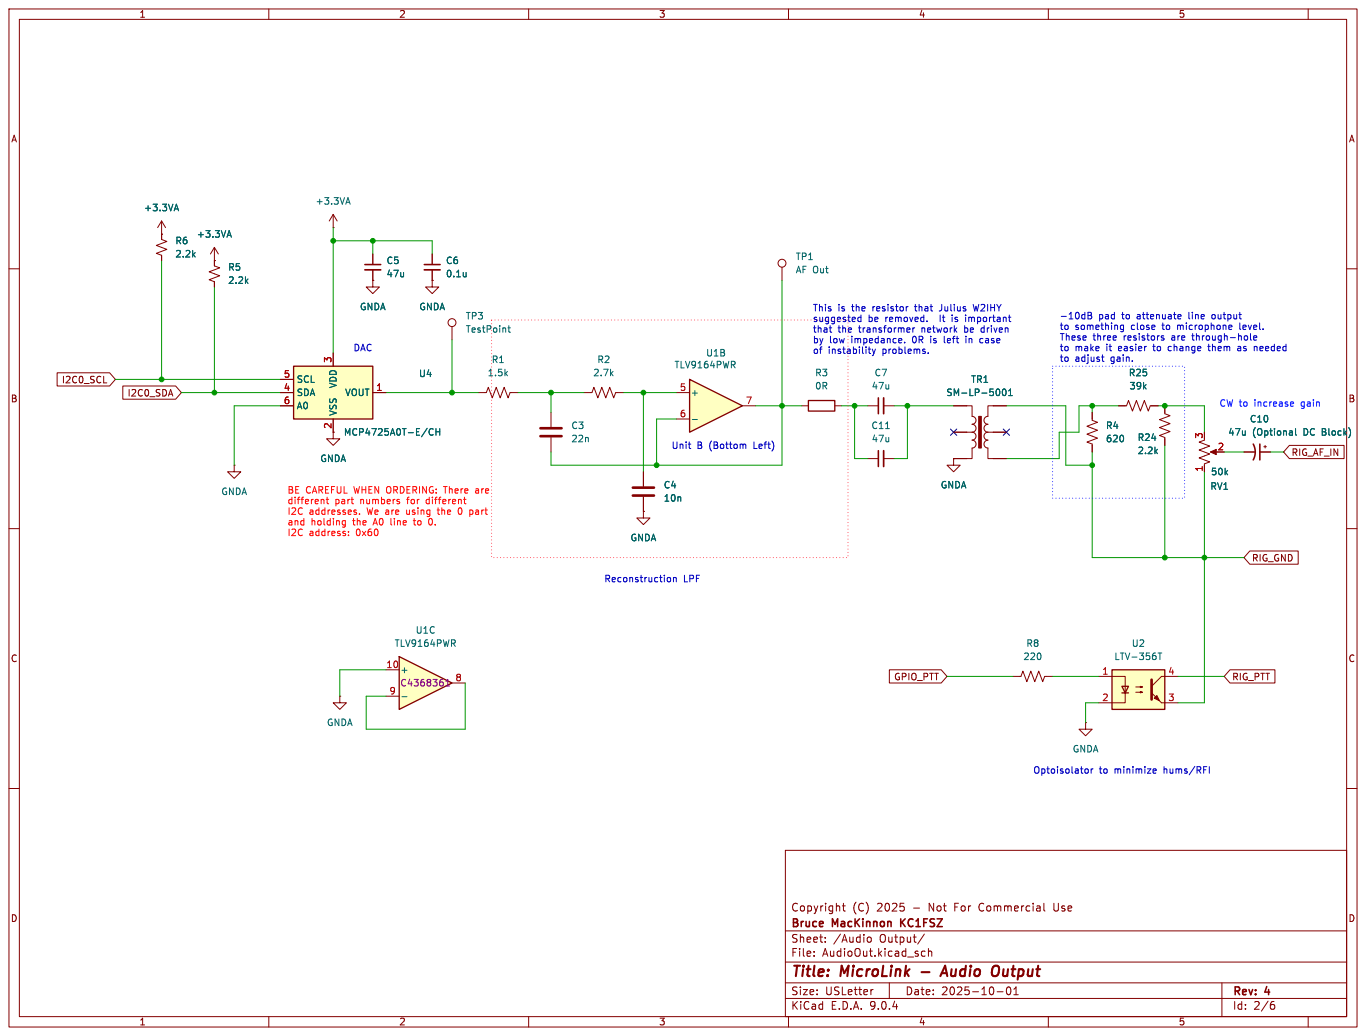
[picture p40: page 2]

to make it easier to change them as needed


Rig Output Gain Adjust

fc = 4kHz Needed for cross-over


domain. Watch out, must be +12V capable! Per datasheet: "output capacitor minimum of 4.7uF with ESR in range of 33mO to 2.2O for stability." The ESR for a ceramic is too small, so added series R. U3

Id: 4/6 Title: MicroLink - Power Related


Fast Signal Power Power Fast Signal GPIO_PTT

Allows the Pico to be
board power. GNDAU7







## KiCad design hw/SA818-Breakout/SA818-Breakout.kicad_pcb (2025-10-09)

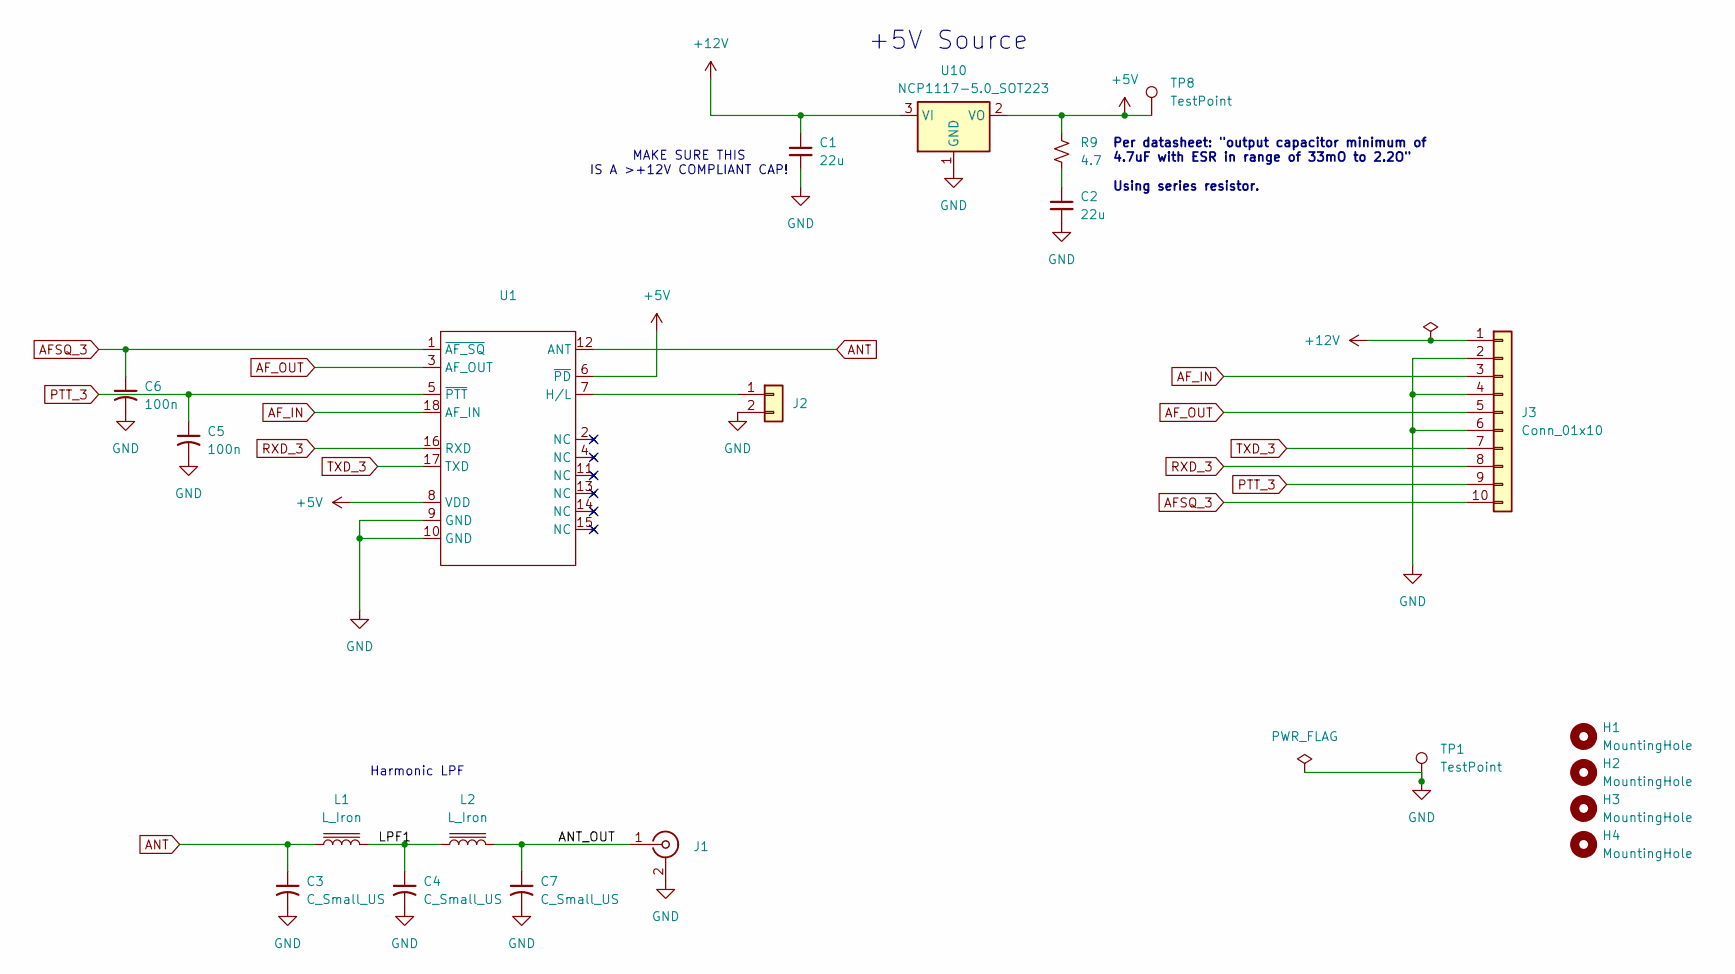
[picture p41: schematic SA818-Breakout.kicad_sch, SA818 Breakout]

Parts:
C1, C2: 22u; C_0805_2012Metric_Pad1.18x1.45mm_HandSolder
C3, C4, C7: C_Small_US; C_0805_2012Metric_Pad1.18x1.45mm_HandSolder
C5, C6: 100n; C_0805_2012Metric_Pad1.18x1.45mm_HandSolder
H1, H2, H3, H4: MountingHole; MountingHole_4mm
J1: Conn_Coaxial; SMA_Amphenol_901-144_Vertical
J2: Conn_01x02; PinHeader_1x02_P2.54mm_Vertical
J3: Conn_01x10; PinHeader_1x10_P2.54mm_Vertical
L1, L2: L_Iron; L_Axial_L6.6mm_D2.7mm_P10.16mm_Horizontal_Vishay_IM-2
R9: 4.7; R_0805_2012Metric_Pad1.20x1.40mm_HandSolder
TP1, TP8: TestPoint; TestPoint_Pad_2.5x2.5mm
U1: SA818
U10: NCP1117-5.0_SOT223; SOT-223-3_TabPin2

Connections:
+5V: R9.1, TP8.1, U1.6 (~PD), U1.8 (VDD), U10.2 (VO)
+12V: C1.1, J3.1, U10.3 (VI)
/ANT_OUT: C7.1, J1.1 (In), L2.2
/LPF1: C4.1, L1.2, L2.1
AFSQ_3: C6.1, J3.10, U1.1 (~AF_SQ)
AF_IN: J3.3, U1.18 (AF_IN)
AF_OUT: J3.5, U1.3 (AF_OUT)
ANT: C3.1, L1.1, U1.12 (ANT)
GND: C1.2, C2.2, C3.2, C4.2, C5.2, C6.2, C7.2, J1.2 (Ext), J2.2, J3.2, J3.4, J3.6, TP1.1, U1.9 (GND), U1.10 (GND), U10.1 (GND)
unnamed: C2.1, R9.2
unnamed: J2.1, U1.7 (H/L)
PTT_3: C5.1, J3.9, U1.5 (~PTT)
RXD_3: J3.8, U1.16 (RXD)
TXD_3: J3.7, U1.17 (TXD)

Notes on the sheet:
+5V Source
MAKE SURE THIS IS A >+12V COMPLIANT CAP!
Harmonic LPF
Per datasheet: "output capacitor minimum of 4.7uF with ESR in range of 33mO to 2.2O" Using series resistor.

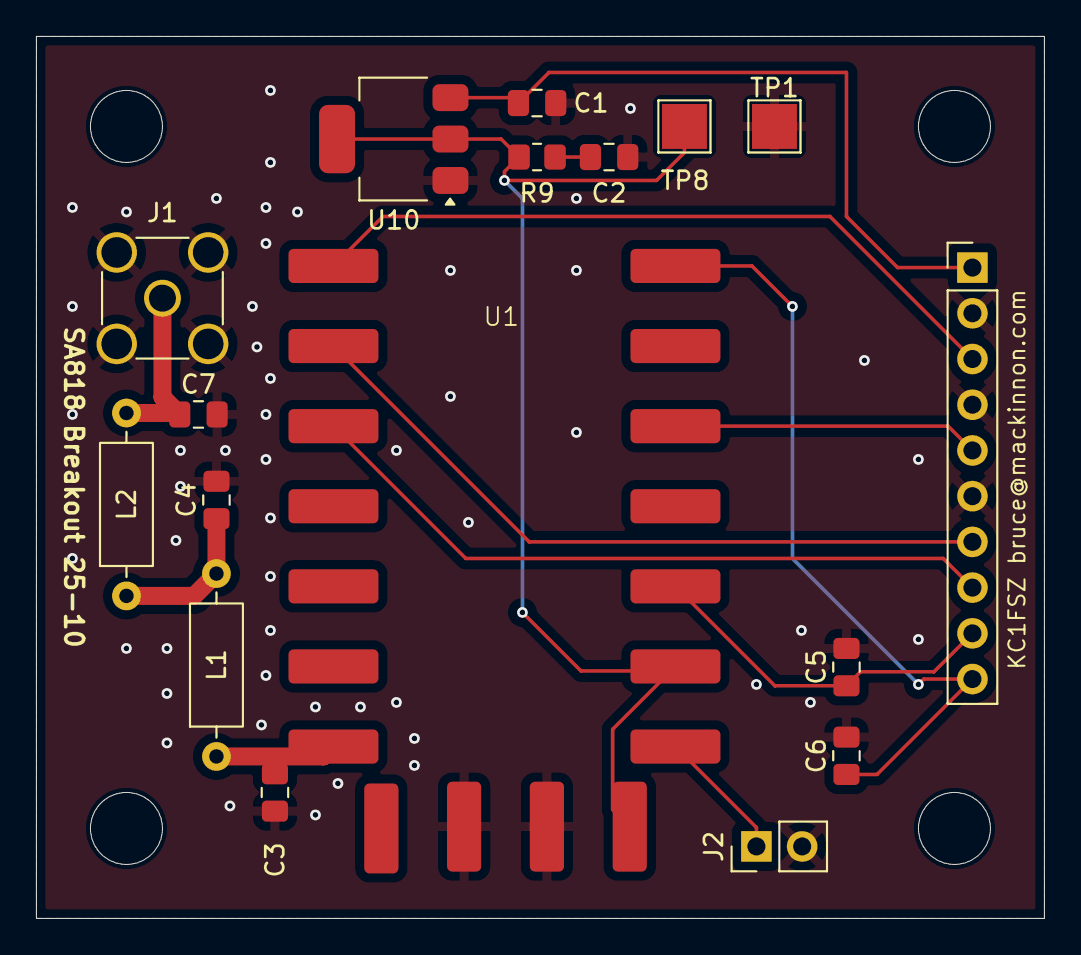
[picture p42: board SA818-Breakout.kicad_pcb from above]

Board: 2 copper layers, 56.0 x 49.0 mm, 21 parts (0 on the bottom side), 14 nets.

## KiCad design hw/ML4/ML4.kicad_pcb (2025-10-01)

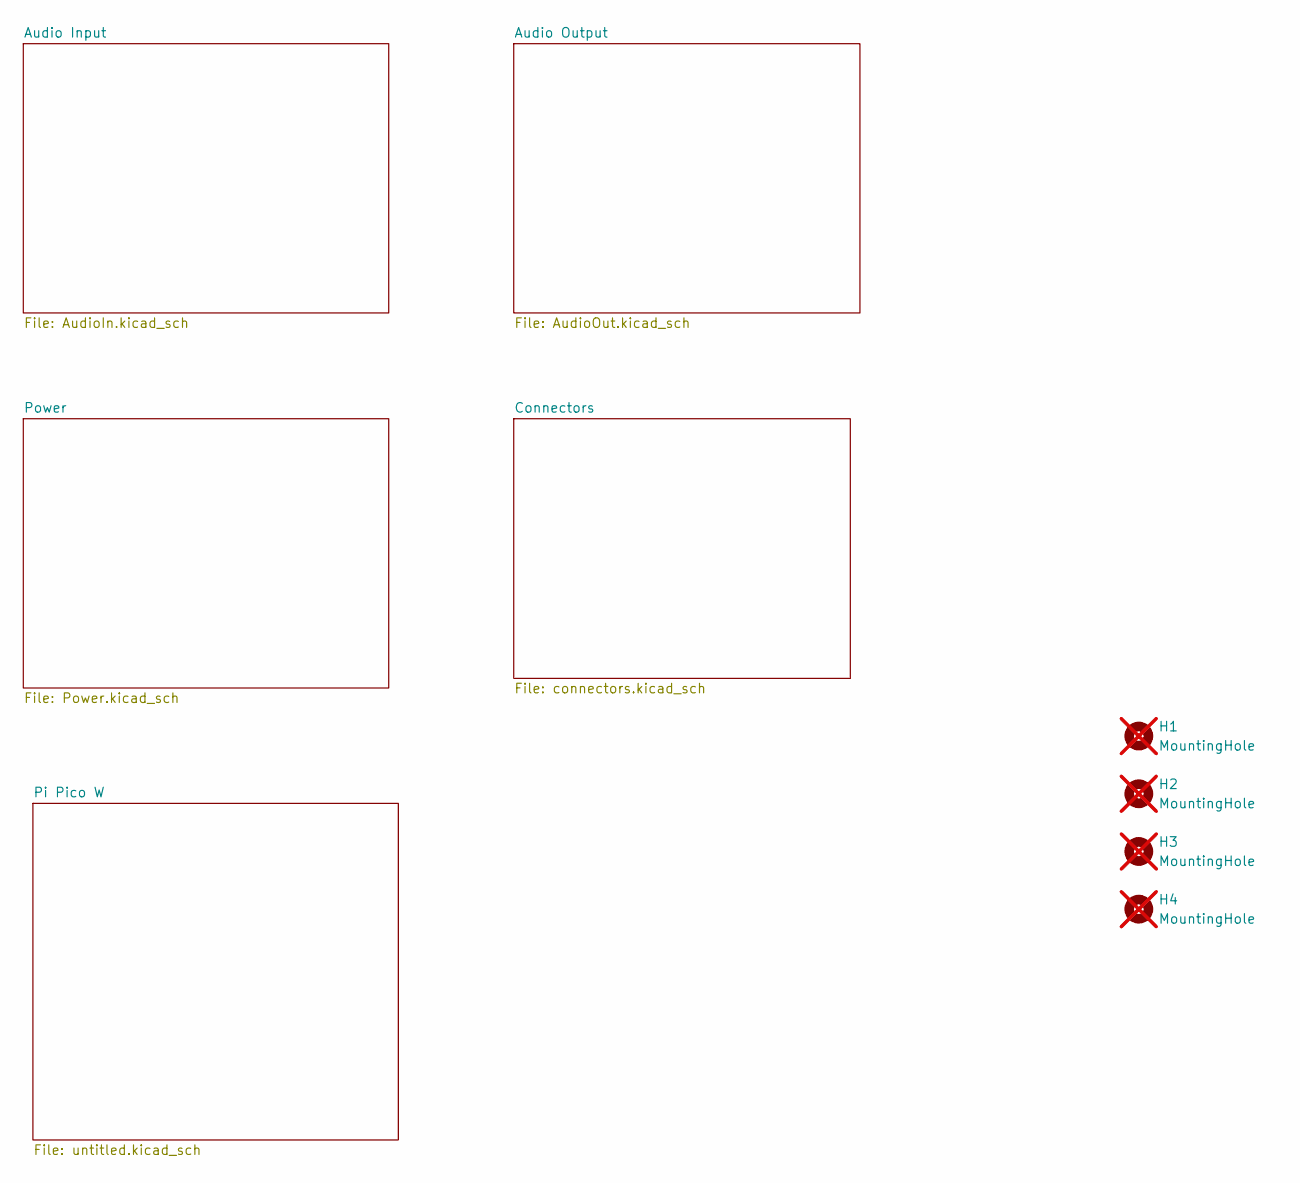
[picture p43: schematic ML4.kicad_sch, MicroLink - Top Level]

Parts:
H1, H2, H3, H4: MountingHole; MountingHole_4mm; not fitted

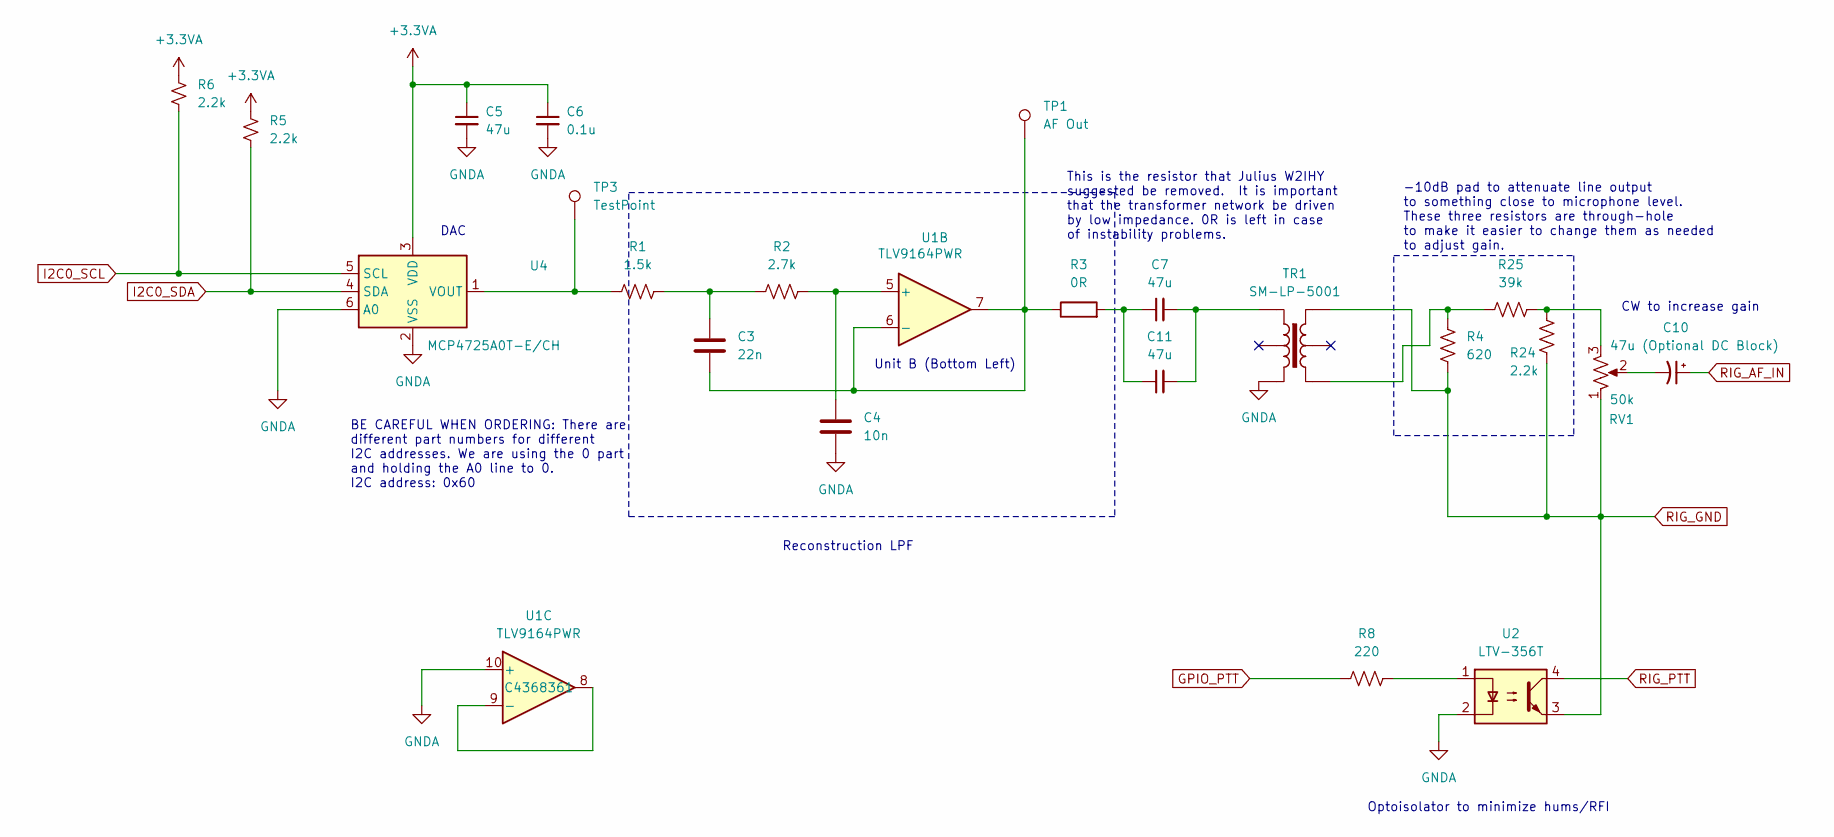
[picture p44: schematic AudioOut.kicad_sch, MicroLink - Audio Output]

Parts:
C3: 22n; C_0805_2012Metric_Pad1.18x1.45mm_HandSolder; LCSC C1729
C4: 10n; C_0805_2012Metric_Pad1.18x1.45mm_HandSolder; LCSC C1710
C5, C7, C11: 47u; C_0805_2012Metric_Pad1.18x1.45mm_HandSolder; LCSC C16780
C6: 0.1u; C_0805_2012Metric_Pad1.18x1.45mm_HandSolder; LCSC C28233
C10: 47u (Optional DC Block); CP_Radial_D5.0mm_P2.50mm; LCSC C22320
R1: 1.5k; R_0805_2012Metric_Pad1.20x1.40mm_HandSolder; LCSC C4310
R2: 2.7k; R_0805_2012Metric_Pad1.20x1.40mm_HandSolder; LCSC C17530
R3: 0R; R_1206_3216Metric_Pad1.30x1.75mm_HandSolder; LCSC C17477
R4: 620; R_Axial_DIN0309_L9.0mm_D3.2mm_P2.54mm_Vertical; LCSC C58633
R5, R6: 2.2k; R_0805_2012Metric_Pad1.20x1.40mm_HandSolder; LCSC C17520
R8: 220; R_0805_2012Metric_Pad1.20x1.40mm_HandSolder; LCSC C17557
R24: 2.2k; R_Axial_DIN0309_L9.0mm_D3.2mm_P2.54mm_Vertical; LCSC C58595
R25: 39k; R_Axial_DIN0309_L9.0mm_D3.2mm_P2.54mm_Vertical; LCSC C58645
RV1: 50k; POT_3362P; LCSC C81264
TP1: AF Out; TestPoint_Pad_2.5x2.5mm
TP3: TestPoint; TestPoint_Pad_2.5x2.5mm
TR1: SM-LP-5001; TRAN6_SM-LP-5001_BRN; LCSC C7503474
U1: TLV9164PWR; TSSOP-14_4.4x5mm_P0.65mm; LCSC C4368361
U2: LTV-356T; SO-4_4.4x3.6mm_P2.54mm; LCSC C125117
U4: MCP4725A0T-E/CH; SOT-23-6; LCSC C144198

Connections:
+3.3VA: C5.1, C6.1, R5.1, R6.1, U4.3 (VDD); also elsewhere on the board
GNDA: C4.2, C5.2, C6.2, TR1.3, U1.10 (+), U2.2, U4.2 (VSS), U4.6 (A0); also elsewhere on the board
GPIO_PTT: R8.1; also elsewhere on the board
I2C0_SCL: R6.2, U4.5 (SCL); also elsewhere on the board
I2C0_SDA: R5.2, U4.4 (SDA); also elsewhere on the board
unnamed: C3.1, R1.1, R2.1
unnamed: C10.2, RV1.2
unnamed: C7.1, C11.1, R3.2
unnamed: C7.2, C11.2, TR1.1
unnamed: R8.2, U2.1
unnamed: R24.2, R25.2, RV1.3
unnamed: R4.1, R25.1, TR1.4
unnamed: C4.1, R2.2, U1.5 (+)
unnamed: C3.2, R3.1, TP1.1, U1.6 (-), U1.7
unnamed: U1.8, U1.9 (-)
unnamed: R1.2, TP3.1, U4.1 (VOUT)
RIG_AF_IN: C10.1; also elsewhere on the board
RIG_GND: R4.2, R24.1, RV1.1, TR1.6, U2.3; also elsewhere on the board
RIG_PTT: U2.4; also elsewhere on the board

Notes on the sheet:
Reconstruction LPF
CW to increase gain
BE CAREFUL WHEN ORDERING: There are different part numbers for different I2C addresses. We are using the 0 part and holding the A0 line to 0. I2C address: 0x60
Optoisolator to minimize hums/RFI
-10dB pad to attenuate line output to something close to microphone level. These three resistors are through-hole to make it easier to change them as needed to adjust gain.
DAC
Unit B (Bottom Left)
This is the resistor that Julius W2IHY suggested be removed. It is important that the transformer network be driven by low impedance. 0R is left in case of instability problems.

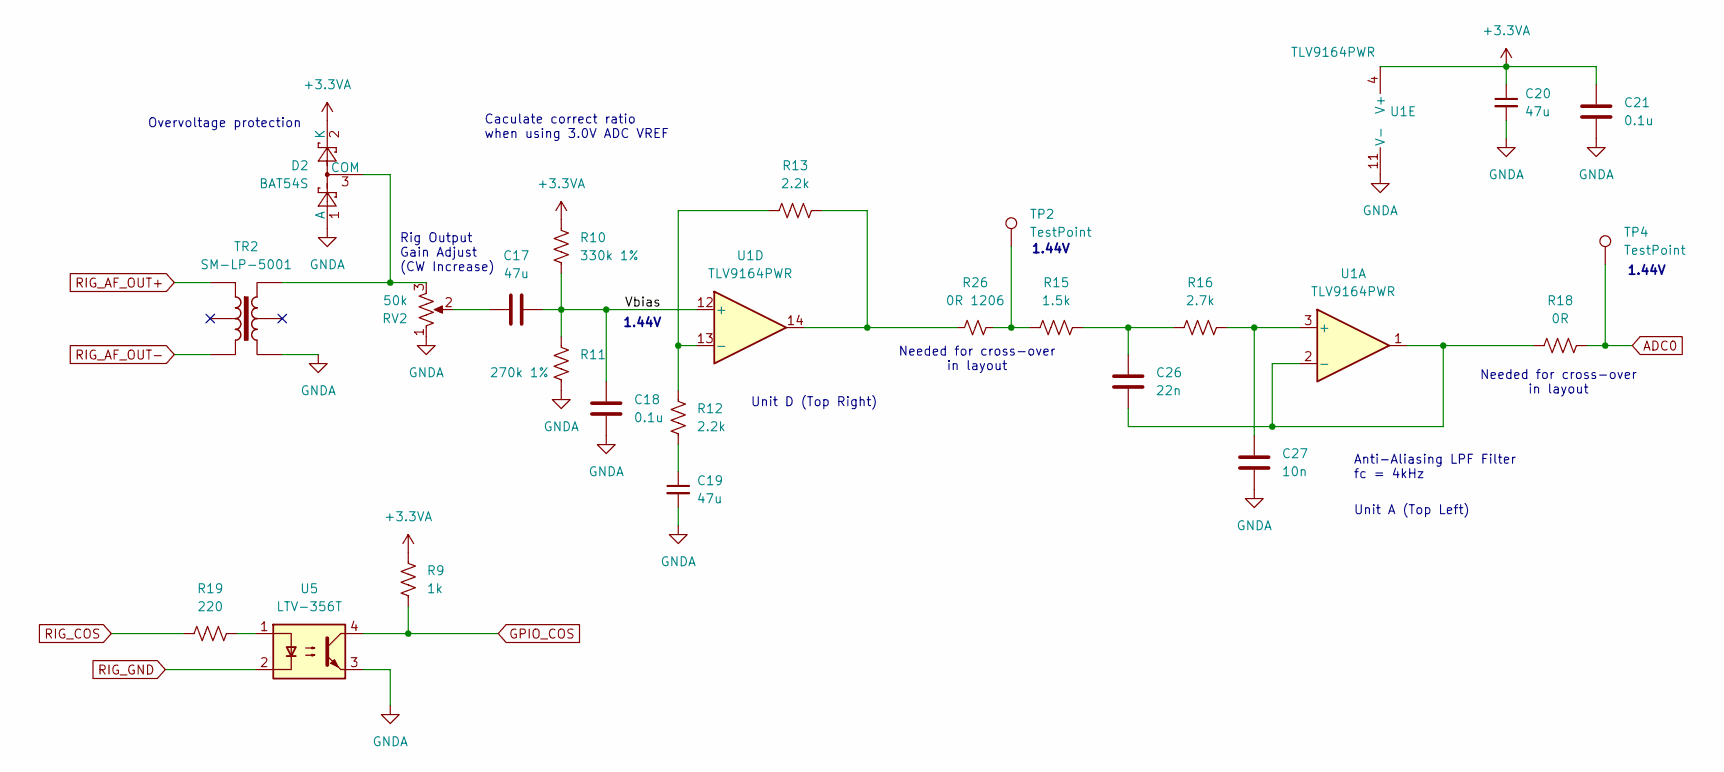
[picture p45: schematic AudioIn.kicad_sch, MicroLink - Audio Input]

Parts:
C17, C19, C20: 47u; C_0805_2012Metric_Pad1.18x1.45mm_HandSolder; LCSC C16780
C18, C21: 0.1u; C_0805_2012Metric_Pad1.18x1.45mm_HandSolder; LCSC C28233
C26: 22n; C_0805_2012Metric_Pad1.18x1.45mm_HandSolder; LCSC C1729
C27: 10n; C_0805_2012Metric_Pad1.18x1.45mm_HandSolder; LCSC C1710
D2: BAT54S; SOT-23; LCSC C12765
R9: 1k; R_0805_2012Metric_Pad1.20x1.40mm_HandSolder; LCSC C17513
R10: 330k 1%; R_0805_2012Metric_Pad1.20x1.40mm_HandSolder; LCSC C17629
R11: 270k 1%; R_0805_2012Metric_Pad1.20x1.40mm_HandSolder; LCSC C17589
R12, R13: 2.2k; R_0805_2012Metric_Pad1.20x1.40mm_HandSolder; LCSC C17520
R15: 1.5k; R_0805_2012Metric_Pad1.20x1.40mm_HandSolder; LCSC C4310
R16: 2.7k; R_0805_2012Metric_Pad1.20x1.40mm_HandSolder; LCSC C17530
R18: 0R; R_0805_2012Metric_Pad1.20x1.40mm_HandSolder; LCSC C17477
R19: 220; R_0805_2012Metric_Pad1.20x1.40mm_HandSolder; LCSC C17557
R26: 0R 1206; R_1206_3216Metric_Pad1.30x1.75mm_HandSolder; LCSC C17888
RV2: 50k; POT_3362P; LCSC C81264
TP2, TP4: TestPoint; TestPoint_Pad_2.5x2.5mm
TR2: SM-LP-5001; TRAN6_SM-LP-5001_BRN; LCSC C7503474
U1: TLV9164PWR; TSSOP-14_4.4x5mm_P0.65mm; LCSC C4368361
U5: LTV-356T; SO-4_4.4x3.6mm_P2.54mm; LCSC C125117

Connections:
+3.3VA: C20.1, C21.1, D2.2 (K), R9.1, R10.1, U1.4 (V+); also elsewhere on the board
/Audio Input/Vbias: C17.2, C18.1, R10.2, R11.1, U1.12 (+)
ADC0: R18.2, TP4.1; also elsewhere on the board
GNDA: C18.2, C19.2, C20.2, C21.2, C27.2, D2.1 (A), R11.2, RV2.1, TR2.4, U1.11 (V-), U5.3; also elsewhere on the board
GPIO_COS: R9.2, U5.4; also elsewhere on the board
unnamed: C17.1, RV2.2
unnamed: C19.1, R12.1
unnamed: C26.1, R15.1, R16.1
unnamed: D2.3 (COM), RV2.3, TR2.6
unnamed: R13.2, R26.1, U1.14
unnamed: R15.2, R26.2, TP2.1
unnamed: R19.2, U5.1
unnamed: C27.1, R16.2, U1.3 (+)
unnamed: C26.2, R18.1, U1.1, U1.2 (-)
unnamed: R12.2, R13.1, U1.13 (-)
RIG_AF_OUT+: TR2.1; also elsewhere on the board
RIG_AF_OUT-: TR2.3; also elsewhere on the board
RIG_COS: R19.1; also elsewhere on the board
RIG_GND: U5.2; also elsewhere on the board

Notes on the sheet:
Rig Output Gain Adjust (CW Increase)
Overvoltage protection
Unit D (Top Right)
1.44V
Unit A (Top Left)
Needed for cross-over in layout
Anti-Aliasing LPF Filter fc = 4kHz
Caculate correct ratio when using 3.0V ADC VREF

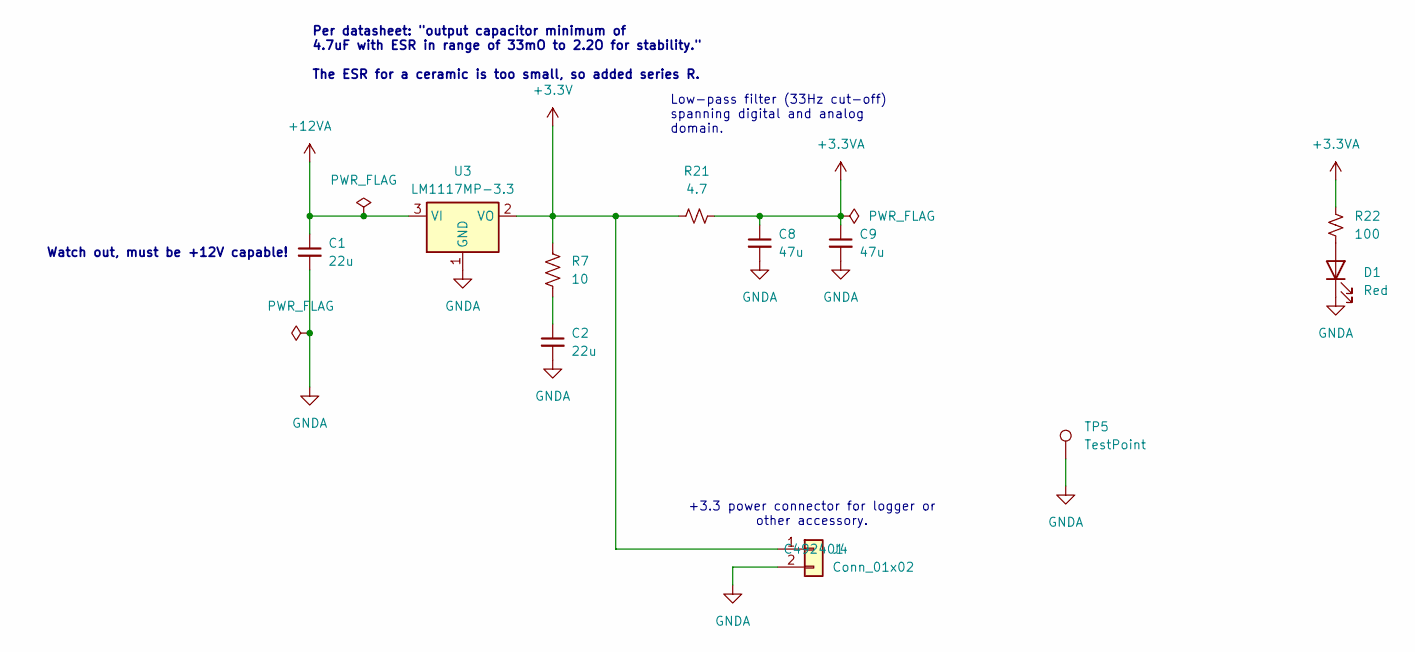
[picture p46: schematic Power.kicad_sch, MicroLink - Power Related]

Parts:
C1, C2: 22u; C_0805_2012Metric_Pad1.18x1.45mm_HandSolder; LCSC C45783
C8, C9: 47u; C_0805_2012Metric_Pad1.18x1.45mm_HandSolder; LCSC C16780
D1: Red; LED_0805_2012Metric_Pad1.15x1.40mm_HandSolder; LCSC C84256
J4: Conn_01x02; PinHeader_1x02_P2.54mm_Vertical; LCSC C492401
R7: 10; R_0805_2012Metric_Pad1.20x1.40mm_HandSolder; LCSC C17415
R21: 4.7; R_0805_2012Metric_Pad1.20x1.40mm_HandSolder; LCSC C17675
R22: 100; R_0805_2012Metric_Pad1.20x1.40mm_HandSolder; LCSC C17408
TP5: TestPoint; TestPoint_Pad_2.5x2.5mm
U3: LM1117MP-3.3; SOT-223-3_TabPin2; LCSC C9662

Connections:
+3.3V: J4.1, R7.1, R21.1, U3.2 (VO); also elsewhere on the board
+3.3VA: C8.1, C9.1, R21.2, R22.1; also elsewhere on the board
+12VA: C1.1, U3.3 (VI); also elsewhere on the board
GNDA: C1.2, C2.2, C8.2, C9.2, D1.1 (K), J4.2, TP5.1, U3.1 (GND); also elsewhere on the board
unnamed: C2.1, R7.2
unnamed: D1.2 (A), R22.2

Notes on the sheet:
+3.3 power connector for logger or other accessory.
Watch out, must be +12V capable!
Low-pass filter (33Hz cut-off) spanning digital and analog domain.
Per datasheet: "output capacitor minimum of 4.7uF with ESR in range of 33mO to 2.2O for stability." The ESR for a ceramic is too small, so added series R.

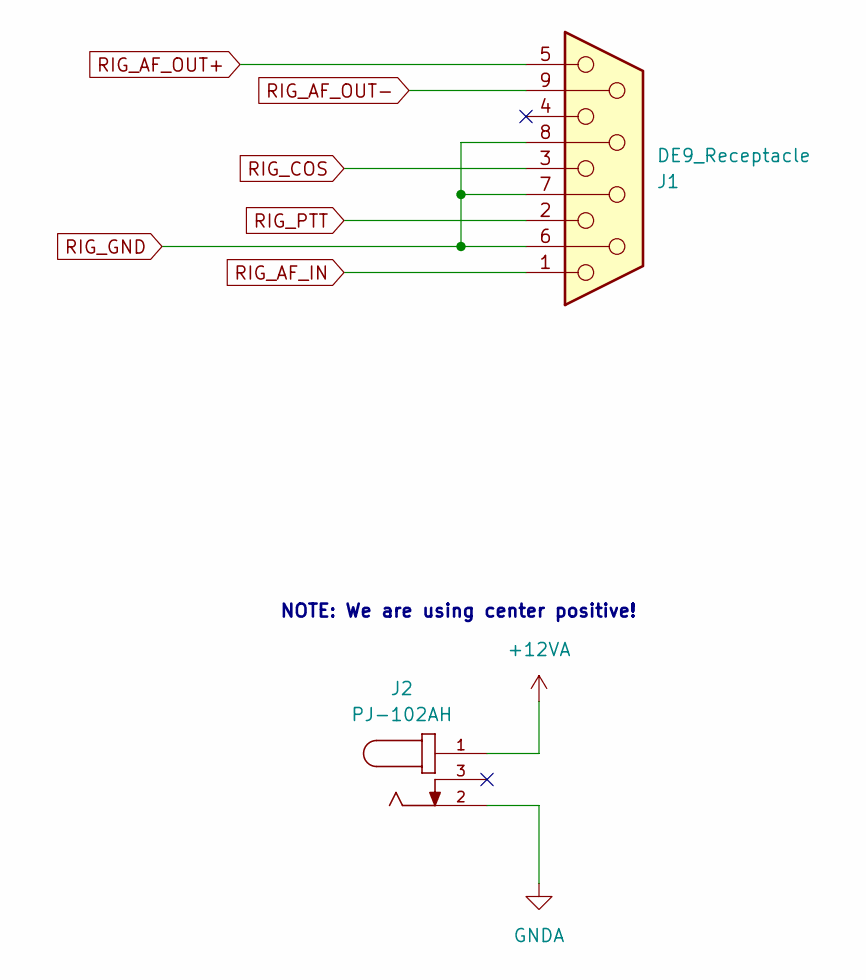
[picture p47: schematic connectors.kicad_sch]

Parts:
J1: DE9_Receptacle; CONN_A-DF 09 A&slash_KG-T2S_ASM; LCSC C17515865
J2: PJ-102AH; Power_5.5mm_CUI_PJ-102AH; LCSC C3096093

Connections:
+12VA: J2.1; also elsewhere on the board
GNDA: J2.2; also elsewhere on the board
RIG_AF_IN: J1.1; also elsewhere on the board
RIG_AF_OUT+: J1.5; also elsewhere on the board
RIG_AF_OUT-: J1.9; also elsewhere on the board
RIG_COS: J1.3; also elsewhere on the board
RIG_GND: J1.6, J1.7, J1.8; also elsewhere on the board
RIG_PTT: J1.2; also elsewhere on the board

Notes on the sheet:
NOTE: We are using center positive!

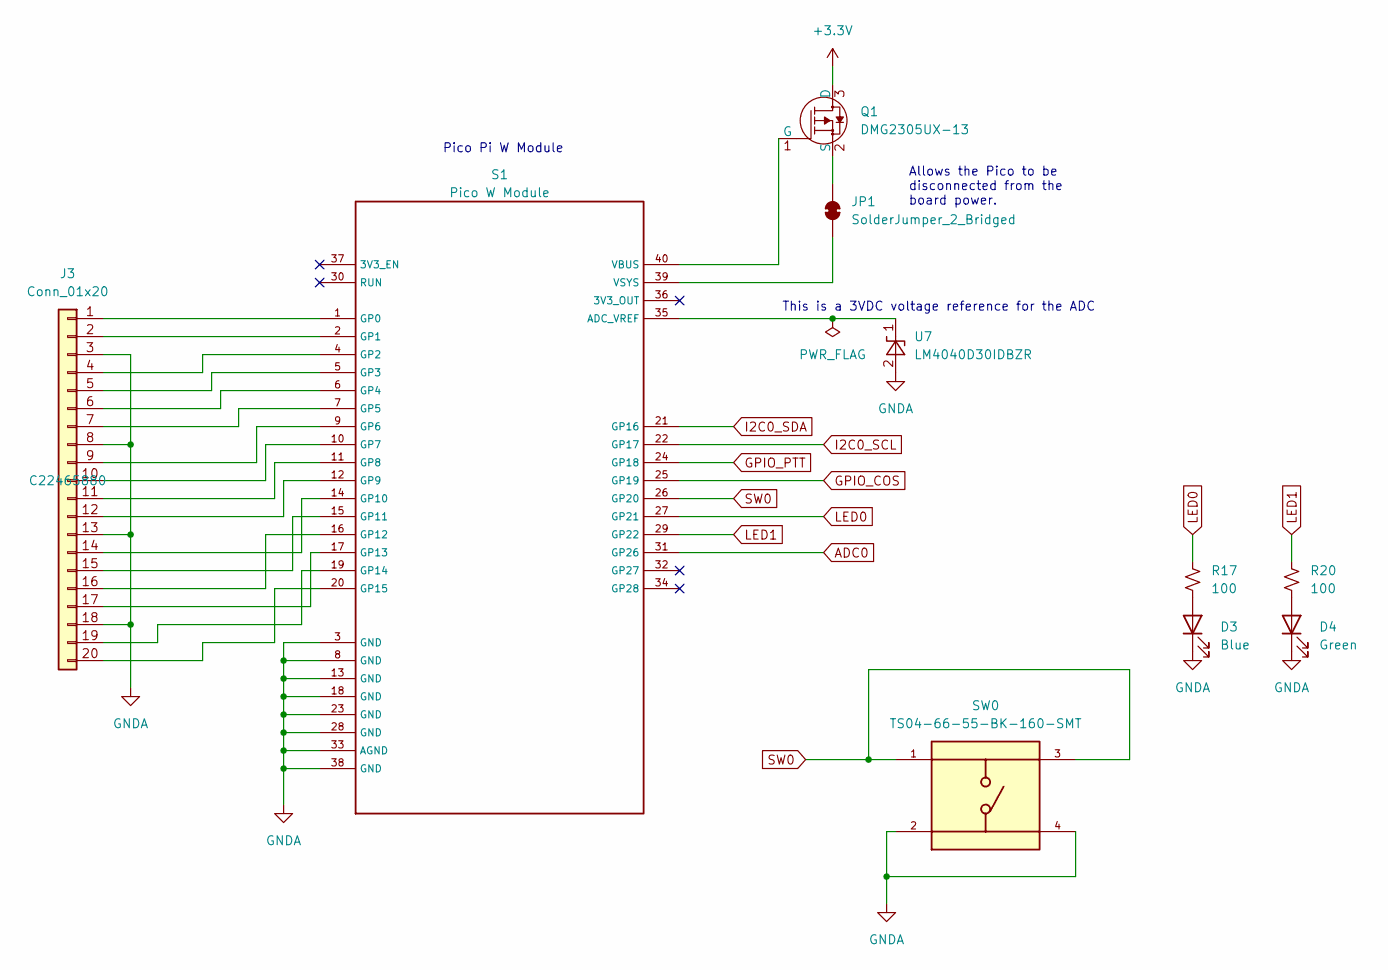
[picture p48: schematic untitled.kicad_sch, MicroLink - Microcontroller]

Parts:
D3: Blue; LED_0805_2012Metric_Pad1.15x1.40mm_HandSolder; LCSC C84259
D4: Green; LED_0805_2012Metric_Pad1.15x1.40mm_HandSolder; LCSC C2297
J3: Conn_01x20; PinHeader_1x20_P2.54mm_Vertical; LCSC C22465880
JP1: SolderJumper_2_Bridged; SolderJumper-2_P1.3mm_Bridged_Pad1.0x1.5mm
Q1: DMG2305UX-13; SOT-23_Handsoldering; MPN DMG2305UX-13; Digi-Key_PN DMG2305UX-13DICT-ND
R17, R20: 100; R_0805_2012Metric_Pad1.20x1.40mm_HandSolder; LCSC C17408
S1: Pico W Module; RPi_PicoW_SMD_TH; LCSC C7203003
SW0: TS04-66-55-BK-160-SMT; SW_TS04-66-55-BK-160-SMT; PARTREV 1.0; LCSC C4364775
U7: LM4040D30IDBZR; SOT-23; LCSC C2157213

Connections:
+3.3V: Q1.3 (D); also elsewhere on the board
ADC0: S1.31 (GP26); also elsewhere on the board
GNDA: D3.1 (K), D4.1 (K), J3.3, J3.8, J3.13, J3.18, S1.3 (GND), S1.8 (GND), S1.13 (GND), S1.18 (GND), S1.23 (GND), S1.28 (GND), S1.33 (AGND), S1.38 (GND), SW0.2, SW0.4, U7.2 (A); also elsewhere on the board
GPIO_COS: S1.25 (GP19); also elsewhere on the board
GPIO_PTT: S1.24 (GP18); also elsewhere on the board
I2C0_SCL: S1.22 (GP17); also elsewhere on the board
I2C0_SDA: S1.21 (GP16); also elsewhere on the board
LED0: R17.1, S1.27 (GP21)
LED1: R20.1, S1.29 (GP22)
unnamed: D3.2 (A), R17.2
unnamed: D4.2 (A), R20.2
unnamed: J3.1, S1.1 (GP0)
unnamed: J3.2, S1.2 (GP1)
unnamed: J3.4, S1.4 (GP2)
unnamed: J3.5, S1.5 (GP3)
unnamed: J3.6, S1.6 (GP4)
unnamed: J3.7, S1.7 (GP5)
unnamed: J3.9, S1.9 (GP6)
unnamed: J3.10, S1.10 (GP7)
unnamed: J3.11, S1.11 (GP8)
unnamed: J3.12, S1.12 (GP9)
unnamed: J3.14, S1.14 (GP10)
unnamed: J3.15, S1.15 (GP11)
unnamed: J3.16, S1.16 (GP12)
unnamed: J3.17, S1.17 (GP13)
unnamed: J3.19, S1.19 (GP14)
unnamed: J3.20, S1.20 (GP15)
unnamed: JP1.1 (A), S1.39 (VSYS)
unnamed: JP1.2 (B), Q1.2 (S)
unnamed: Q1.1 (G), S1.40 (VBUS)
unnamed: S1.35 (ADC_VREF), U7.1 (K)
SW0: S1.26 (GP20), SW0.1, SW0.3

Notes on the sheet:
This is a 3VDC voltage reference for the ADC
Allows the Pico to be disconnected from the board power.
Pico Pi W Module

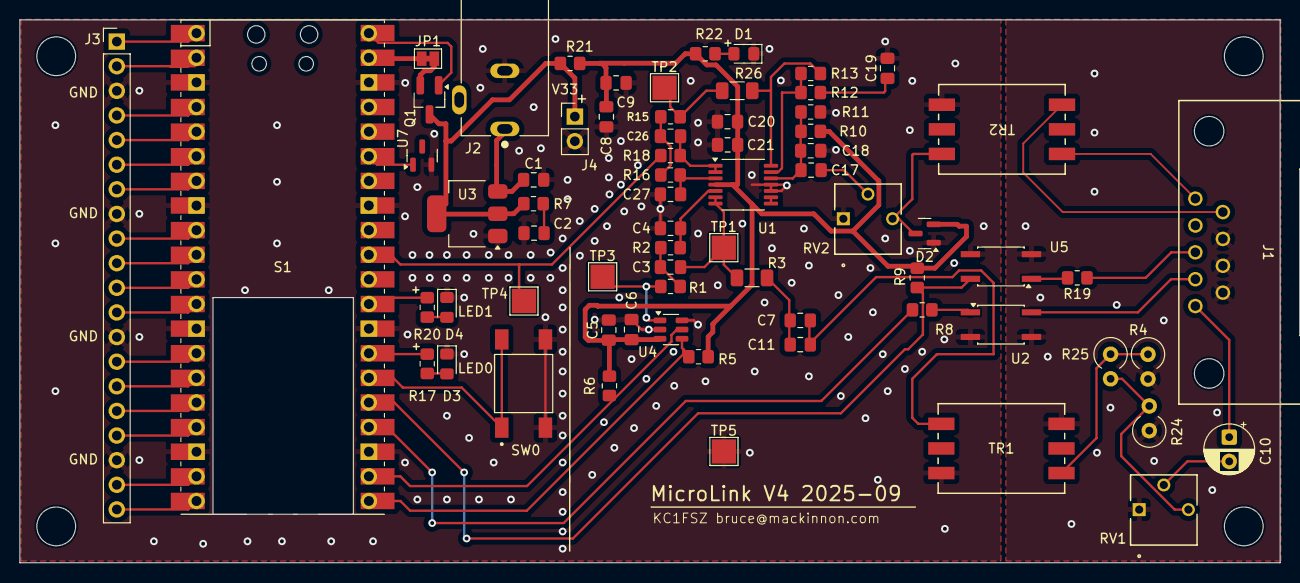
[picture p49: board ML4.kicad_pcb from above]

Board: 2 copper layers, 130.0 x 56.0 mm, 73 parts (0 on the bottom side), 64 nets.

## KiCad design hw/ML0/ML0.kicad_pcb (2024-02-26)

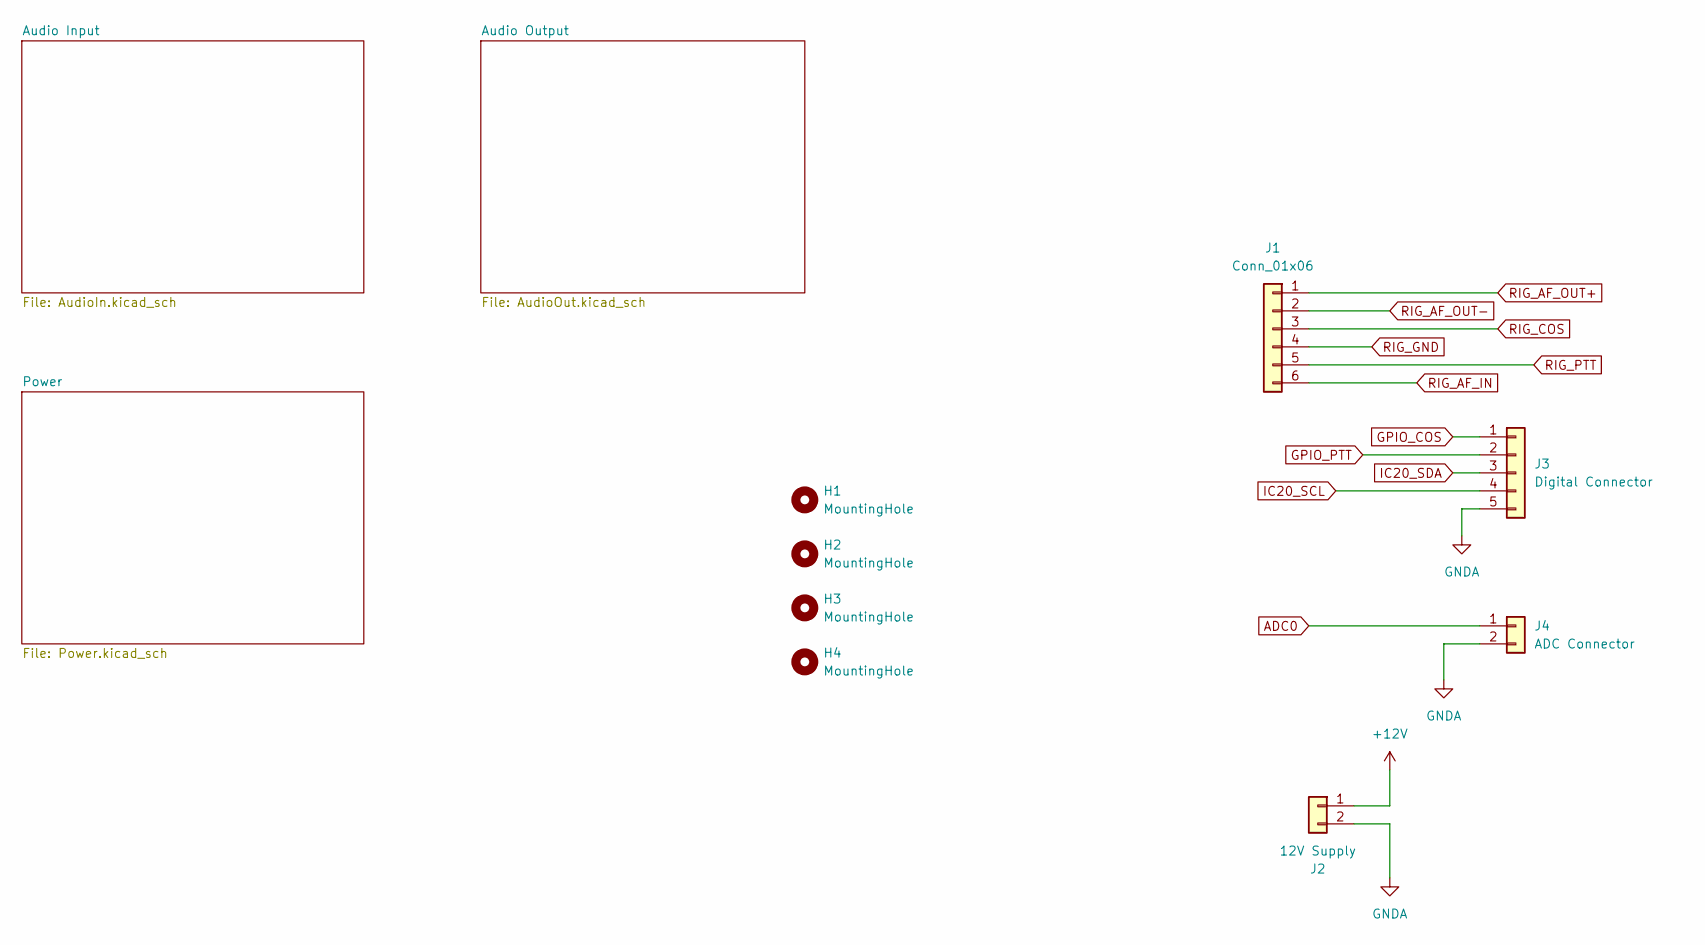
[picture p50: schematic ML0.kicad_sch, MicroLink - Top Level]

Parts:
H1, H2, H3, H4: MountingHole; MountingHole_4mm
J1: Conn_01x06; PinHeader_1x06_P2.54mm_Vertical
J2: 12V Supply; PinHeader_1x02_P2.54mm_Vertical
J3: Digital Connector; PinHeader_1x05_P2.54mm_Vertical
J4: ADC Connector; PinHeader_1x02_P2.54mm_Vertical

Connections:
+12V: J2.1; also elsewhere on the board
ADC0: J4.1; also elsewhere on the board
GNDA: J2.2, J3.5, J4.2; also elsewhere on the board
GPIO_COS: J3.1; also elsewhere on the board
GPIO_PTT: J3.2; also elsewhere on the board
IC20_SCL: J3.4; also elsewhere on the board
IC20_SDA: J3.3; also elsewhere on the board
RIG_AF_IN: J1.6; also elsewhere on the board
RIG_AF_OUT+: J1.1; also elsewhere on the board
RIG_AF_OUT-: J1.2; also elsewhere on the board
RIG_COS: J1.3; also elsewhere on the board
RIG_GND: J1.4; also elsewhere on the board
RIG_PTT: J1.5; also elsewhere on the board

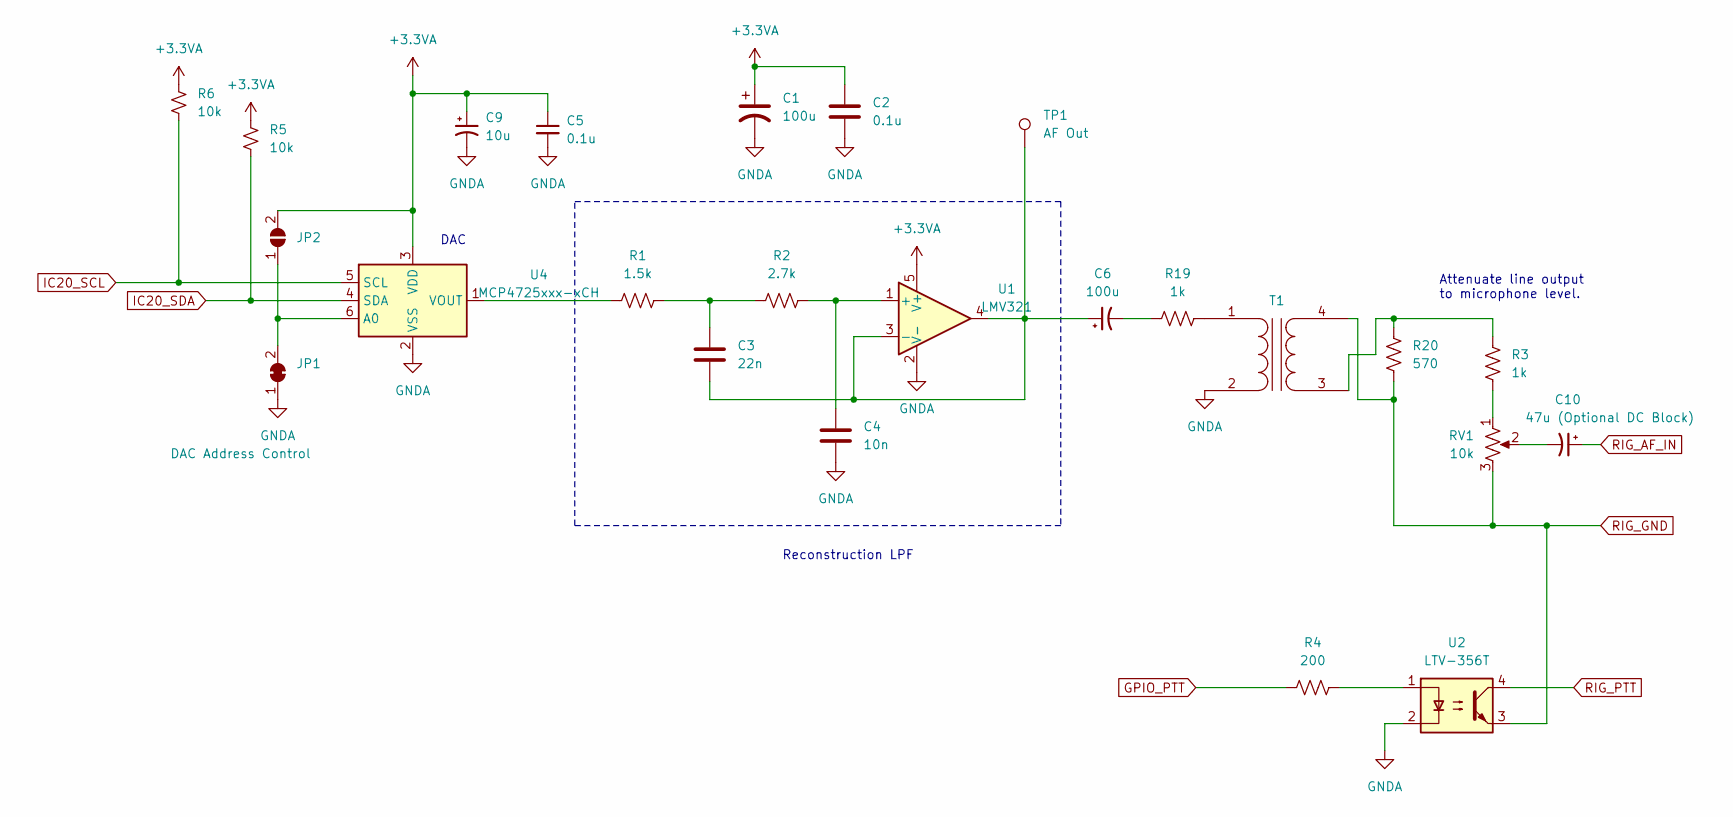
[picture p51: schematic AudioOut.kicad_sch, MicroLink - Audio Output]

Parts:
C1, C6: 100u; CAP_KEMET_530_530
C2, C5: 0.1u; C_0805_2012Metric_Pad1.18x1.45mm_HandSolder
C3: 22n; C_0805_2012Metric_Pad1.18x1.45mm_HandSolder
C4: 10n; C_0805_2012Metric_Pad1.18x1.45mm_HandSolder
C9: 10u; CAP_KEMET_530_530
C10: 47u (Optional DC Block); CP_Radial_D5.0mm_P2.50mm
JP1: DAC Address Control; SolderJumper-2_P1.3mm_Bridged_Pad1.0x1.5mm
JP2: SolderJumper_2_Open; SolderJumper-2_P1.3mm_Open_Pad1.0x1.5mm
R1: 1.5k; R_0805_2012Metric_Pad1.20x1.40mm_HandSolder
R2: 2.7k; R_0805_2012Metric_Pad1.20x1.40mm_HandSolder
R3, R19: 1k; R_0805_2012Metric_Pad1.20x1.40mm_HandSolder
R4: 200; R_0805_2012Metric_Pad1.20x1.40mm_HandSolder
R5, R6: 10k; R_0805_2012Metric_Pad1.20x1.40mm_HandSolder
R20: 570; R_0805_2012Metric_Pad1.20x1.40mm_HandSolder
RV1: 10k; POT_3362P
T1: Transformer_1P_1S; CheapAudioTransformer
TP1: AF Out; TestPoint_Pad_2.5x2.5mm
U1: LMV321; SOT-23-5_HandSoldering
U2: LTV-356T; SO-4_4.4x3.6mm_P2.54mm
U4: MCP4725xxx-xCH; SOT-23-6

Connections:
+3.3VA: C1.1, C2.1, C5.1, C9.1, JP2.2 (B), R5.1, R6.1, U1.5 (V+), U4.3 (VDD); also elsewhere on the board
GNDA: C1.2, C2.2, C4.2, C5.2, C9.2, JP1.1 (A), T1.2 (AB), U1.2 (V-), U2.2, U4.2 (VSS); also elsewhere on the board
GPIO_PTT: R4.1; also elsewhere on the board
IC20_SCL: R6.2, U4.5 (SCL); also elsewhere on the board
IC20_SDA: R5.2, U4.4 (SDA); also elsewhere on the board
unnamed: C3.1, R1.1, R2.1
unnamed: C6.2, R19.1
unnamed: C10.2, RV1.2
unnamed: JP1.2 (B), JP2.1 (A), U4.6 (A0)
unnamed: R3.2, RV1.1
unnamed: R4.2, U2.1
unnamed: R19.2, T1.1 (AA)
unnamed: R3.1, R20.1, T1.3 (SA)
unnamed: C4.1, R2.2, U1.1 (+)
unnamed: C3.2, C6.1, TP1.1, U1.3 (-), U1.4
unnamed: R1.2, U4.1 (VOUT)
RIG_AF_IN: C10.1; also elsewhere on the board
RIG_GND: R20.2, RV1.3, T1.4 (SB), U2.3; also elsewhere on the board
RIG_PTT: U2.4; also elsewhere on the board

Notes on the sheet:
Reconstruction LPF
Attenuate line output to microphone level.
DAC

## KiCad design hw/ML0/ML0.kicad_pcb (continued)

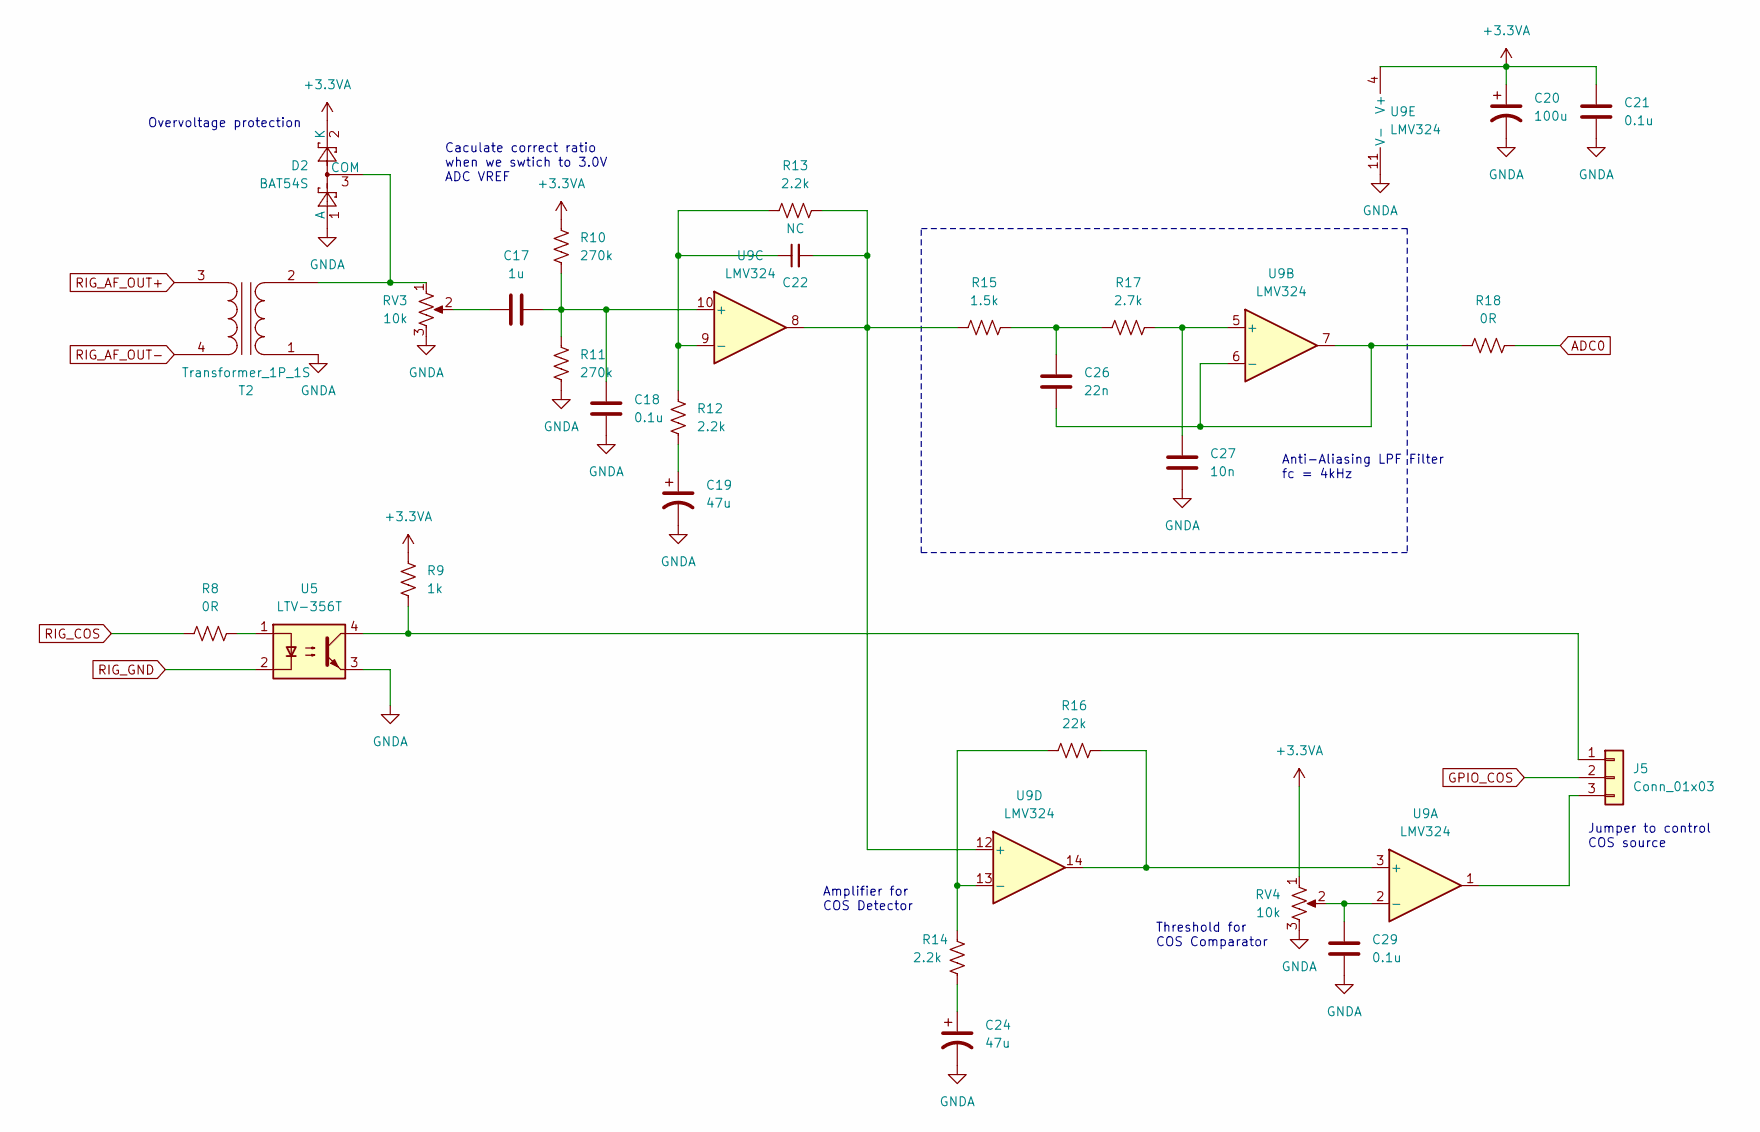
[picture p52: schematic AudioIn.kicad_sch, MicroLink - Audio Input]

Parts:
C17: 1u; C_0805_2012Metric_Pad1.18x1.45mm_HandSolder
C18, C21, C29: 0.1u; C_0805_2012Metric_Pad1.18x1.45mm_HandSolder
C19, C24: 47u; CAP_KEMET_530_530
C20: 100u; CAP_KEMET_530_530
C22: NC; C_0805_2012Metric_Pad1.18x1.45mm_HandSolder
C26: 22n; C_0805_2012Metric_Pad1.18x1.45mm_HandSolder
C27: 10n; C_0805_2012Metric_Pad1.18x1.45mm_HandSolder
D2: BAT54S; SOT-23
J5: Conn_01x03; PinHeader_1x03_P2.54mm_Vertical
R8, R18: 0R; R_0805_2012Metric_Pad1.20x1.40mm_HandSolder
R9: 1k; R_0805_2012Metric_Pad1.20x1.40mm_HandSolder
R10, R11: 270k; R_0805_2012Metric_Pad1.20x1.40mm_HandSolder
R12, R13, R14: 2.2k; R_0805_2012Metric_Pad1.20x1.40mm_HandSolder
R15: 1.5k; R_0805_2012Metric_Pad1.20x1.40mm_HandSolder
R16: 22k; R_0805_2012Metric_Pad1.20x1.40mm_HandSolder
R17: 2.7k; R_0805_2012Metric_Pad1.20x1.40mm_HandSolder
RV3, RV4: 10k; POT_3362P
T2: Transformer_1P_1S; CheapAudioTransformer
U5: LTV-356T; SO-4_4.4x3.6mm_P2.54mm
U9: LMV324; TSSOP-14_4.4x5mm_P0.65mm

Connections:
+3.3VA: C20.1, C21.1, D2.2 (K), R9.1, R10.1, RV4.1, U9.4 (V+); also elsewhere on the board
ADC0: R18.2; also elsewhere on the board
GNDA: C18.2, C19.2, C20.2, C21.2, C24.2, C27.2, C29.2, D2.1 (A), R11.2, RV3.3, RV4.3, T2.1 (AA), U5.3, U9.11 (V-); also elsewhere on the board
GPIO_COS: J5.2; also elsewhere on the board
unnamed: C17.1, RV3.2
unnamed: C19.1, R12.1
unnamed: C24.1, R14.1
unnamed: C26.1, R15.1, R17.1
unnamed: D2.3 (COM), RV3.1, T2.2 (AB)
unnamed: J5.1, R9.2, U5.4
unnamed: J5.3, U9.1
unnamed: R8.2, U5.1
unnamed: R16.2, U9.3 (+), U9.14
unnamed: C29.1, RV4.2, U9.2 (-)
unnamed: C27.1, R17.2, U9.5 (+)
unnamed: C26.2, R18.1, U9.6 (-), U9.7
unnamed: C17.2, C18.1, R10.2, R11.1, U9.10 (+)
unnamed: C22.1, R12.2, R13.1, U9.9 (-)
unnamed: C22.2, R13.2, R15.2, U9.8, U9.12 (+)
unnamed: R14.2, R16.1, U9.13 (-)
RIG_AF_OUT+: T2.3 (SA); also elsewhere on the board
RIG_AF_OUT-: T2.4 (SB); also elsewhere on the board
RIG_COS: R8.1; also elsewhere on the board
RIG_GND: U5.2; also elsewhere on the board

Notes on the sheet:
Overvoltage protection
Amplifier for COS Detector
Threshold for COS Comparator
Jumper to control COS source
Anti-Aliasing LPF Filter fc = 4kHz
Caculate correct ratio when we swtich to 3.0V ADC VREF


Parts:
C7, C8: 10u; CAP_KEMET_530_530
D1: LED; LED_0805_2012Metric_Pad1.15x1.40mm_HandSolder
R7: 220; R_0805_2012Metric_Pad1.20x1.40mm_HandSolder
U3: NCP1117-3.3_SOT223; SOT-223-3_TabPin2

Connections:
+3.3VA: C7.1, R7.1, U3.2 (VO); also elsewhere on the board
+12V: C8.1, U3.3 (VI); also elsewhere on the board
GNDA: C7.2, C8.2, D1.1 (K), U3.1 (GND); also elsewhere on the board
unnamed: D1.2 (A), R7.2


Board: 2 copper layers, 100.0 x 59.0 mm, 65 parts (0 on the bottom side), 42 nets.

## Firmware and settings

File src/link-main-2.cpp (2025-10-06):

/**
 * MicroLink EchoLink Station
 * Copyright (C) 2024, Bruce MacKinnon KC1FSZ
 *
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
 * FOR AMATEUR RADIO USE ONLY.
 * NOT FOR COMMERCIAL USE WITHOUT PERMISSION.
 * 
 * =================================================================================
 * This file is unit-test code only.  None of this should be use for 
 * real applications!
 * =================================================================================
 * 
 * This test runs on the RP2040 hardware and provides a fairly comprehensive test
 * of connection, logon, and receipt of audio packets from the *ECHOTEST* station.
*/
/*
Build commands:

    cd build
    cmake -DPICO_BOARD=pico_w ..
    make link-main-2

Launch command:
    openocd -f interface/raspberrypi-swd.cfg -f target/rp2040.cfg -c "program link-main-2.elf verify reset exit"
*/
#include <ios>
#include <iostream>
#include <fstream>
#include <cassert>
#include <cstring>
#include <string>
#include <thread>
#include <chrono>
#include <cmath>
#include <atomic>
#include <functional>

#include "pico/stdlib.h"
#include "pico/time.h"
#include "hardware/gpio.h"
#include "hardware/i2c.h"
#include "hardware/uart.h"
#include "hardware/irq.h"
#include "hardware/sync.h"
#include "hardware/watchdog.h"
#include "hardware/flash.h"

// ======= Internet Stuff ===========
#include "pico/cyw43_arch.h"
#include "lwip/dns.h"
#include "contexts/LwIPLib.h"
// ======= Internet Stuff ===========

/*
// ======= Internet Stuff ===========
#include "kc1fsz-tools/rp2040/PicoUartChannel.h"
#include "contexts/SIM7600IPLib.h"
// ======= Internet Stuff ===========
*/

#include "kc1fsz-tools/rp2040/SerialLog.h"
#include "kc1fsz-tools/AudioAnalyzer.h"
#include "kc1fsz-tools/DTMFDetector.h"
#include "kc1fsz-tools/OutStream.h"
#include "kc1fsz-tools/CommandShell.h"
#include "kc1fsz-tools/rp2040/PicoPollTimer.h"

#include "contexts/I2CAudioOutputContext.h"
#include "contexts/PicoAudioInputContext.h"

#include "machines/DNSMachine.h"
#include "machines/LogonMachine2.h"
#include "machines/LookupMachine3.h"

#include "RXMonitor.h"
#include "Conference.h"
#include "ConferenceBridge.h"
#include "SNTPClient.h"
// TEMP
#include "tests/TestUserInfo.h"

// Monitor Server
#define MONITOR_SERVER_NAME ("monitor.w1tkz.net")
// The time the raw COS needs to be active to be consered "on"
#define COS_DEBOUNCE_ON_MS 10
// The time the raw COS needs to be inactive to be considered "off"
#define COS_DEBOUNCE_OFF_MS 400
// The time the COS is ignore immediate after a TX cycle (to avoid 
// having the transmitter interfering with the receiver
#define LINGER_AFTER_TX_MS 500
// How long we wait in silence before flushing any accumualted DTMF
// tones.
#define DMTF_ACCUMULATOR_TIMEOUT_MS (10 * 1000)
// 
#define RIG_COS_DEBOUNCE_INTERVAL_MS (500)
// The longest the rig is allowed to stay on continuously
#define TX_TIMEOUT_MS (120 * 1000)
// A window of time during which the rig is not allowed to
// be keyed.
#define TX_LOCKOUT_MS (30 * 1000)
// A limit on the TX duty cycle - used to protect transmitter finals
#define TX_DUTY_CYCLE_LIMIT_PERCENT (50)
// How long we wait between refreshing the DNS address of the 
// servers used by the node.  Important to fail-over speed.
#define DNS_INTERVAL_MS (5 * 60 * 1000)

// ===============
// LEFT SIDE PINS 
// ===============

// Physical pin 1 - SIM7600 
#define UART0_TX_PIN (0)
// Physical pin 2 - SIM7600
#define UART0_RX_PIN (1)

// Physical pin 4 - SIM7600 enable
#define SIM7600_EN_PIN (2)

// Physical pin 9. Input from physical PTT button.
#define PTT_PIN (6)

// Physical pin 10. Output to drive an LED indicating keyed status
// Green LED on ML0 board
//#define KEY_LED_PIN (7)

// Physical pin 11 - Serial data logger
#define UART1_TX_PIN (8)
// Physical pin 12 - Serial data logger
#define UART1_RX_PIN (9)

// NOTE: Physical 13 is GND

// Physical pin 14 - Rig power on
#define RIG_POWER_PIN (10)

// Physical pin 15. This is an output to drive an LED indicating
// that we are in a QSO. 
#define QSO_LED_PIN (11)

// Physical pin 20.  Used for diagnostics/timing checks
#define DIAG_PIN (15)

// ===============
// RIGHT SIDE PINS 
// ===============

// Phy Pin 21: I2C channel 0 - DAC data
#define I2C0_SDA (16) 
// Phy Pin 22: I2C channel 0 - DAC clock
#define I2C0_SCL (17) 

// Physical pin 23 - GROUND

// Physical pin 24.  This is an output (active high) used to key 
// the rig's transmitter. Typically drives an optocoupler to
// get the pull-to-ground needed by the rig.
#define RIG_KEY_PIN (18)
// Physical pin 25. This is an input (active high) used to detect
// receive carrier from the rig. 
#define RIG_COS_PIN (19)

// Output to drive an LED indicating link status
// Blue LED0 on ML1 board
#define LINK_LED_PIN (21)
// Output to drive an LED indicating keyed status
// Green LED1 on ML1 board
#define KEY_LED_PIN (22)

// Physical pin 31 - ADC input from analog section
#define ADC0_PIN (26)

// Physical pin 33 - Analog Ground

#define UART_ID uart0
#define U_BAUD_RATE 115200
#define U_DATA_BITS 8
#define U_STOP_BITS 1
#define U_PARITY UART_PARITY_NONE

// This controls the maximum delay before the watchdog
// will reboot the system
#define WATCHDOG_DELAY_MS (2 * 1000)

// The version of the configuration version that we expect 
// to find (must be at least this version)
#define CONFIG_VERSION (0xbab2)

using namespace std;
using namespace kc1fsz;

// Audio rate
static const uint32_t sampleRate = 8000;
// The size of one EchoLink audio frame (after decoding)
static const int audioFrameSize = 160;
// The number of audio frames packed into an RTP packet
static const uint32_t audioFrameBlockFactor = 4;

// Provide buffer for about a second of audio.  We round up to 16 frames worth.
static const uint32_t audioBufDepth = 16;
static const uint32_t audioBufDepthLog2 = 4;
static int16_t audioBuf[audioFrameSize * 4 * audioBufDepth];

// Make the polling work like a Runnable
class NetworkTask : public Runnable {
public:
    void run() { 
        // If you are using pico_cyw43_arch_poll, then you must poll periodically 
        // from your main loop (not from a timer) to check for Wi-Fi driver or 
        // lwIP work that needs to be done.
        cyw43_arch_poll();
    }
};

class LinkOutStream : public OutStream {
public:

    virtual int write(uint8_t b) {
        cout.write((const char *)&b, 1);
        cout.flush();
        return 1;
    }

    virtual bool isWritable() const {
        return true;
    }
};

class LinkCommandSink : public CommandSink {
public:

    virtual void process(const char* cmd) {
        if (handler) {
            handler(cmd);
        }
    }

    std::function<void(const char*)> handler = 0;
};

// Used for drawing a real-time 
static void renderStatus(PicoAudioInputContext* inCtx,
    AudioAnalyzer* rxAnalyzer, 
    AudioAnalyzer* txAnalyzer, 
    uint32_t rxNoiseThreshold, 
    bool cosState, 
    bool networkState, 
    int wifiRssi, 
    uint32_t secondsSinceLastActivity,
    ostream& str);

bool rigKeyFailSafe();

static int32_t getInternetRssi() {
    int32_t rssi = 0;
    cyw43_wifi_get_rssi(&cyw43_state, &rssi);
    return rssi;
}

static bool streq(const char* a, const char* b) {
    return strcmp(a, b) == 0;
}

static void saveConfig(const StationConfig* cfg) {
    uint32_t ints = save_and_disable_interrupts();
    // Must erase a full sector first (4096 bytes)
    flash_range_erase((PICO_FLASH_SIZE_BYTES - FLASH_SECTOR_SIZE), FLASH_SECTOR_SIZE);
    // IMPORTANT: Must be a multiple of 256!
    flash_range_program((PICO_FLASH_SIZE_BYTES - FLASH_SECTOR_SIZE), (uint8_t*)cfg, 512);
    restore_interrupts(ints);
}

static void setDefaultConfig() {
    StationConfig config;
    config.version = CONFIG_VERSION;
    strncpy(config.addressingServerHost, "naeast.echolink.org", 32);
    config.addressingServerPort = 5200;
    strncpy(config.callSign, "UNKNOWN", 32);
    strncpy(config.password, "xxx", 32);
    strncpy(config.fullName, "Unknown", 32);
    strncpy(config.location, "Unknown", 32);
    strncpy(config.wifiSsid, "Unknown", 64);
    strncpy(config.wifiPassword, "Unknown", 16);
    config.useHardCos = false;
    config.silentTimeoutS = 30 * 60;
    config.idleTimeoutS = 5 * 60;
    config.rxNoiseThreshold = 2000;
    config.adcRawOffset = -166;
    config.cosDebounceOnMs = 10;
    config.cosDebounceOffMs = 400;
    saveConfig(&config);
}

int main(int, const char**) {

    LogonMachine2::traceLevel = 0;
    ConferenceBridge::traceLevel = 0;
    Conference::traceLevel = 0;

    stdio_init_all();

    // PTT switch
    gpio_init(PTT_PIN);
    gpio_set_dir(PTT_PIN, GPIO_IN);
    gpio_pull_up(PTT_PIN);

    gpio_init(RIG_COS_PIN);
    gpio_set_dir(RIG_COS_PIN, GPIO_IN);
    gpio_pull_up(RIG_COS_PIN);

    // Key/indicator LED
    gpio_init(KEY_LED_PIN);
    gpio_set_dir(KEY_LED_PIN, GPIO_OUT);
    gpio_put(KEY_LED_PIN, 0);

    // Link indicator LED
    gpio_init(LINK_LED_PIN);
    gpio_set_dir(LINK_LED_PIN, GPIO_OUT);
    gpio_put(LINK_LED_PIN, 0);

    // QSO indicator LED
    gpio_init(QSO_LED_PIN);
    gpio_set_dir(QSO_LED_PIN, GPIO_OUT);
    gpio_put(QSO_LED_PIN, 0);

    // Rig key
    gpio_init(RIG_KEY_PIN);
    gpio_set_dir(RIG_KEY_PIN, GPIO_OUT);
    gpio_put(RIG_KEY_PIN, 0);

    // Rig power
    gpio_init(RIG_POWER_PIN);
    gpio_set_dir(RIG_POWER_PIN, GPIO_OUT);
    gpio_put(RIG_POWER_PIN, 0);

    // Diag
    gpio_init(DIAG_PIN);
    gpio_set_dir(DIAG_PIN, GPIO_OUT);
    gpio_put(DIAG_PIN, 0);

    // UART1 setup (logging)
    uart_init(uart1, 9600);
    gpio_set_function(UART1_TX_PIN, GPIO_FUNC_UART);
    gpio_set_function(UART1_RX_PIN, GPIO_FUNC_UART);
    uart_set_hw_flow(uart1, false, false);
    uart_set_format(uart1, U_DATA_BITS, U_STOP_BITS, U_PARITY);
    uart_set_fifo_enabled(uart1, true);
    uart_set_translate_crlf(uart1, false);

    // Setup I2C
    i2c_init(i2c_default, 100 * 1000);
    gpio_set_function(I2C0_SDA, GPIO_FUNC_I2C);
    gpio_set_function(I2C0_SCL, GPIO_FUNC_I2C);
    i2c_set_baudrate(i2c_default, 800000);

    // Hello indicator on boot
    for (int i = 0; i < 4; i++) {
        sleep_ms(250);
        sleep_ms(250);
    }

    SerialLog log(uart1);
    log.setStdout(true);

    log.info("===== MicroLink Link Station ============");
    log.info("Copyright (c) 2025 Bruce MacKinnon KC1FSZ");

    if (watchdog_caused_reboot()) {
        log.info("WATCHDOG REBOOT");
    } else if (watchdog_enable_caused_reboot()) {
        log.info("WATCHDOG EANBLE REBOOT");
    } else {
        log.info("Normal reboot");
    }

    // ----- READ CONFIGURATION FROM FLASH ------------------------------------

    // The very last sector of flash is used. Compute the memory-mapped address, 
    // remembering to include the offset for RAM
    const uint8_t* addr = (uint8_t*)(XIP_BASE + (PICO_FLASH_SIZE_BYTES - FLASH_SECTOR_SIZE));
    auto config = (const StationConfig*)addr;
    if (config->version != CONFIG_VERSION) {
        // Setup the default configuration 
        setDefaultConfig();        
    } 

    HostName ourAddressingServerHost(config->addressingServerHost);
    CallSign ourCallSign;
    FixedString ourPassword;
    FixedString ourFullName;
    FixedString ourLocation;
    ourCallSign = CallSign(config->callSign);
    ourPassword = FixedString(config->password);
    ourFullName = FixedString(config->fullName);
    ourLocation = FixedString(config->location);

    log.info("EL Addressing Server : %s:%lu", ourAddressingServerHost.c_str(),
        config->addressingServerPort);
    log.info("Identification       : %s/%s/%s", ourCallSign.c_str(),
        ourFullName.c_str(), ourLocation.c_str());
    log.info("Idle Timeout (s)     : %d", config->idleTimeoutS);
    log.info("Silent Timeout (s)   : %d", config->silentTimeoutS);
    log.info("ADC offset           : %d", config->adcRawOffset);

    bool networkState = false;
    IPAddress currentIp;

    // ====== Internet Connectivity Stuff =====================================
    LwIPLib::traceLevel = 0;
    if (cyw43_arch_init_with_country(CYW43_COUNTRY_USA)) {
        log.error("Failed to initialize WIFI");
    } else {
        cyw43_arch_enable_sta_mode();
        //cyw43_arch_wifi_connect_async(config->wifiSsid, config->wifiPassword, 
        //    CYW43_AUTH_WPA2_AES_PSK);
    }
    LwIPLib ctx(&log);
    // ====== Internet Connectivity Stuff =====================================

    /*
    // ====== Internet Connectivity Stuff =====================================
    // UART0 setup (SIM7600)
    uart_init(uart0, 115200);
    gpio_set_function(UART0_TX_PIN, GPIO_FUNC_UART);
    gpio_set_function(UART0_RX_PIN, GPIO_FUNC_UART);
    uart_set_hw_flow(uart0, false, false);
    uart_set_format(uart0, U_DATA_BITS, U_STOP_BITS, U_PARITY);
    uart_set_fifo_enabled(uart0, true);
    uart_set_translate_crlf(uart0, false);

    SIM7600IPLib::traceLevel = 1;
    uint8_t rxBufferArea[256];
    uint8_t txBufferArea[256];
    PicoUartChannel uartCtx(uart0, rxBufferArea, 256, txBufferArea, 256);
    SIM7600IPLib ctx(&log, &uartCtx, SIM7600_EN_PIN);
    ctx.reset();

    // SIM7600 module reset.
    // Per the schematic for the "hat" board, the reset is 
    // active high.
    //gpio_init(SIM7600_EN_PIN);
    //gpio_put(SIM7600_EN_PIN, 1);
    //gpio_set_dir(SIM7600_EN_PIN, GPIO_OUT);
    
    // ====== Internet Connectivity Stuff =====================================
    */

    TestUserInfo info;

    // ===== Audio Stuff ======================================================
    // NOTE: Audio is encoded and decoded in 4-frame chunks.
    I2CAudioOutputContext radio0Out(audioFrameSize * 4, sampleRate, 
        audioBufDepthLog2, audioBuf, &info);
    // ADC/audio in setup
    PicoAudioInputContext::setup();
    PicoAudioInputContext radio0In;
    // Connect the input (ADC) timer to the output (DAC)
    radio0In.setSampleCb(I2CAudioOutputContext::tickISR, &radio0Out);
    radio0In.setRawOffset(config->adcRawOffset);

    // Analyzers for sound data
    int16_t txAnalyzerHistory[2048];
    AudioAnalyzer txAnalyzer(txAnalyzerHistory, 2048, sampleRate);
    radio0Out.setAnalyzer(&txAnalyzer);

    int16_t rxAnalyzerHistory[2048];
    AudioAnalyzer rxAnalyzer(rxAnalyzerHistory, 2048, sampleRate);
    radio0In.setAnalyzer(&rxAnalyzer);
    rxAnalyzer.setEnabled(true);

    //int16_t dtmfDetectorHistory[400];
    //DTMFDetector dtmfDetector(dtmfDetectorHistory, 400, sampleRate);
    DTMFDetector dtmfDetector(sampleRate);

    // The RXMonitor is basically a gate between the rig's receiver
    // and the Conference.  
    RXMonitor rxMonitor;
    rxMonitor.setInfo(&info);
    // RXMonitor -> DTMF detector
    // Disabled for now for speed reasons.  Will review and optimize.
    //rxMonitor.setDTMFDetector(&dtmfDetector);

    // Radio RX -> RXMonitor
    radio0In.setSink(&rxMonitor);
    // ===== Audio Stuff ======================================================

    DNSMachine dnsMachine1(&ctx, &info, &log, DNS_INTERVAL_MS);
    ctx.addEventSink(&dnsMachine1);
    dnsMachine1.setHostName(ourAddressingServerHost);

    DNSMachine dnsMachine2(&ctx, &info, &log, DNS_INTERVAL_MS);
    ctx.addEventSink(&dnsMachine2);
    //dnsMachine2.setHostName(MONITOR_SERVER_NAME);

    // TODO: MOVE THIS TO CONFIG
    //FixedString versionId("1.06B");
    //FixedString emailAddr("bruce@mackinnon.com");
    FixedString versionId(VERSION_ID);
    FixedString emailAddr;

    LogonMachine2 logonMachine(&ctx, &log, &dnsMachine1, versionId);
    ctx.addEventSink(&logonMachine);
    logonMachine.setServerPort(config->addressingServerPort);
    logonMachine.setCallSign(ourCallSign);
    logonMachine.setPassword(ourPassword);
    logonMachine.setLocation(ourLocation);
    logonMachine.setEmailAddr(emailAddr);

    LookupMachine3 lookup(&ctx, &log);
    ctx.addEventSink(&lookup);
    lookup.setServerName(ourAddressingServerHost);
    lookup.setServerPort(config->addressingServerPort);

    ConferenceBridge confBridge(&ctx, &info, &log, &radio0Out);
    ctx.addEventSink(&confBridge);

    Conference conf(&lookup, &confBridge, &log, &dnsMachine1, &dnsMachine2);
    conf.setCallSign(ourCallSign);
    conf.setFullName(ourFullName);
    conf.setLocation(ourLocation);
    conf.setSilentTimeoutS(config->silentTimeoutS);
    conf.setIdleTimeoutS(config->idleTimeoutS);

    confBridge.setConference(&conf);
    lookup.setConference(&conf);
    rxMonitor.setSink(&confBridge);
    logonMachine.setConference(&conf);

    SNTPClient sntpClient(&log, &ctx);
    ctx.addEventSink(&sntpClient);

    bool rigKeyState = false;
    timestamp lastRigKeyTransitionTime;
    timestamp rigKeyLockoutTime;
    uint32_t rigKeyLockoutCount = 0;

    timestamp lastCosOn;
    timestamp lastCosTransition;
    bool cosState = false;
    bool lastCosState = false;

    int startupMode = 2;
    timestamp startupTime = time_ms();

    bool inContactWithMonitor = false;

    PicoPollTimer renderTimer;
    renderTimer.setIntervalUs(500000);
    PicoPollTimer flashTimer;
    flashTimer.setIntervalUs(250 * 1000);
    bool flashState = false;
    PicoPollTimer secondTimer;
    secondTimer.setIntervalUs(1000 * 1000);

    const uint32_t dtmfAccumulatorSize = 16;
    char dtmfAccumulator[dtmfAccumulatorSize];
    uint32_t dtmfAccumulatorLen = 0;
    timestamp lastDtmfActivity;

    // Register the physical radio into the conference
    conf.addRadio(CallSign("RADIO0"), IPAddress(0xff000002));
    radio0In.setADCEnabled(true);
    
    NetworkTask wifiPollTask;

    // These are all of the tasks that need to be run on every iteration
    // of the main loop.
    const uint32_t taskCount = 13;
    Runnable* loopTasks[taskCount] = {
        &wifiPollTask,
        &ctx,
        &dnsMachine1,
        &dnsMachine2,
        &logonMachine,
        &lookup,
        &confBridge,
        // 7
        &conf,
        // 8
        &radio0Out,
        // 9
        &radio0In,
        // 10
        &rxMonitor,
        // 11
        &log,
        // 12
        &sntpClient
    };

    // Performance metrics
    uint32_t maxTaskTimeUs[taskCount];
    for (uint32_t i = 0; i < taskCount; i++)
        maxTaskTimeUs[i] = 0;
    PicoPerfTimer taskTimer;

    PicoPerfTimer cycleTimer;
    uint32_t longestCycleUs = 0;

    // ===== Command Shell Stuff =============================================

    enum ShellMode {
        LOG,
        PROMPT,
        STATUS,
        QUIT
    } shellMode = ShellMode::LOG;

    LinkOutStream shellOut;
    LinkCommandSink shellSink;
    CommandShell shell;
    shell.setOutput(&shellOut);
    shell.setSink(&shellSink);
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

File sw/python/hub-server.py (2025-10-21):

import time
import requests
import socket
import random
from enum import Enum
import base64
import hashlib
from cryptography.hazmat.primitives import hashes
from cryptography.hazmat.primitives.asymmetric import padding
from cryptography.hazmat.primitives.asymmetric import rsa
from cryptography.hazmat.primitives import serialization
from cryptography.exceptions import InvalidSignature
import scipy.io.wavfile as wavfile
import numpy as np
# TODO: THIS IS DEPRECATED!
import audioop

def is_full_frame(frame):
    return frame[0] & 0b10000000 == 0b10000000

def get_full_source_call(frame):
    return ((frame[0] & 0b01111111) << 8) | frame[1]

def get_full_r_bit(frame):
    return frame[2] & 0b10000000 == 0b10000000

def get_full_dest_call(frame):
    return ((frame[2] & 0b01111111) << 8) | frame[3]

def get_full_timestamp(frame):
    return (frame[4] << 24) | (frame[5] << 16) | (frame[6] << 8) | frame[7]

def get_full_outseq(frame):
    return frame[8]

def get_full_inseq(frame):
    return frame[9]

def get_full_type(frame):
    return frame[10]

def get_full_subclass_c_bit(frame):
    return frame[11] & 0b10000000 == 0b10000000

def get_full_subclass(frame):
    return frame[11] & 0b01111111

def make_call_token():
    # TODO: RANDOMIZE
    return "1759883232?e4b9017e102c1f831e6db6ab1bc85ebce1ea240e".encode("utf-8")

def make_information_element(id: int, content):
    result = bytearray()
    result += id.to_bytes(1, byteorder='big')
    result += len(content).to_bytes(1, byteorder='big')
    result += content
    return result

def encode_information_elements(ie_map: dict): 
    result = bytearray()
    for key in ie_map.keys():
        if not isinstance(key, int):
            raise Exception("Type error")
        result += make_information_element(key, ie_map[key])
    return result

def decode_information_elements(data: bytes):
    """
    Takes a byte array containing zero or more information elements
    and unpacks it into a dictionary. The key of the dictionary is 
    the integer element ID and the value of the dictionary is a byte
    array with the content of the element.
    """
    result = dict()
    state = 0
    working_id = 0
    working_length = 0
    working_data = None
    # Cycle across all data
    for b in data:
        if state == 0:
            working_id = b
            state = 1
        elif state == 1:
            working_length = b 
            working_data = bytearray()
            if working_length == 0:
                result[working_id] = working_data
                state = 0
            else:
                state = 2
        elif state == 2:
            working_data.append(b)
            if len(working_data) == working_length:
                result[working_id] = working_data
                state = 0
        else:
            raise Exception()
    # Sanity check - we should end in the zero state
    if state != 0:
        raise Exception("Data format error")
    return result

def is_NEW_frame(frame):
    return is_full_frame(frame) and \
        get_full_type(frame) == 6 and \
        get_full_subclass_c_bit(frame) == False and \
        get_full_subclass(frame) == 1

def is_ACK_frame(frame):
    return is_full_frame(frame) and \
        get_full_type(frame) == 6 and \
        get_full_subclass_c_bit(frame) == False and \
        get_full_subclass(frame) == 4

def is_HANGUP_frame(frame):
    return is_full_frame(frame) and \
        get_full_type(frame) == 6 and \
        get_full_subclass_c_bit(frame) == False and \
        get_full_subclass(frame) == 5

def make_frame_header(source_call: int, dest_call: int, timestamp: int, 
    out_seq: int, in_seq: int, frame_type: int, frame_subclass: int):
    result = bytearray()
    result += source_call.to_bytes(2, byteorder='big')
    result[0] = result[0] | 0b10000000
    result += dest_call.to_bytes(2, byteorder='big')
    result[2] = result[2] & 0b01111111
    result += timestamp.to_bytes(4, byteorder='big')
    result += out_seq.to_bytes(1, byteorder='big')
    result += in_seq.to_bytes(1, byteorder='big')
    # Type
    result += int(frame_type).to_bytes(1, byteorder='big')
    # Subclass
    result += int(frame_subclass).to_bytes(1, byteorder='big')
    return result

def make_CALLTOKEN_frame(source_call: int, dest_call: int, timestamp: int, 
    out_seq: int, in_seq: int, token):
    result = make_frame_header(source_call, dest_call, timestamp, out_seq, in_seq,
        6, 40)
    result += encode_information_elements({ 54: token })
    return result

def make_ACK_frame(source_call: int, dest_call: int, timestamp: int,
    out_seq: int, in_seq: int):
    result = make_frame_header(source_call, dest_call, timestamp, out_seq, in_seq,
        6, 4)
    return result

def make_AUTHREQ_frame(source_call: int, dest_call: int, timestamp: int,
    out_seq: int, in_seq: int, challenge: str):
    result = make_frame_header(source_call, dest_call, timestamp, out_seq, in_seq,
        6, 8)
    # Information elements
    result += encode_information_elements({ 
        14: int(4).to_bytes(2, byteorder='big'),
        15: challenge.encode("utf-8"), 
        6: "allstar-sys".encode("utf-8") 
    })
    return result

def make_ACCEPT_frame(source_call: int, dest_call: int, timestamp: int,
    out_seq: int, in_seq: int):
    result = make_frame_header(source_call, dest_call, timestamp, out_seq, in_seq,
        6, 7)
    # Information elements
    result += encode_information_elements({ 
        9: int(4).to_bytes(4, byteorder='big'),
        56: b'\x00\x00\x00\x00\x00\x00\x00\x00\x04'
    })
    return result

def make_RINGING_frame(source_call: int, dest_call: int, timestamp: int,
    out_seq: int, in_seq: int):
    result = make_frame_header(source_call, dest_call, timestamp, out_seq, in_seq,
        4, 3)
    return result

def make_ANSWER_frame(source_call: int, dest_call: int, timestamp: int,
    out_seq: int, in_seq: int):
    result = make_frame_header(source_call, dest_call, timestamp, out_seq, in_seq,
        4, 4)
    return result

def make_STOP_SOUNDS_frame(source_call: int, dest_call: int, timestamp: int,
    out_seq: int, in_seq: int):
    result = make_frame_header(source_call, dest_call, timestamp, out_seq, in_seq,
        4, 255)
    return result

def make_VOICE_frame(source_call: int, dest_call: int, timestamp: int,
    out_seq: int, in_seq: int, audio_block: bytes):
    result = make_frame_header(source_call, dest_call, timestamp, out_seq, in_seq,
        2, 4)
    result += audio_block
    return result
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

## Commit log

2024-01-24 Client flow working
2024-01-26 Testing on PICO
2024-01-29 Working on socket context
2024-01-29 SocketContext is starting to work, new client test
2024-01-29 Switched to NL order on IP address
2024-01-29 UDP working in SocketContext
2024-01-30 Working on audio chain
2024-01-31 Added some ESP32 stuff
2024-01-31 Added test case for talking to ESP32 AT commands
2024-02-03 Addressed some AT parsing problems
    [esp32at-test-2.cpp]
2024-02-06 Working on initial reset
    [client-test-2p.cpp]
2024-02-07 Added jitter-elimination
2024-02-08 Refactored SocketContext for Windows, now working on Windows (ECHOTEST)
2024-02-08 Seeing ADC queue add fails
    [PicoAudioInputContext.cpp, PicoAudioInputContext.h, client-test-2p.cpp]
2024-02-09 Refactor of ADC code (not tested yet)
2024-02-11 Working on fixing deadlock in UART TX path - NOT TESTED
    [PicoAudioInputContext.h, client-test-2p.cpp]
2024-02-12 Now enabling ADC for TX only, tested
2024-02-12 Working on remote linking test case - able to accept UDP traffic
2024-02-13 Schematic updates
2024-02-18 Working on PCB layout
    [AudioIn.kicad_sch, AudioOut.kicad_sch, ML0.kicad_pcb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]
2024-02-20 Working on V0 of the analog PCB
    [AudioIn.kicad_sch, AudioOut.kicad_sch, ML0.kicad_sch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]
2024-02-20 Working on PCB 0
    [AudioIn.kicad_sch, AudioOut.kicad_sch, ML0.kicad_sch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]
2024-02-21 Refactored RX path to enable DTMF in the future. Skipping Welcome after recent activity
    [I2CAudioOutputContext.cpp, PicoAudioInputContext.cpp, PicoAudioInputContext.h]
2024-02-24 Refactored _state management. Changed audio output to be driven by ADC clock. (NOT TESTED)
2024-02-25 Initial layout done
    [AudioIn.kicad_sch, AudioOut.kicad_sch, ML0.kicad_pcb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]
2024-02-25 Working on PCB
    [ML0.kicad_pcb]
2024-02-26 Improvements to board
    [AudioOut.kicad_sch, ML0.kicad_pcb]
2024-02-26 Board sent to JLC on 2024-02-26 09:18 EST
    [AudioIn.kicad_sch, AudioOut.kicad_sch, ML0.kicad_pcb]
2024-02-27 Working on debug of audio glitches
    [PicoAudioInputContext.cpp, PicoAudioInputContext.h]
2024-02-29 First board
    [AudioOut.kicad_sch]
2024-02-29 DTMF test case workig
2024-03-04 Working on Pico W integration
2024-03-05 Tested successfully on Pico W
2024-03-07 More testing, improved LED indicators and timeouts
2024-03-07 Avoiding logon before link comes up
    [link-main-2.cpp]
2024-03-07 Added monitor. needed to incrase UDP socket count
2024-03-09 System tested with V0 board
2024-03-09 V0 board has been tested
2024-03-09 Addressed a bug that caused session to drop during long transmission
    [link-main-2.cpp]
2024-03-19 Working on SIM7600, moved back to WIFI for testing. Made a change to the DC bias calculation to remove COS problem
    [PicoAudioInputContext.h, SIM7600IPLib.cpp, link-main-2.cpp]
2024-03-25 Added power pin for SIM7600
2024-03-27 Working well, added diagnostics, improved station limit case
2024-03-28 Working on ML1
    [AudioIn.kicad_sch, AudioOut.kicad_sch, ML1.kicad_pcb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]
2024-03-28 Re-work of ML1 board in process
    [AudioIn.kicad_sch, AudioOut.kicad_sch, ML1.kicad_pcb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]
2024-03-28 First draft of board is passing DRC
    [AudioIn.kicad_sch, AudioOut.kicad_sch, ML1.kicad_pcb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]
2024-03-28 Final checks, preparing to create GRB
    [AudioIn.kicad_sch, AudioOut.kicad_sch, ML1.kicad_pcb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]
2024-04-02 Added official BOM
    [bom.ods]
2024-04-04 Commiting SIM7600 code and switching back to WIFI
2024-04-09 Changed audio power calculation
2024-04-10 Added retry on validation to resolve a connect problem
    [link-main-2.cpp]
2024-04-10 PCB layout changes
    [AudioIn.kicad_sch, AudioOut.kicad_sch, ML2.kicad_pcb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]
2024-04-10 Board passing checks, ready for review
    [ML2.kicad_pcb, untitled.kicad_sch]
2024-04-10 Plot files generated for fab
    [ML2.kicad_pcb]
2024-04-10 Updated BOM
    [bom.ods]
2024-04-14 Working on packaging for ML3
    [AudioIn.kicad_sch, AudioOut.kicad_sch, ML3.kicad_pcb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]
2024-04-15 ML3 board modified for improved case/DFM. Sending this version to Steve
    [AudioIn.kicad_sch, AudioOut.kicad_sch, ML3.kicad_pcb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]
2024-04-16 Added documentation about isolation - no board changes
    [ML3.kicad_pcb]
2024-04-17 Added 3d models
    [3362P001XXX0A.stp, A-DF_09_A_KG-T2S.step, PJ-102AH.step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]
2024-04-17 V3 R1 incorporating connector moves from Steve
    [ML3.kicad_pcb]
2024-04-26 Updates for ML4
    [AudioIn.kicad_sch, AudioOut.kicad_sch, ML4.kicad_pcb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]
2025-09-25 Working on JCSC BOM
    [AudioIn.kicad_sch, AudioOut.kicad_sch, ML4.kicad_pcb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]
2025-09-30 Working on adding LCSC part numbers
    [AudioIn.kicad_sch, AudioOut.kicad_sch, ML4.kicad_pcb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]
2025-10-01 Working on ML4
    [AudioIn.kicad_sch, AudioOut.kicad_sch, ML4-bom.csv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]
2025-10-01 Working on docs
    [AudioOut.kicad_sch, untitled.kicad_sch]
2025-10-02 Cleaned up some build problems
    [link-main-2.cpp]
2025-10-06 Added breakout board for SA818 module
    [SA818-Breakout.kicad_pcb, SA818-Breakout.kicad_sch]
2025-10-07 Updating PCB
    [SA818-Breakout.kicad_pcb, SA818-Breakout.kicad_sch]
2025-10-07 Added LPF for harmonics
    [SA818-Breakout.kicad_pcb, SA818-Breakout.kicad_sch]
2025-10-08 Adding test case for AllStarLink
2025-10-09 Updated 50ohm traces
    [SA818-Breakout.kicad_pcb, SA818-Breakout.kicad_sch]
2025-10-22 New test case for SIP validation
2025-10-28 Added some traces for R&D

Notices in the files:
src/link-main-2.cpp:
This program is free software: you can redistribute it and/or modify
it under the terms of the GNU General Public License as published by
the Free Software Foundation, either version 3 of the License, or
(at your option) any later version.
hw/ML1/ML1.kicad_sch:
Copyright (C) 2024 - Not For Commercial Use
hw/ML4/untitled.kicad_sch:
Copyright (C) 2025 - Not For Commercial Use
